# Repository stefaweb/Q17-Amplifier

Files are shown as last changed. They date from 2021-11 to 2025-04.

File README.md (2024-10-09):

# Q17 : A QUAD405 audiophile MOSFET amplifier
Q17 is an amplifier based on the QUAD405 current dumping principle.

The project for porting the operating principle of the QUAD405 to a MOSFET base was originally created by engineer Tiberiu Vicol.

Use KiCad 8.0 or later to open and edit source files. KiCad 8.0 can be <a href="https://www.kicad.org/download/">downloaded</a> from CERN.

<b>Q17-Mini project 3.0 (90W @ 8 Ohms)</b>

The first version of the board was released on December 8, 2021.

Version 3.0.4 was published on October 7, 2024.

All files are located in Q17-Mini-3.0 directory. Old version are located in Q17-Mini Archives directory.

Q17-Mini v3.0 (95x75mm, 2 Oz PCB)
Q17-Mini-3 0-wood

<b>Q17-TURBO project (150W @ 8 Ohms)</b>

The natural evolution of the Q17-Mini, this time with two pairs of power transistors, better thermal management, better technical characteristics and the same sound signature with more punch.

An amplifier that will warm up even the coldest speakers.

The first version of the board was released on January, 6 2023.

Version 2.0.1 was released on October 5, 2024.

All files are located in Q17-TURBO-2.0 directory. Old version are located in Q17-TURBO Archives directory.

Q17-TURBO v2.0 (190x75mm, 2 Oz PCB)
Q17-Turbo-V2_wood

You can very simply manufacture your PCB via JLCPCB (https://jlcpcb.com) or PCBWay (https://www.pcbway.com) using the Gerber files available on this repository. You can also contact me, from time to time I have some spare copies of the Q17 PCBs that can be sold to you at cost price.

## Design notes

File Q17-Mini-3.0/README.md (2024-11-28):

# Q17-Mini version 3.0 (90W @ 8 Ohms)</b><br>

Q17-Mini-3 0-wood

<b>Technical specifications:</b>

THD: 0.011%<br>
S/N : 102 dB<br>
Intermodulation distortion: 0,2%<br>
Frequency response: ±0,2 dB<br>
Damping factor : 350 with 1.2Vrms sensibility, 290 with 0.7Vrms sensibility<br>
Default gain: 22 with input gain at 1.2Vrms, 35 with input gain at 0.7Vrms.<br>
DC offset at output: 1mV with OPA1611, 0mV with OPA828.<br>
Power supply : 50Vdc<br>
Idle consumption: 9W

These measurements were made with amateur measuring equipment. It is better to take them as an indication than as safe values. 
<br>
<br>
The first version of the board was released on December 8, 2021.
<br>
<br>
Version 3.0.4 was published on October 7, 2024.

Read the CHANGELOG file to know what's new.

<a href="https://audio.cyberkata.org/Q17-Mini-3.0-BOM.html">Q17-Mini-3.0-BOM Online Version</a>
<br>
<br>
<a href="https://www.mouser.fr/ProjectManager/ProjectDetail.aspx?AccessID=dd2b71abab">Order Q17-Mini-3.0.4-BOM at Mouser</a><br> 
<br>

Q17-Mini-3 0-stereo

Q17-Mini-schematic

Q17-Mini-3 0-spectrum

Q17-Mini-3 0_band

Q17-Mini-3 0_sweep_1W_configA4

PCB size: 95 mm * 75 mm

Q17-Mini-3D-FRONT

Q17-Mini-3D-BACK

Q17-Mini-PCB-FRONT

Q17-Mini-PCB-BACK

Drilling for Q17-Mini
Drilling diagram Q17-Mini v3

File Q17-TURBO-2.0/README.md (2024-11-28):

# Q17-TURBO (P2) 2.0</b><br>

<b>Q17-TURBO project (150W @ 8 Ohms).</b><br>

The natural evolution of the Q17-Mini, this time with two pairs of power transistors, better thermal management, better technical characteristics and the same sound signature with more punch.

An amplifier that will warm up even the coldest speakers.

<b>Technical specifications:</b>
</b>
THD: 0.01%<br>
S/N : 102 dB<br>
Intermodulation distortion: 0,2%<br>
Frequency response: ±0,2 dB<br>
Damping factor : 300<br>
Default gain: 26 with input gain at 1.2Vrms.<br>
DC offset at output: 1mV with OPA1611, 0mV with OPA828.<br>
Power supply : 60Vdc (56-60V)<br>
Idle consumption: 13W

These measurements were made with amateur measuring equipment. It is better to take them as an indication than as safe values.

The first version of the board was released on January, 6 2023.

Version 2.0.1 was released on October 5, 2024.

Read the CHANGELOG file to know what's new.

All files are located in Q17-TURBO-2.0 directory. Old version files are located in Q17-TURBO Archives directory.

KiCad source - Q17-TURBO amplifier KiCad source files.<br>
Gerber-Q17-TURBO-[version].zip - production gerber files for Q17-TURBO amplifier.<br>
Q17-TURBO-schematic.pdf - schematic for Q17-TURBO amplifier.<br>
Q17-TURBO-BOM.html - interactive BOM for Q17-TURBO amplifier (to open with an Internet Navigator).<br>

<a href="https://audio.cyberkata.org/Q17-TURBO-BOM-2.0.html">Online Q17-TURBO-BOM-2.0</a><br>

<a href="https://www.mouser.fr/ProjectManager/ProjectDetail.aspx?AccessID=c6a0dfc411">Order Q17-TURBO-BOM-2.0-BOM at Mouser</a><br> 



Q17-TURBO-schematic

Q17-Turbo-2 0_spectrum-2 0 1

PCB size: 190 mm * 75 mm

Q17-TURBO-3D-FRONT

Q17-TURBO-3D-BACK

Q17-TURBO-PCB-FRONT

Q17-TURBO-PCB-BACK

Q17-TURBO-PCB

Mounting Plate for Q17-Turbo

216 x 80 mm

Fixing Plate-Q17-Turbo-216x80-1 0

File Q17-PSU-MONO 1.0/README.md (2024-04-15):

# Q17-PSU-MONO version 1.0<br>

Universal mono bridge Power Supply for Class B amplifiers.

Version 1.0 published on April 15, 2024.

<a href="https://audio.cyberkata.org/Q17-PSU-MONO-BOM.html">Online Q17-PSU-MONO-BOM</a><br>

Q17-PSU-MONO-3D-VIEW

Q17-PSU-MONO-SCHEMATIC

Q17-PSU-MONO-3D-TOP

Q17-PSU-MONO-PCB-FRONT

Q17-PSU-MONO-PCB-BACK

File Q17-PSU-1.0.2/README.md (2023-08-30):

# Q17-PSU version 1.0.2<br>

Universal Power Supply for Class B amplifiers.

Version 1.0.2 published on August 29, 2023.

<a href="https://audio.cyberkata.org/Q17-PSU-BOM.html">Online Q17-PSU-BOM</a><br>



Q17-PSU-3D

Q17-PSU-schematic

Q17-PSU-PCB-FRONT

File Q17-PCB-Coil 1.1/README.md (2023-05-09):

# Q17-PCB-Coil 1.1</b><br>
<br>
PCB coil 1.2uH based on Tibi footprint version L_17.3.<br>

pcb_coil_1 2uH

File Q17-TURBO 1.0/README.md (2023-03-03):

# Q17-TURBO (P2) 1.0</b><br>

<b>For the Q17-TURBO project (200W @ 8 Ohms).</b><br>

The natural evolution of the Q17-Mini, this time with two pairs of power transistors, better thermal management and the same technical characteristics and the same sound signature.

THD: 0.013%<br>
THD+N: 0.10%<br>
Gain: 25<br>
DC offset at output: 0.001v<br>
Power supply: 50-55vDC<br>
Idle consumption: 15W @ 240v<br>

<br>
The first version of the board was released on January, 6 2023.<br>
<br>
<br>
All files are located in Q17-TURBO directory:<br>
<br>
KiCad source - Q17-TURBO amplifier KiCad source files.<br>
Gerber-Q17-TURBO-[version].zip - production gerber files for Q17-TURBO amplifier.<br>
Q17-TURBO-schematic.pdf - schematic for Q17-TURBO amplifier.<br>
Q17-TURBO-BOM.html - interactive BOM for Q17-TURBO amplifier (to open with a Navigator).<br>
Q17-TURBO-Drilling.jpg - Drilling plan for heatsink.<br>
<br>
<a href="https://audio.cyberkata.org/Q17-TURBO-BOM.html">Q17-TURBO-BOM Online Version</a><br>
<br>

Q17-Turbo_top jpeg

Q17-Turbo_back

q17_on

Q17-TURBO-schematic

Q17-Turbo-THD2

Q17-TURBO-PCB-FRONT

Q17-TURBO-PCB-BACK

Q17-TURBO-PCB

Q17-TURBO-Drilling

PCB size: 190 x 75 mm, 2 Oz
Q17-TURBO-1 0

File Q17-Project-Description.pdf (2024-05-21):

Q17 - audiophile approach to perfect sound

Hard to prove statements:
I know what I saw ! Ufologist I know what I hear ! Audiophile

by audiophile Tiberiu Vicol & ChatGPT This document was updated on 09.May.2023

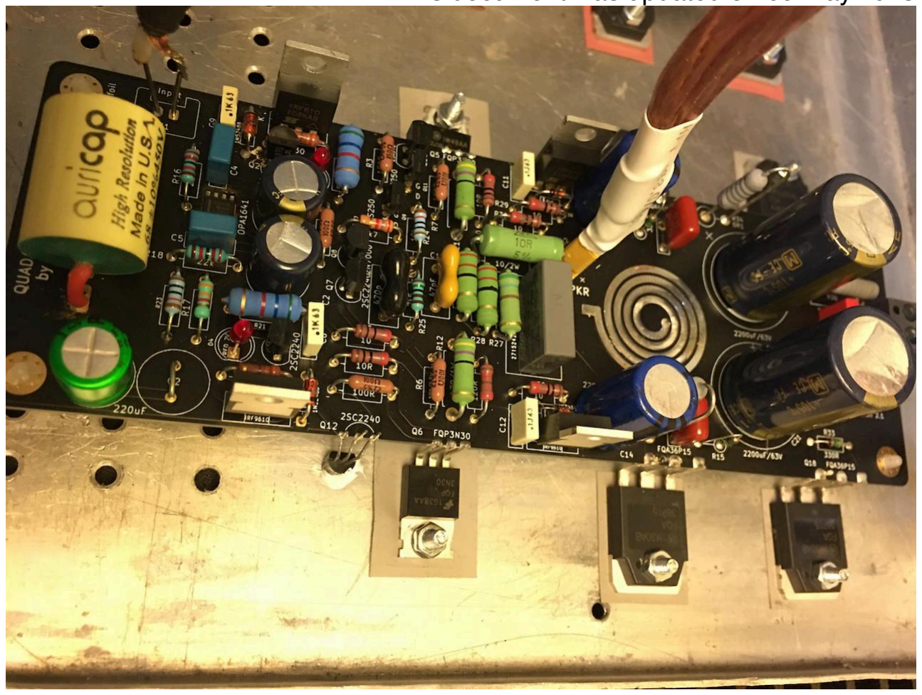
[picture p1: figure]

Introduction:

Q17 is a class B amplifier based on the current dumping principle.

Initial technical requirements:

- Stable operation: The amplifier must remain stable under any operational condition, with no oscillation.
- Minimum 100W in 8ohm at 1kHz: This should be sufficient for audiophiles with "impossible to drive" speakers.
- Frequency response cutoff of 10Hz - 100kHz: This will allow for a decent slew rate.

- IMD (Inter-Modulation Distortion) under 0.01%
- THD (Total Harmonic Distortion) under 0.01% at 1W and full power
- Design must be affordable, using readily available THT or SMD components or equivalents.
- Cost-effective and easy to build: High-end audio must be affordable.
- Open source: Let's offer everything - schematic, simulation, source PCB files, and bill of materials.
- Designed using LTspice simulation with final touch by extensive bench measurements and testing. Starting with KiCad 6.0.2, ngspice simulation is possible, and files have been made available by Holger Vogt: https://forum.kicad.info/t/simulation-examples-foricad-eeschema-ngspice/34443 (https://forum.kicad.info/t/simulation-examples-for-icad-eeschema-ngspice/34443)
- Final design decisions are always made using my platinum
ears. ;-) This means that Q17 is designed by comparing different topologies, and the final decision is taken not by measurement, but by listening. Q17 is indeed designed by ear. :-D

And here are the on-ear requirements:

Sound quality is of paramount importance. The amplifier must sound excellent at any level, without causing listening fatigue. The sound must be vivid, with a full body and plenty of harmonics with long decay, while maintaining resolution and clarity from top to bottom. Each instrument must sound natural, clearly separated, and easy to locate in space, even in large orchestras.

- No hiss or buzz: Poor rectification and filtering may result in unwanted noise.
- Microdynamic: This is challenging. The rhythm must be clear and distinct at any volume. I don't want flat, compressed, or lifeless sound. This is often related to negative feedback (NFB). In my opinion, NFB is only partially true, and it largely depends on how it is used along with other factors. High-quality power supply filter capacitors may also help.
- Macrodynamic linearity: The amplifier must be capable of going from low to high power levels instantly, without distortion or compression. It must provide the feeling of unlimited power. This is mainly related to the power supply. If the amplifier is capable of delivering power, the power supply must be able to handle it as well.

- Resolution: I prefer an amplifier that offers both resolution and fullbodied instruments, without losing harmonics and decay. Welldesigned single-ended direct-heated triodes (SEDHT) are capable of achieving this, and I want the same from my amplifier. I know this is another challenging requirement. Intermodulation distortion plays a role here. Low IMD always leads to top resolution, but sometimes musicality can be lost.

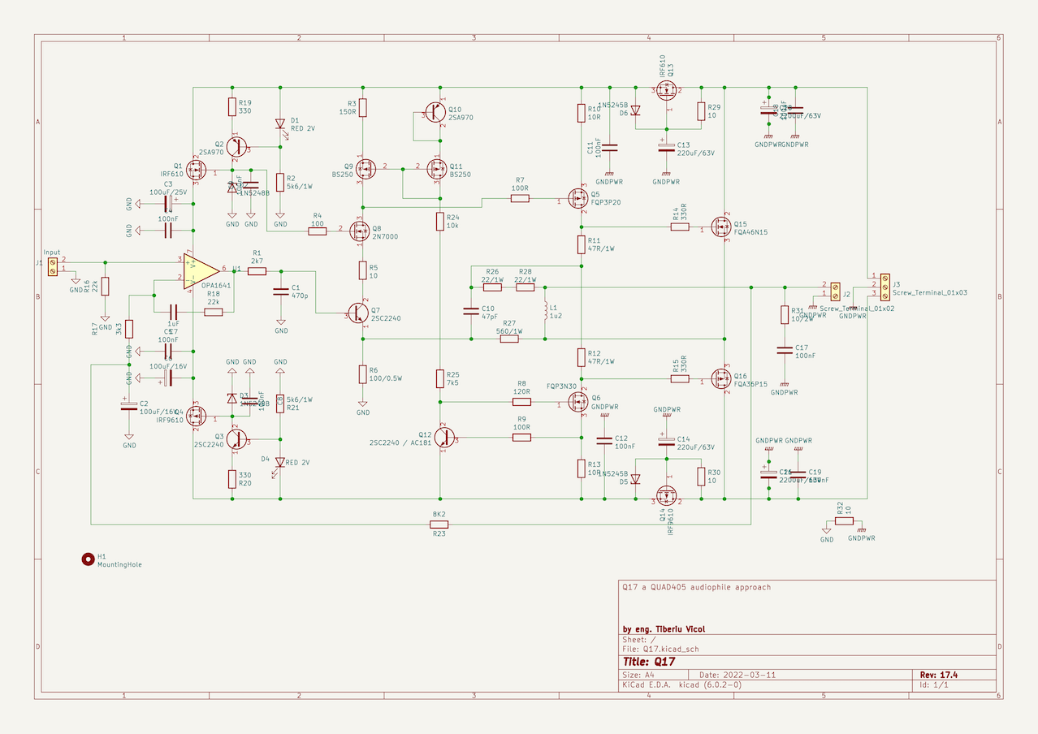
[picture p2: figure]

Q17 with output single pair of Fairchild’s

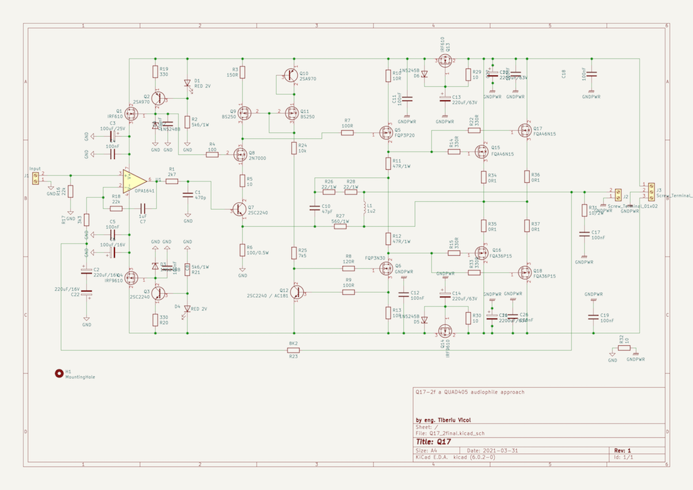
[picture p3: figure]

Q17 with output double pair of Fairchild’s

## Functional Description:

### Q17 is designed to deliver music at the highest audio performance, and

this design does not follow the "amplifier design book." Intentionally,

### the input is DC coupled, it has no input LPF, and does not make use of diodes or Vbs multiplier for thermal compensation. Q17 will run in class B, even though the output devices are MOSFETs with a very high Vgs

threshold. As far as I know, this has never been attempted before.

### Please correct me if I'm wrong. Q17 is divided into two separate

sections, which we will call Section One and Section Two.

Section One is made with the operational amplifier OPA1641. Today,

OPA1641 is one of the best opamps on the market. In fact, it is so good that a discrete circuitry will barely come close. OPA1641 is a JFET input operational amplifier that, apart from technical specifications, sounds very good and is cost-effective too. We are not driving a low impedance output, and there are no thermal issues. Those who do not like JFET

sound may try LME49990. This sounds great as well.

In my humble opinion, phase accuracy is very important. Therefore,

Q17 is not inverted and will preserve the original phase of the signal.

The input impedance is given by R16 = 22K. This is a good trade between high impedance and thermal resistor noise. You want higher input impedance? You can go as high as 47K. Use a good metal foil resistor here, and it should be enough. R17 and R18 are part of operational negative feedback and will set the gain to (R17+R18)/ R17=7.6. Many operational amplifiers will not be stable at low gain, and the stability limit is usually at a gain higher than 5. 7.6 will offer good

sensitivity, and we are on the safe side, away from any oscillation.

### Through R30, R25, and C3, the input operational will have a second role, acting as a DC servo. C3 must be bipolar, and I recommend using a good one like Nichicon MUSE. However, two normal polarized electrolytics connected in series will work just fine. For this use, low-

voltage electrolytics in the range of 6.3V-10VDC.

### R1C1 forms a low-pass filter with a cutoff frequency of 125kHz. This RC filter is the main load for the operational and will also limit the whole

amplifier's full bandwidth. C1 must be silver-mica or polystyrene.

### The operational is fed by two "reasonably low noise" regulators. The operational will not draw more than 10mA per raw, but its sonic

performance is highly dependent on the quality of these regulators. So,

### I have invested some time and parts to get the best topology for sound

versus price compromise.

Here is how it works. Regulation is ensured by 18V zeners D2 and D3, which are fed by a constant current source at around 4.2mA. Q2, D1,

### R19, and R2 (respectively Q3, D4, R20, and R21 for the negative rail) form a simple current source. D1 and D4 are red LEDs with Vf~2V. It is well-known that an LED is a reliable low-noise voltage reference. The current through the zener diode will be (LedVf-Q7Vbe)/R19 = (2-0.6)/330

= 4.2mA. This reference voltage is used by two MOSFETs, Q1 and Q4,

### respectively, to deliver higher current to OPA1641. IRF610/IRF9610 are a bit overkill here but are easy to find and cheap enough. These will run

warm but do not need a heatsink.

### Here is one of my first audiophile observations: MOSFET regulators sound better than bipolar regulators. They do not measure better, but

they sound better.

### Section two starts with a cascode formed by Q7 and Q8. This stage offers high gain, high output impedance, and high open-loop bandwidth

and may be a challenge to keep it out of oscillation. For this reason, R5 is there. This will lower the gain and increase stability at the cost of some distortion. In place of Q7, some inexpensive transistors BC5xx/ BC8xx can be used, as maxVce > 45V is the only restriction. From a sonic point of view, some cascodes may kill the "soul of music," in other words, offer a less vivid sound. Things are going far better if you use a MOSFET as the top active device. This will preserve dynamics at

any level.

### The cascode - Q7 & Q8 - stage has a high output impedance, therefore

it is fed by a constant current source made by Q10 and R3 at approx.

### 4.5mA. Q10 can be any low-cost, high-beta PNP BJT. Yes, any PNP, no

constraints.

### The CCS current is mirrored to Q12 by Q9 & Q11 through R24 & R25. In fact, the heart of Q17 is around this CCS+ current mirror. A current mirror that can be made with high-beta PNP transistors or P-channel MOSFET. You may need to pair these transistors to have same Vbe or

Vgs at ˜5mA.

I tried both. BJT mirror is very precise and offers a lush sound. For MOSFET, I used BS250P, and in this case, sound is deeper with a better midrange. Micro-dynamics seem to be higher too. After extensive listening sessions and some burn-in, I can confidently say that I will stay with MOSFET mirror. Take care of BS250P numbering termination as

this is different for manufacturers - see Vishay and Diodes.

### Instead of R24 & R25, you may use a single 1W resistor. This was split

in two to distribute power dissipated.

### Next is a class A stage. Here a single modern high-transconductance

MOSFET will do an excellent job, at the cost of some input capacitance.

### MOSFETs create more even-order harmonics compared to bipolar's too. As I care more about harmonic content than THD, here is my

preference for MOSFET.

### The quality of these MOSFETs may dramatically influence the amplifier's sonic signature, and these have been chosen after long

listening sessions.

### The P-channel MOSFET Q5 is a class-A active device, and from my observation, the P-channel FQP3P20 is slightly more linear than the Nchannel FQP3N30. However, at the current time (2021), we do not have

too many options. Toshiba's lateral MOSFETs (2SJ76, 2SJ77, 2SJ78,

### 2SJ79, and 2SK213, 2SK214, 2SK215, 2SK216) have long been obsolete. If you can source them, use them, but don't set your

expectations too high. These will not sonically exceed the FQP's.

### However, if you do use them, some capacitor compensation may be

needed to keep them from oscillating.

Q5 is fed by a 60mA CCS formed by Q12 and Q6. Q12 Vbe is the main reference in this CCS and can be used as thermal compensation for the final stage too. Again, there are no constraints for Q12. It can be any high-beta, low-voltage, NPN BJT. The CCS current can be calculated by Q12Vbe/R13 and would be around 60mA. This will push Q5's operation in class A and offer enough juice to drive the final dumper stage. Q5 and Q6 will dissipate 3W and must be mounted on a

heatsink.

### Q12 must also be mounted on a heatsink as it will be used to

compensate for final stage thermal runaway.

### Changing R13 to 2 ohms, a germanium AC181 can be used here as better temperature compensation. I must mention that this mod will not bring "germanium sound" into this amplifier. Sorry, germanium lovers!

### R9 is there as a base stopper and to avoid any possible oscillation. R7

and R8 are gate stoppers too.

### The Q17 amplifier runs in class B. There is no bias needed, and the Q17

amplifier may accept a very wide range of output MOSFET transistors.

Choosing the final pair Q15 & Q16.

I'm a big fan of lateral MOSFETs made by Semelab-Semefab-Exicon-Magnatec, whatever company is behind. This Scottish company is one of the last to make very good high-power lateral MOSFETs. I proudly used them in many amplifiers, and they sound exceptional. The main goal of Q17 is to be affordable, and these laterals, like many other good things, are not so cheap. They are very rugged and allow a high level of

"torture" and make things sometimes easy. No protections are needed.

### But... there is a "but." They have a small transconductance. You need to use double die and parallel a few of them to get some decent transconductance because audiophile speakers make use of

### complicated crossovers that like a lot of current in the most unexpected

frequencies.

Fairchild, now ON Semiconductor, was a great company and one of their legacies is FQA46N15 and FQA36P15. If you think these are P/N pairs, you are wrong. There is no such P/N perfect match in the real world, but we can choose the closest ones. These are marketed as "Fairchild Semiconductor's proprietary planar stripe and DMOS technology," with a small remark that they may be suitable for audio

amplifiers as well.

### FQA46N15 has a regular transconductance of 36 Siemens, while Exicon double die ECW20N20 has a maximum of 4 Siemens. This is equivalent to 9 double die laterals. Yes, very impressive! FQA36P15 has a regular transconductance of 19.5 Siemens, while Exicon double die ECW20P20

has a maximum of 4 Siemens. This is equivalent to 4 double die laterals.

In the "dark side" of Mouser, some beasts may leave these Fairchild's in the dust. These are made by IXYS, and a pair could be IXFK220N20X3 and IXTK120P20T. These exhibit over 120 Siemens of transconductance and are capable of transforming your amplifier into a real welding machine. No joke at all. If your speakers have never been

moved before, use a pair of these and shake your world, your walls, your neighbor...

### Through R11 and R12, these devices will be biased near class A operation. Both FQA46N15 and FQA36P15 have a Vgs - threshold voltage between 3V and 4V. I found that the P channel FQA36P15 will

open around 3V, while the FQA46N15 will need 100mV-300mV more.

### (To have both running at the same level, R11 may be increased to 51ohm or more.)

### Obviously, Q15 and Q16 must be mounted on a large heatsink. R31C17 is the well-known Zobel filter. C17 quality is important. Use a good propylene or polystyrene capacitor here. My preference is polystyrene Multicap RTX series. If you do not want to invest too much, go for

Arcotronix.

### R26, R27, R28, C10, and L1 form the current dumping bridge. R27 and R6 are part of section 2 negative feedback. This sets the entire amplifier gain to [(R17+R18)/R17]x[{R27+R6)/R6]=45.6, enough for the amplifier

to reach 100W/8ohm at 0.7V input.

### Q13 and Q14 are capacitor multipliers and are there to reduce power supply ripple. (These are not needed if you use synchronous rectification - see below.) During power on, the gate to source voltage on Q13 and Q14 may easily exceed 10V and may damage these

MOSFETs. For this reason, D5 and D6 are there to protect.

### You may have noticed that there are R4, R7, R8, R9, R14, and R15 as gate or base stoppers. I always prefer gate stoppers to compensate with capacitors. R32 will separate the signal ground plane from the

power ground plane. There are no special requirements for this one.

### Please note that R32 is 0ohm and not 10ohm as in presented

schematic.

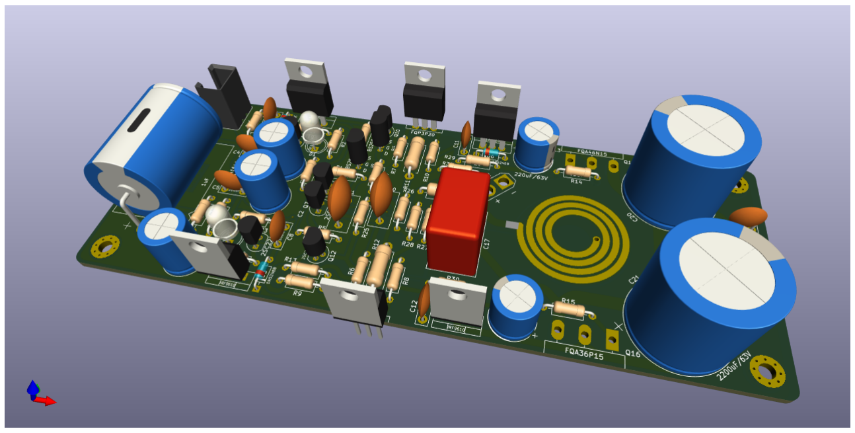
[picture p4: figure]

PCB design

During the COVID-19 lockdown, I had enough time to learn KiCad. KiCad runs on any operating system and is open source. This offers flexibility, scalability, and security. KiCad is a great tool.
I have designed this project in KiCad 5.99-nightly. To open the files, you need at least 5.99. This is already compatible with the upcoming KiCad 6, which is a huge step forward.
I opted for separate small and high signal ground planes. Ground planes are a good solution to avoid ground loops and offer excellent EMI reduction. For the best noise reduction, small signal GND makes use of top and bottom ground planes.
The PCB embeds an L1 inductor that is part of the error correction bridge. This will ensure good tolerance and optimal geometric design.

Yes, a PCB inductor will have the right shape for a near-to-ideal inductor. The truth is that I'm lazy to wire-wind coils. Having this embedded in the PCB will help lazy people like me a lot, but what I said earlier is still valid. A PCB coil is better. In a separate document, I have detailed how to create and embed inductors in KiCad.
The PCB offers the option to install several C7 types. Use propylene at any voltage > 50V. C17 must be propylene, preferably FKP, or polystyrene at a voltage > 100V.
OPA1641 is the single SMD part, and the PCB does not offer the option to install a THT one. But as long as I offer the source files for this project, you are invited to modify and redesign as you wish.

Bill of materials for Q17

D1,4 - LED RED 2V - https://ro.mouser.com/ProductDetail/Vishay-Semiconductors/TLHR5200?qs=GMckgg3bfZPthGr1cDR0RA%3D%3D (https://ro.mouser.com/ProductDetail/Vishay-Semiconductors/TLHR5200?qs=GMckgg3bfZPthGr1cDR0RA%3D%3D) D2,3 - 1N5248B - https://ro.mouser.com/ProductDetail/ON-Semiconductor-Fairchild/1N5248B?qs=G5AQjGfRJcJY58VFTX%252BkdQ%3D%3D (https://ro.mouser.com/ProductDetail/ON-Semiconductor-Fairchild/1N5248B?qs=G5AQjGfRJcJY58VFTX%252BkdQ%3D%3D)
D5,6 - 1N5245 - https://ro.mouser.com/ProductDetail/ON-Semiconductor-Fairchild/1N5245BTR?qs=jumAldekxNAufOthuRVeGQ%3D%3D (https://ro.mouser.com/ProductDetail/ON-Semiconductor-Fairchild/1N5245BTR?qs=jumAldekxNAufOthuRVeGQ%3D%3D)
Q7,12 - KSC1845 - https://ro.mouser.com/ProductDetail/ON-Semiconductor-Fairchild/KSC1845FTA?qs=UMEuL5FsraDCmxWozTypUA%3D%3D (https://ro.mouser.com/ProductDetail/ON-Semiconductor-Fairchild/KSC1845FTA?qs=UMEuL5FsraDCmxWozTypUA%3D%3D)
Q8 - 2N7000 - https://ro.mouser.com/ProductDetail/ON-Semiconductor-Fairchild/2N7000TA?qs=iN0KuJO79KZfCWVKA48bEg%3D%3D (https://ro.mouser.com/ProductDetail/ON-Semiconductor-Fairchild/2N7000TA?qs=iN0KuJO79KZfCWVKA48bEg%3D%3D)
Q2,Q10 - KSA992 - https://ro.mouser.com/ProductDetail/ON-Semiconductor-Fairchild/KSA992FBTA?qs=BiJXFBt7cx0C7PSFUPmr1w%3D%3D (https://ro.mouser.com/ProductDetail/ON-Semiconductor-Fairchild/KSA992FBTA?qs=BiJXFBt7cx0C7PSFUPmr1w%3D%3D)
Q9,11 - BS250P - https://ro.mouser.com/ProductDetail/Diodes-Incorporated/BS250P?qs=OlC7AqGiEDnRUFCQhRDfhA%3D%3D (https://ro.mouser.com/ProductDetail/Diodes-Incorporated/BS250P?qs=OlC7AqGiEDnRUFCQhRDfhA%3D%3D)
Q1,13 - IRF610 - https://ro.mouser.com/ProductDetail/Vishay-Siliconix/IRF610PBF-BE3?
qs=%2Fha2pyFadugbZUitPAu%252BTEPjT5SopLZ8qDnf9IMIvY8%3D (https://ro.mouser.com/ProductDetail/Vishay-Siliconix/IRF610PBF-BE3) Q4,14 - IRF9610 - https://ro.mouser.com/ProductDetail/Vishay-Semiconductors/IRF9610PBF?qs=cvaI6ThkwxtWoLkQbU%2FdsA%3D%3D (https://ro.mouser.com/ProductDetail/Vishay-Semiconductors/IRF9610PBF?qs=cvaI6ThkwxtWoLkQbU%2FdsA%3D%3D) Q5 - FQP3P20 - https://ro.mouser.com/ProductDetail/onsemi-Fairchild/FQP3P20?qs=mdiO5HdF0Ki1WoTNCOatYg%3D%3D (https://ro.mouser.com/ProductDetail/onsemi-Fairchild/FQP3P20?qs=mdiO5HdF0Ki1WoTNCOatYg%3D%3D)
Q6 - FQP3N30 - https://ro.mouser.com/ProductDetail/onsemi-Fairchild/FQP3N30?qs=FOlmdCx%252BAA1dVHDhvU%252BUcw%3D%3D (https://ro.mouser.com/ProductDetail/onsemi-Fairchild/FQP3N30?qs=FOlmdCx%252BAA1dVHDhvU%252BUcw%3D%3D)
Q15 - FQA46N15 - https://ro.mouser.com/ProductDetail/ON-Semiconductor-Fairchild/FQA46N15?
qs=%2Fha2pyFaduimCeOyuw0xouriGUKJcVVjoz%2FqQ0BKQtc%3D (https://ro.mouser.com/ProductDetail/ON-Semiconductor-Fairchild/FQA46N15) Q16 - FQA36P15 - https://ro.mouser.com/ProductDetail/ON-Semiconductor-Fairchild/FQA36P15?
qs=%2Fha2pyFadugPFcM3hvKrsP2cJsnMpKcpv1XDSGf5JCo%3D (https://ro.mouser.com/ProductDetail/ON-Semiconductor-Fairchild/FQA36P15)

U1 - OPA1641 - https://ro.mouser.com/ProductDetail/Texas-Instruments/OPA1641AIDR?
qs=sGAEpiMZZMutXGli8Ay4kFRPeV04IrZfqfNgaiEGnmE%3D (https://ro.mouser.com/ProductDetail/Texas-Instruments/OPA1641AIDR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)

C17 - 100nF - https://ro.mouser.com/ProductDetail/KEMET/R76MI31005050J?qs=pUKx8fyJudAaVipAdJ8Rqw%3D%3D (https://ro.mouser.com/ProductDetail/KEMET/R76MI31005050J?qs=pUKx8fyJudAaVipAdJ8Rqw%3D%3D) C4,5,8,9,11,12,18,19 - 100nF - https://ro.mouser.com/ProductDetail/KEMET/PHE426DJ6100JR05?qs=PoZJcSwa6DzVkLIswxOBtw%3D%3D (https://ro.mouser.com/ProductDetail/KEMET/PHE426DJ6100JR05?qs=PoZJcSwa6DzVkLIswxOBtw%3D%3D)
C10 - 47pF - https://ro.mouser.com/ProductDetail/Cornell-Dubilier-CDE/CD15ED470JO3?qs=JlSiUoO6twmzsCndHIj%2FhA%3D%3D (https://ro.mouser.com/ProductDetail/Cornell-Dubilier-CDE/CD15ED470JO3?qs=JlSiUoO6twmzsCndHIj%2FhA%3D%3D)
C7 - 1uF - https://ro.mouser.com/ProductDetail/Cornell-Dubilier-CDE/930C1W1K-F?qs=oi6qnwyrdkzUKQFAck35kQ%3D%3D (https://ro.mouser.com/ProductDetail/Cornell-Dubilier-CDE/930C1W1K-F?qs=oi6qnwyrdkzUKQFAck35kQ%3D%3D)
C1 - 470pF - https://ro.mouser.com/ProductDetail/Cornell-Dubilier-CDE/CD15FD471JO3F?qs=FKrQhPEeH%252B6Y%2FhdJiMfeDw%3D%3D (https://ro.mouser.com/ProductDetail/Cornell-Dubilier-CDE/CD15FD471JO3F?qs=FKrQhPEeH%252B6Y%2FhdJiMfeDw%3D%3D) C2 - 100uF BP - https://ro.mouser.com/ProductDetail/Nichicon/UES1C101MPM1TD?qs=JgOBn5pVFoqelxyCFlUB6Q%3D%3D (https://ro.mouser.com/ProductDetail/Nichicon/UES1C101MPM1TD?qs=JgOBn5pVFoqelxyCFlUB6Q%3D%3D)
C3,6 - 100uF/25V - https://ro.mouser.com/ProductDetail/Vishay-Sprague/510DX107M025CC2D?qs=j9BvaggtyN3XWy0%2FfD7iig%3D%3D (https://ro.mouser.com/ProductDetail/Vishay-Sprague/510DX107M025CC2D?qs=j9BvaggtyN3XWy0%2FfD7iig%3D%3D) C13,14 - 220uF/63V - https://ro.mouser.com/ProductDetail/Vishay-BC-Components/MAL215058221E3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 (https://ro.mouser.com/ProductDetail/Vishay-BC-Components/MAL215058221E3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) C15,16,20,21 - 2200uF/63V - https://ro.mouser.com/ProductDetail/Nichicon/UPW1J222MHD?
qs=sGAEpiMZZMvwFf0viD3Y3V%252BktQc2dZjNU8%252BcKz5%2FjOU%3 D (https://ro.mouser.com/ProductDetail/Nichicon/UPW1J222MHD)

R1 - 2k7 - https://ro.mouser.com/ProductDetail/Vishay-Dale/CCF072K70JKE36?qs=QKEOZdL6EQrf8lXj1m%2FHqg%3D%3D (https://ro.mouser.com/ProductDetail/Vishay-Dale/CCF072K70JKE36?qs=QKEOZdL6EQrf8lXj1m%2FHqg%3D%3D) R2,21 - 5k6 - https://ro.mouser.com/ProductDetail/Vishay-BC-Components/PR01000105601JR500?qs=LCMWAU1DZcyMK8Yz0ZAhmQ%3D%3D (https://ro.mouser.com/ProductDetail/Vishay-BC-Components/PR01000105601JR500?qs=LCMWAU1DZcyMK8Yz0ZAhmQ%3D%3D) R24 - 10k - https://ro.mouser.com/ProductDetail/Vishay-Beyschlag/MBB02070C1002FRP00?qs=Jr4%2Ft4s12JUmAfKOFUNhig%3D%3D (https://ro.mouser.com/ProductDetail/Vishay-Beyschlag/MBB02070C1002FRP00?qs=Jr4%2Ft4s12JUmAfKOFUNhig%3D%3D) R3 - 150ohm - https://ro.mouser.com/ProductDetail/Vishay-Dale/CCF07150RJKE36?qs=Ad%252BIW%2FmDqmUeNbXSTmV5ZQ%3D%3D (https://ro.mouser.com/ProductDetail/Vishay-Dale/CCF07150RJKE36?qs=Ad%252BIW%2FmDqmUeNbXSTmV5ZQ%3D%3D) R5,10,13,29,30,32 - 10ohm - https://ro.mouser.com/ProductDetail/Vishay-Dale/CCF0710R0GKE36?qs=QKEOZdL6EQpP4bkfADZzbQ%3D%3D (https://ro.mouser.com/ProductDetail/Vishay-Dale/CCF0710R0GKE36?qs=QKEOZdL6EQpP4bkfADZzbQ%3D%3D) R4,6,7,9 - 100ohm - https://ro.mouser.com/ProductDetail/Vishay-Dale/CCF07100RJKE36?qs=NQWA6AwZmkMW4Ul%252BG32rNg%3D%3D (https://ro.mouser.com/ProductDetail/Vishay-Dale/CCF07100RJKE36?qs=NQWA6AwZmkMW4Ul%252BG32rNg%3D%3D) R8 - 120ohm - https://ro.mouser.com/ProductDetail/Vishay-Dale/CCF07120RGKE36?qs=QKEOZdL6EQrffKbi7vq1lg%3D%3D (https://ro.mouser.com/ProductDetail/Vishay-Dale/CCF07120RGKE36?qs=QKEOZdL6EQrffKbi7vq1lg%3D%3D)
R11,12 - 47ohm/2W - https://ro.mouser.com/ProductDetail/Vishay-Dale/CCF0247R0JKE36?qs=QKEOZdL6EQqc7KTqtOG%2FUA%3D%3D (https://ro.mouser.com/ProductDetail/Vishay-Dale/CCF0247R0JKE36?qs=QKEOZdL6EQqc7KTqtOG%2FUA%3D%3D) R16,18 - 22k - https://ro.mouser.com/ProductDetail/Vishay-Dale/CCF0722K0JKE36?qs=Ad%252BIW%2FmDqmUs0WVMJaSusw%3D%3D (https://ro.mouser.com/ProductDetail/Vishay-Dale/CCF0722K0JKE36?qs=Ad%252BIW%2FmDqmUs0WVMJaSusw%3D%3D)

R17 - 3K3 - https://ro.mouser.com/ProductDetail/Vishay-Dale/CCF073K30GKE36?qs=QKEOZdL6EQqcBZBx6GnZnQ%3D%3D (https://ro.mouser.com/ProductDetail/Vishay-Dale/CCF073K30GKE36?qs=QKEOZdL6EQqcBZBx6GnZnQ%3D%3D) R14,15,19,20,22 - 330ohm - https://ro.mouser.com/ProductDetail/Vishay-Dale/CCF07330RJKE36?qs=pkalMaiJWwv10%252BO%252BONxDWg%3D%3D (https://ro.mouser.com/ProductDetail/Vishay-Dale/CCF07330RJKE36?qs=pkalMaiJWwv10%252BO%252BONxDWg%3D%3D) R25 - 7K5 - https://ro.mouser.com/ProductDetail/Vishay-Dale/CCF077K50GKE36?qs=QKEOZdL6EQqRpabQIgr10Q%3D%3D (https://ro.mouser.com/ProductDetail/Vishay-Dale/CCF077K50GKE36?qs=QKEOZdL6EQqRpabQIgr10Q%3D%3D)
R23 - 8K2 - https://ro.mouser.com/ProductDetail/Vishay-Dale/CCF078K20GKE36?qs=QKEOZdL6EQrGlLmaSP0G2w%3D%3D (https://ro.mouser.com/ProductDetail/Vishay-Dale/CCF078K20GKE36?qs=QKEOZdL6EQrGlLmaSP0G2w%3D%3D)
R31 - 10ohm/2W - https://ro.mouser.com/ProductDetail/TE-Connectivity-Neohm/RR02J10RTB?qs=s1WWODT2SXW%252BZIrISq22ow%3D%3D (https://ro.mouser.com/ProductDetail/TE-Connectivity-Neohm/RR02J10RTB?qs=s1WWODT2SXW%252BZIrISq22ow%3D%3D) R26,28 - 22ohm - https://ro.mouser.com/ProductDetail/Vishay-Beyschlag/MBB02070C2209FCT00?
qs=sGAEpiMZZMsPqMdJzcrNwkfQgWkDJ%252BE2Mwj0n7JK2mo%3D (https://ro.mouser.com/ProductDetail/Vishay-Beyschlag/MBB02070C2209FCT00) R27 - 560ohm/1W - https://ro.mouser.com/ProductDetail/Ohmite/OM5615E-R58?
qs=sGAEpiMZZMukHu%252BjC5l7YREnR%2FWY87i1xVQq21Ltfa0%3D (https://ro.mouser.com/ProductDetail/Ohmite/OM5615E-R58)

J1 - input connector - https://www.hz-profishop.com/product_info.php?info=p701_mks-1651-6-0-202-s18--schwarz-.html (https://www.hz-profishop.com/product_info.php?info=p701_mks-1651-6-0-202-s18--schwarz-.html)
J2 - speaker output connector- https://ro.mouser.com/ProductDetail/DFRobot/FIT0586?qs=w%2Fv1CP2dgqouWR8IxqIK1w%3D%3D (https://ro.mouser.com/ProductDetail/DFRobot/FIT0586?qs=w%2Fv1CP2dgqouWR8IxqIK1w%3D%3D)
J3 - terminal block x 3 - https://ro.mouser.com/ProductDetail/Amphenol/TC0303620000G?qs=Mv7BduZupUgRMrlfdnWHCQ%3D%3D (https://ro.mouser.com/ProductDetail/Amphenol/TC0303620000G?qs=Mv7BduZupUgRMrlfdnWHCQ%3D%3D)

Extra parts for Q17-2f (Q17 amplifier with two output pairs)
R22, R33 - 330ohm https://ro.mouser.com/ProductDetail/Vishay-Dale/CCF07330RJKE36?qs=pkalMaiJWwv10%252BO%252BONxDWg%3D%3D (https://ro.mouser.com/ProductDetail/Vishay-Dale/CCF07330RJKE36?qs=pkalMaiJWwv10%252BO%252BONxDWg%3D%3D) R34,35,36,37 - 0.1ohm/3W https://ro.mouser.com/ProductDetail/TE-Connectivity-Holsworthy/ROX3SJR10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 (https://ro.mouser.com/ProductDetail/TE-Connectivity-Holsworthy/ROX3SJR10)
Q17 - FQA46N15 - https://ro.mouser.com/ProductDetail/ON-Semiconductor-Fairchild/FQA46N15?
qs=%2Fha2pyFaduimCeOyuw0xouriGUKJcVVjoz%2FqQ0BKQtc%3D (https://ro.mouser.com/ProductDetail/ON-Semiconductor-Fairchild/FQA46N15) Q18 - FQA36P15 - https://ro.mouser.com/ProductDetail/ON-Semiconductor-Fairchild/FQA36P15?
qs=%2Fha2pyFadugPFcM3hvKrsP2cJsnMpKcpv1XDSGf5JCo%3D (https://ro.mouser.com/ProductDetail/ON-Semiconductor-Fairchild/FQA36P15)

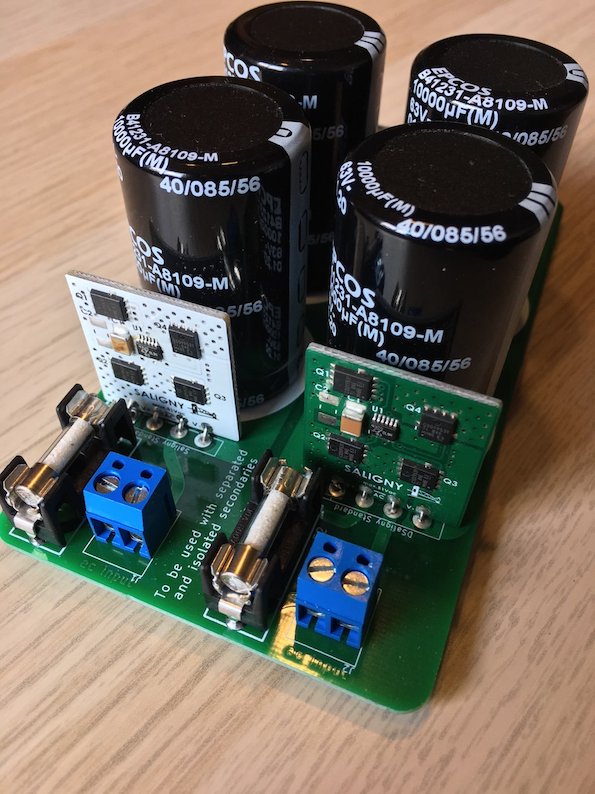
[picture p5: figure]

Active power supply

A good amplifier needs an exceptional power supply. All design efforts will be lost if we do not excel in this area too.

A diode is far from being a perfect device. There are no better devices, only better solutions.

Synchronous, or active rectification, has been available for a long time in professional appliances. The very first synchronous rectifier (mechanical rectifier) was used in the 1950s for high power and high voltage applications.

Its limited usage in consumer electronics was due to complexity and the very high cost involved. In recent years, thanks to green power requirements and electric vehicles, several dedicated chips have appeared in the consumer market. These mainly target PoE (power over Ethernet), but by choosing the right parts, the application can be extended to high-end audio as well.

A synchronous rectifier is a diode-less bridge employing modern MOSFET transistors that replace the four diodes in a full-wave bridge rectifier with a milliohm Rdson MOSFET, drastically reducing power dissipation, heat generation, voltage loss, and diode on/off switching noise. There is no P-N junction involved; only a low milliohm conductive channel is inserted in the power path. This allows for big current capability, better power management, less power loss, less dynamic impedance change versus load current, and better circuit performance than any available junction rectifier solution.

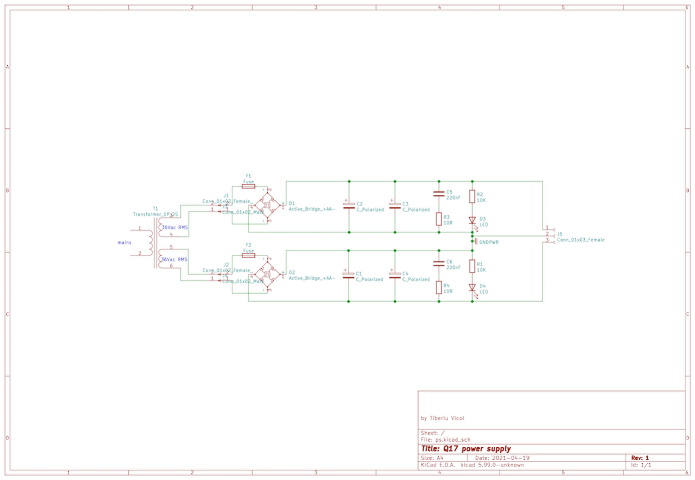
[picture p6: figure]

The advantage of using synchronous rectification is huge. While a normal diode has at least a 600mV drop at 1A, a low Rdson MOSFET will have as little as 3mV, or less, at the same 1A. This is 200 times better than a PN diode and at least 100 times better than a Schottky diode.

But how is this translated in audio? The most sensible difference is noise, due to synchronous rectifiers having negligible on/off noise. Each bridge MOSFET is acting like a soft on/off switch. The entire medium to top audio spectrum is cleaner. Voices are soft and cymbals full of harmonics. Another effect is better dynamics. The sound is more vivid because no power is lost in rectification or modulated by diode pn junctions, and the single current limiter is the intrinsic transformer resistance.

We make use of two Saligny Standard synchronous rectifiers made by Evotronix SRL. These are operated at 36Vac each, from a 300VA R-Core transformer. C1, C2, C3, C4 = 10000uF/63V are the main capacitor filters. There is a snubber formed with R3C5 and R4C6. This is needed only when normal diode bridge rectifiers are used. In our case with Saligny rectifiers, you may skip these parts. R2D3 and R1D4 are rail power indicators. A single power supply may be used for both Q17 modules, or two in case of a dual mono approach.

Bill of materials for power supply

J1,2 - terminal block x 2 - https://ro.mouser.com/ProductDetail/Amphenol/TC0203620000G?
qs=%2Fha2pyFaduhbuFfD6OHbCYxDpT0ma2Hwq0r2vPcUv6eC%2FlIp4UR n7Q%3D%3D (https://ro.mouser.com/ProductDetail/Amphenol/TC0203620000G)
J5,6 - terminal block x 3 - https://ro.mouser.com/ProductDetail/Amphenol/TC0303620000G?qs=Mv7BduZupUgRMrlfdnWHCQ%3D%3D (https://ro.mouser.com/ProductDetail/Amphenol/TC0303620000G?qs=Mv7BduZupUgRMrlfdnWHCQ%3D%3D)
C1,2,3,4 - 10.000uF/63V - https://ro.mouser.com/ProductDetail/EPCOS-TDK/B41231A8109M000?qs=f4aWRLuQiuxqY40YlReJiQ%3D%3D (https://ro.mouser.com/ProductDetail/EPCOS-TDK/B41231A8109M000?qs=f4aWRLuQiuxqY40YlReJiQ%3D%3D)
C5,6 - 220nF MKP - https://ro.mouser.com/ProductDetail/CDE-Illinois-Capacitor/MPX224K305E?qs=HXFqYaX1Q2wK3o1vUzHyKw%3D%3D (https://ro.mouser.com/ProductDetail/CDE-Illinois-Capacitor/MPX224K305E?qs=HXFqYaX1Q2wK3o1vUzHyKw%3D%3D) D1,2 - Synchronous Bridge - Saligny Standard - evotronix.eu
D3 - Red LED - https://ro.mouser.com/ProductDetail/Vishay-Semiconductors/TLHR5200?qs=GMckgg3bfZPthGr1cDR0RA%3D%3D (https://ro.mouser.com/ProductDetail/Vishay-Semiconductors/TLHR5200?qs=GMckgg3bfZPthGr1cDR0RA%3D%3D)
D4 - Green LED - https://ro.mouser.com/ProductDetail/Vishay-Semiconductors/TLHG5200?
qs=%2Fha2pyFadujruHm0H%252By%2FYe3hostfbxme%2F774XrUw9tU%3 D (https://ro.mouser.com/ProductDetail/Vishay-Semiconductors/TLHG5200)
R1,2 - - 10K/0,5W - https://ro.mouser.com/ProductDetail/Vishay-BC-Components/SFR16S0001002JA500?qs=H30XFsNYD%2FGypwPt5jX7ew%3D%3D (https://ro.mouser.com/ProductDetail/Vishay-BC-Components/SFR16S0001002JA500?qs=H30XFsNYD%2FGypwPt5jX7ew%3D%3D)
R3,4 - - 0 ohm - strap these if you use Saligny Standard
F1,2 - fuse holder - https://ro.mouser.com/ProductDetail/Littelfuse/0PTF0078P?qs=Co4VkB5J4%2Fsczy6gG8s%2FsA%3D%3D (https://ro.mouser.com/ProductDetail/Littelfuse/0PTF0078P?qs=Co4VkB5J4%2Fsczy6gG8s%2FsA%3D%3D) Transformer - *primary 2 x 115Vac region dependant* - secondary 36Vac + 36Vac at 5A

Selecting alternative parts
With current component shortage, it may happen that some parts listed in BOM to be unavailable, here are few alternative recommendations:
R16 - use a metal film resistor
C7 - use a good polypropylene made by Mundorf, Epcos, Vishay, CDC, U1 - following opamps can be used and will offer different sonic signatures: LME49710, LME49990, OPA604, OPA134, NE5534. Do not use TL071, TL081, LM301, LM741.
Q2 and Q3 - use transistors with Vce >= 65V & hFE>=100 : 2N5401 / 2N5551 Q7 and Q12 - other transistors that may be used are: KSC1845, 2N4401, BC546 / BC547 / BC548 / BC549 / BC550 - use the one with A termination for

Q7 and C termination for Q12.
C1 - this must be silver-mica or at least polystyrene.
Q1- KSA992, 2N4403, BC556C, BC557C, BC558C, BC559C, and BC560C C10 - silver-mica or ceramic NP0
R26, R27, R28 - these must be non-inductive resistors. MILLS make some good ones.
C17 - in this order: polystyrene, teflon, foil polypropilene, metalised polypropylene.
Q5 and Q6 - following pairs may be used with excellent performance: FQP3P50/FQP4N80; FQP4P40/FQP5N60
Q5 and Q6 - following pairs may be used with modest performance: IRF610/ IRF9610; IRF640/IRF9640; 2SJ76, 2SJ77, 2SJ78, 2SJ79 respectively 2SK213, 2SK214, 2SK215, 2SK216.
Q15,Q16,Q17,Q18 - following pairs can be used with modest performance IRFP9240/IRFP240; 2SJ201/2SK1530; 2SJ118/2SK413; 2SJ119/2SK414. Q9 and Q11 - Instead BS250 you may use ZVP3306A (https://ro.mouser.com/ProductDetail/Diodes-Incorporated/ZVP3306A?qs=vHuUswq2%252Bsyljxw%2Fl1wUQg%3D%3D)

Exicon ECW20N20 and ECW20P20 lateral MOSFET’s can NOT be used on this PCB. PCB need to be redesigned to accommodate lateral mosfet pinout.

Q17 Construction
Keep input shorted before any dc or static amplifier measurements. Static mean you only measure voltages in various places.
Start by installing operational and regulator with Q1-Q2-Q3-Q4. Next add Q13 and Q14 capacitor multipliers. Power up at and measure voltages before and after regulators. Before regulators you should measure +45Vdc/-46Vdc. After regulators you may expect around +13.5Vdc and -14Vdc
The two red LED, D1 and D4 must light on.
Mount the rest of parts, short input, power up and measure DC output. This must be under ~40mV.
Voltage across R3 and R13 must be between 500mV and 700mV. Voltage across R11 and R12 ~3V, a bit higher on R12.
If above measurements are OK, then you may connect Q17 amplifier to a preamplifier, potentiometer or volume controller. Connect output speakers trough a speaker protection module or a 3A fast fuse.
Take care and do not short the amplifier output. There is no protection, unless you have installed a separate one.
In some cases, a soft-start module is needed.

Building active power supply
For proper performance Q17 need a min.300VA transformer. There are E+I, C-core, R-core, Toroidal transformers. Any of them will work, but people ask which is the best. The best is the one that is the best constructed, using proper materials and well executed. However, from theoretical point of view, R-core exhibit lowest EM loss. A well executed R-core can be the best. Transformer must have dual separate secondary, 2 x 36Vac at min 5A.
Do not measure Saligny rectifiers without filter capacitors. Install all parts and measure when all is in place. Compared to any diode rectifier, Saligny rectifiers do not have voltage loss and you should get 36Vac x √2 = 50.9Vdc at active
Power supply output on each rail.

Measurements
Amplifier do not need specific adjustments and should work from the beginning. Please allow at least 48h for burn-in. Electrolytic capacitors are the most sensible at burn-in and some need 200h or more.
Mosfet transistors also need burn-in. My personal observation is that after 48h these are ok to go.
In order to perform burn-in, leave your amplifier powered ON. A musical program at low level will help as well.

What you should expect from this amplifier ?
Exceptional dynamics with superb harmonic extension. Strong and round bass. Exceptional midrange with crystal clear top response. Instrument separation localisation in deep 3D.
Enjoy & Thank you !

References and acknowledgements:
Current Dumping Audio Amplifier - PJ Walker - Wireless World, December 1975
Feedforward Error Correction in Power Amplifiers - Vanderkooy-Lipshitz Current dumping does it really work ? Theory and practice by J. Vanderkooy and S. P. Lipshitz University of Waterloo, Ontario
Current dumping analysis Class B amplifiers without crossover distorsion by H, S. Malvar, M. Sc. University of Brasilia
Test reports QUAD405 Current Dumping Amplifier by Gordon J. King Sources 101: Audio Current Regulator Tests for High Performance - Full Article by Walt Jung (https://audioxpress.com/authors/23384/walt-jung)

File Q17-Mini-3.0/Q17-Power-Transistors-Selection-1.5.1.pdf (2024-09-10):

Minimum Vds = 150V, same Vgs(th) range (4V), close transductance (Gfs). | Q7 v1.5.1
Config D2 | TESTED OK | | Status | Parts | Qg nC | Gfs Sie | Ciss pF | Vgs Volt | R7 | R8 | Freq MHz | R7 | R8 | Freq MHz | R7 | R8 | Freq MHz | OK | Comment
| Q5 | P | | FQPF7P20 | 25 | 3.5 | 770 | | 100 | | 2,06 | 93,95 | | 2,2 | 100 | | 2,2 | Yes
Q6 | N | EOL | 2SK3564 | 17 | 2.6 | 700 | 100 | 2,27 | 103,34 | 2,2 | 100 | 2,2 | Oscillation at 32V output with Q17-Turbo & S5.
Config D3 | TESTED OK | | Status | Parts | Qg nC | Gfs Sie | Ciss pF | Vgs Volt | R7 | R8 | Freq MHz | R7 | R8 | Freq MHz | R7 | R8 | Freq MHz | OK | Comment
| Q5 | P | | FQPF7P20 | 25 | 3.5 | 770 | | 100 | | 2,06 | 93,95 | | 2,2 | 100 | | 2,2 | Yes | Good with Q17-Turbo v2 & S5
| Q6 | N | | FQPF3N80C | 16.5 | 3 | 705 | | | 100 | 2,25 | | 108,55 | 2,2 | | 100 | 2,2 | | Overshoot with config S2.
Config D4 | TESTED | | Status | Parts | Qg nC | Gfs Sie | Ciss pF | Vgs Volt | R7 | R8 | Freq MHz | R7 | R8 | Freq MHz | R7 | R8 | Freq MHz | OK | Comment
| Q5 | P | | IRF9610 | 11 | 0.9 | 170 | | 100 | | 9,36 | 98,54 | | 9,5 | 100 | | 9 | Yes | The square signals are a little less nice
| Q6 | N | | IRF610 | 8.2 | 0.8 | 140 | | | 100 | 11,36 | | 119,66 | 9,5 | | 120 | 9 | | than with D2 configurations.
CANDIDATE | | Status | Parts | Qg nC | Gfs Sie | Ciss pF | Vgs Volt | R7 | R8 | Freq MHz | R7 | R8 | Freq MHz | R7 | R8 | Freq MHz | OK | Comment
Q5 | P | | IRFI9620G | 15 | 1,3 | 340 | | 100 | | 4,68 | 99,59 | | 4,7
Q6 | N | | IRFI620G | 14 | 1.5 | 260 | | | 100 | 6,12 | | 130,24 | 4,7

Minimum Vds = 150V, same Vgs(th) range (4V), close transductance (Gfs), Vgs(th) = loaded @ 18V170mA
Config S1 | DEFAULT | | Status | Parts | Qg nC | Gfs Sie | Ciss pF | Vgs Volt | R14 | R15 | Freq KHz | R14 | R15 | Freq KHz | R14 | R15 | Freq KHz | R10-R13 (R) | THD % | SNR -dBuA | OK | Comment | Subjective sound review
| Q15 | N | EOL | FQA46N15 | 110 | 36 | 2500 | 4.1 | 330 | | 192,92 | 335,06 | | 190 | 330 | | 190 | 9.1 | 0,011 | 90,9 | Yes | Original config | Good sound.
| Q16 | P | n.a | FQA36P15 | 105 | 19.5 | 2550 | 3.7 | | 330 | 189,13 | | 328,49 | 190 | | 330 | 190 | | | | | | Well balanced sound.
Config S2 | TESTED | | Status | Parts | Qg nC | Gfs Sie | Ciss pF | Vgs Volt | R14 | R15 | Freq KHz | R14 | R15 | Freq KHz | R14 | R15 | Freq KHz | R10-R13 (R) | THD % | SNR -dBuA | OK | Comment | Subjective sound review
| Q15 | N | EOL | FQA46N15 | 110 | 36 | 2500 | 4.1 | 330 | | 192,92 | 335,06 | | 190 | 330 | | 190 | 9.1 | 0,017 | 88,2 | No | Q14=3.6V, Q16=-3.8V - Bad spectrum. | Good sound.
| Q16 | P | | IXTH48P20P | 103 | 32 | 5400 | 4.2 | | 330 | 89,31 | | 155,12 | 190 | | 150 | 190 | | | | | With R10/R13=8R2 consume 400mA. | Low frequency drier than S5.
Config S3 | TO TEST | | Status | Parts | Qg nC | Gfs Sie | Ciss pF | Vgs Volt | R14 | R15 | Freq KHz | R14 | R15 | Freq KHz | R14 | R15 | Freq KHz | R10-R13 (R) | THD % | SNR -dBuA | OK | Comment | Subjective sound review
| Q15 | N | | IXTQ50N20P | 70 | 23 | 2720 | | 330 | | 177,31 | 307,96 | | 190 | | | | 9.1 | | | | 48v max.
| Q16 | P | | IXTQ52P10P | 60 | 20 | 2845 | | | 330 | 169,52 | | 294,43 | 190 | | | | | | | | Good to try at 35-40V.
Config S4 | TESTED | | Status | Parts | Qg nC | Gfs Sie | Ciss pF | Vgs Volt | R14 | R15 | Freq KHz | R14 | R15 | Freq KHz | R14 | R15 | Freq KHz | R10-R13 (R) | THD % | SNR -dBuA | OK | Comment | Subjective sound review
| Q15 | N | | IXTQ36N30P | 70 | 22 | 2250 | 4.8 | 330 | | 214,35 | 372,29 | | 190 | 374 | | 190 | 8.2 | 0,022 | 87.2 dB | No | Q14=3.6V, Q16=-3.8V | Good sound.
| Q16 | P | | IXTQ36P15P | 55 | 19 | 3100 | 4.1 | | 330 | 155,57 | | 270,21 | 190 | | 270 | 190 | | | | | With R10/R13=9R1 ou 8R2 - Bad spectrum. | Low frequency less controlled than S5.
Config S5 | TESTED OK | | Status | Parts | Qg nC | Gfs Sie | Ciss pF | Vgs Volt | R14 | R15 | Freq KHz | R14 | R15 | Freq KHz | R14 | R15 | Freq KHz | R10-R13 (R) | THD % | SNR -dBuA | OK | Comment | Subjective sound review
| Q15 | N | EOL | FQA46N15 | 110 | 36 | 2500 | 4.1 | 330 | | 192,92 | 335,06 | | 190 | 330 | | 190 | 8.2 | 0,011 | 91,1 | Yes | Q15/Q16 well balanced (3.6V). | Good sound.
| Q16 | P | | IXTQ36P15P | 55 | 19 | 3100 | 4.1 | | 330 | 155,57 | | 270,21 | 190 | | 270 | 190 | | | | | With R10/R13=8R2. Good spectrum. | Well balanced sound.
CANDIDATE | | Status | Parts | Qg nC | Gfs Sie | Ciss pF | Vgs Volt | R14 | R15 | Freq KHz | R14 | R15 | Freq KHz | R14 | R15 | Freq KHz | R10-R13 (R) | THD % | SNR -dBuA | OK | Comment
Q15 | N | | IXTQ50N20P | 70 | 23 | 2720 | | 330 | | 177,31 | 307,96 | | 190 | | | | 9.1
Q16 | P | | IXTQ36P15P | 55 | 19 | 3100 | | | 330 | 155,57 | | 270,21 | 190
CANDIDATE | | Status | Parts | Qg nC | Gfs Sie | Ciss pF | Vgs Volt | R14 | R15 | Freq KHz | R14 | R15 | Freq KHz | R14 | R15 | Freq KHz | R10-R13 (R) | THD % | SNR -dBuA | OK | Comment
Q15 | N | | IXFH50N85X | 152 | 32 | 4480 | | 330 | | 107,65 | 186,97 | | 190 | | | | 9.1
Q16 | P | | IXTH48P20P | 103 | 32 | 5400 | | | 330 | 89,31 | | 155,12 | 190
CANDIDATE | | Status | Parts | Qg nC | Gfs Sie | Ciss pF | Vgs Volt | R14 | R15 | Freq KHz | R14 | R15 | Freq KHz | R14 | R15 | Freq KHz | R10-R13 (R) | THD % | SNR -dBuA | OK | Comment
Q15 | N | | IRFP240 | 70 | 6.9 | 1300 | | 330 | | 370,99 | 644,35 | | 190 | | | | 9.1
Q16 | P | | IRFP9240 | 44 | 9.4 | 1200 | | | 330 | 401,90 | | 698,04 | 190
SIM NOT WORKING | Status | Parts | Qg nC | Gfs Sie | Ciss pF | Vgs Volt | R14 | R15 | Freq KHz | | R14 | R15 | Freq KHz | | R14 | R15 | Freq KHz | R10-R13 (R) | THD % | SNR -dBuA | OK | Comment
Q15 | N | | ECX10N20 | | 1 | 500 | | 330 | | 964,57 | | 1675,31 | | 190 | | | | | 9.1
Q16 | P | | ECX10P20 | | 1.5 | 500 | | | 330 | 964,57 | | | 1675,31 | 190
SIM NOT WORKING | Status | Parts | Qg nC | Gfs Sie | Ciss pF | Vgs Volt | R14 | R15 | Freq KHz | | R14 | R15 | Freq KHz | | R14 | R15 | Freq KHz | R10-R13 (R) | THD % | SNR -dBuA | OK | Comment
Q15 | N | | ECW20N20 | | 8 | 900 | | 330 | | 535,87 | | 930,73 | | 190 | | | | | 9.1
Q16 | P | | ECW20P20 | | 3 | 1850 | | | 330 | 267,93 | | | 452,78 | 190

Minimum Vds = 60V, same Vgs(th) range (4V)
Config A1 | DEFAULT | | Status | Parts | Qg nC | Gfs Sie | Ciss pF | Vgs Volt | R40 | R41 | Freq MHz | R40 | R41 | Freq MHz | R40 | R41 | Freq MHz | Zener Volt | OK | Comment
| Q1 | N | | IRF610 | 8.2 | 0.8 | 140 | | 100 | | 11,36 | 126,31 | | 9 | 100 | | 9 | 18 | Yes | Original config
| Q4 | P | | IRF9610 | 11 | 0.9 | 170 | | | 100 | 9,36 | | 104,02 | 9 | | 100 | 9
Config A2 | TESTED (SMD) | | Status | Parts | Qg nC | Gfs Sie | Ciss pF | Vgs Volt | R40 | R41 | Freq MHz | R40 | R41 | Freq MHz | R40 | R41 | Freq MHz | Zener Volt | OK | Comment
| Q1' | N | | Si2308BDS | 6.8 | 5 | 190 | | 100 | | 8,37 | 104,70 | | 8 | 100 | | 8 | 16 | Yes | Need 16V zener 1N5246B to get 13.5V.
| Q4' | P | | Si2309CDS | 4.1 | 2.8 | 210 | | | 100 | 7,57 | | 94,73 | 8 | | 100 | 8 | | | Source-Gate = 2.15V
Config A3 | TESTED (SMD) | | Status | Parts | Qg nC | Gfs Sie | Ciss pF | Vgs Volt | R40 | R41 | Freq MHz | R40 | R41 | Freq MHz | R40 | R41 | Freq MHz | Zener Volt | OK | Comment
| Q1' | N | | DMN6075SQ | 12.3 | n.a | 606 | | 100 | | 2,62 | 100,34 | | 2,6 | 100 | | 2,6 | 16 | Yes | Need 16V zener 1N5246B to get 13.5V.
| Q4' | P | | DMPH6250S | 4 | n.a | 512 | | | 100 | 3,10 | | 119,55 | 2,6 | | 100 | 3 | | | Source-Gate = 1.6V
Config A4 | TESTED OK (SMD) | | Status | Parts | Qg nC | Gfs Sie | Ciss pF | Vgs Volt | R40 | R41 | Freq MHz | R40 | R41 | Freq MHz | R40 | R41 | Freq MHz | Zener Volt | OK | Comment
| Q1' | N | | SI2328DS | 5 | 4 | 150 | | 100 | | 10,61 | 350 | | 3 | 100 | | 10 | 15 | Yes | Need 15V zener 1N5245B to get 13V.
| Q4' | P | | Si2325DS | 12 | 2.2 | 510 | | | 100 | 3,12 | | 100 | 3 | | 100 | 3 | | | Source-Gate = 1.6V

Pair of transistors for op-amp power supply

Pair of transistors for the output stage.

Q17-Mini 3.0 Power Transistors Selection Table
Pair of transistors for the driver stage.
Minimum default config | | Caculated (RCiss filter) | | Final resistor values (scope)
Config D1 | DEFAULT | | Status | Parts | Qg nC | Gfs Sie | Ciss pF | Vgs Volt | R7 | R8 | Freq MHz | R7 | R8 | Freq MHz | R7 | R8 | Freq MHz | OK | Comment
| Q5 | P | EOL | FQP3P20 | 6 | 1.23 | 190 | | 100 | | 8,38 | 104,7 | | 8 | 100 | | 8 | Yes | Original config
| Q6 | N | EOL | FQP3N30 | 7 | 1.75 | 75 | | | 100 | 21,22 | | 265,25 | 8 | | 255 | 8

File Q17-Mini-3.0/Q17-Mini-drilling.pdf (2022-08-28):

Q17-Mini Drilling

Out board power transistors

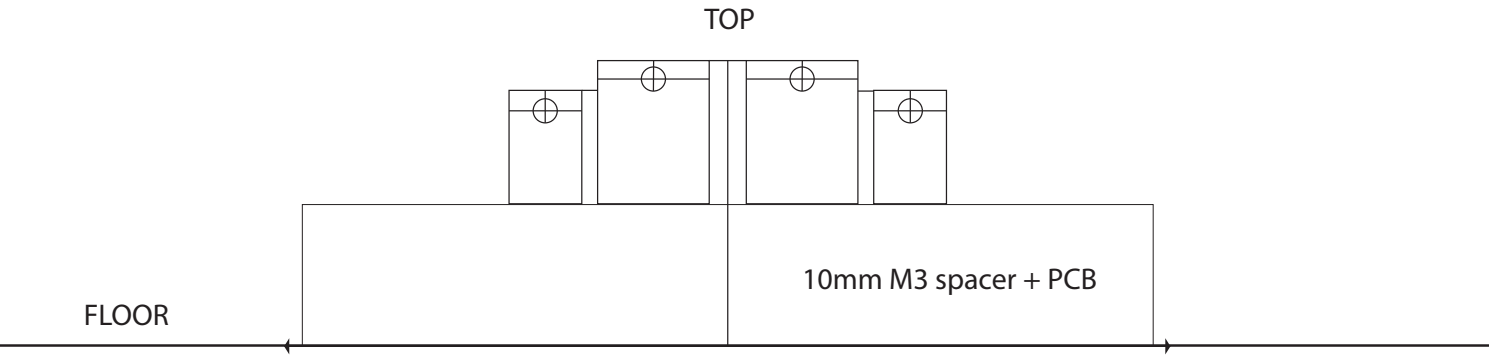
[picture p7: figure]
TOP; FLOOR; 10mm M3 spacer + PCB

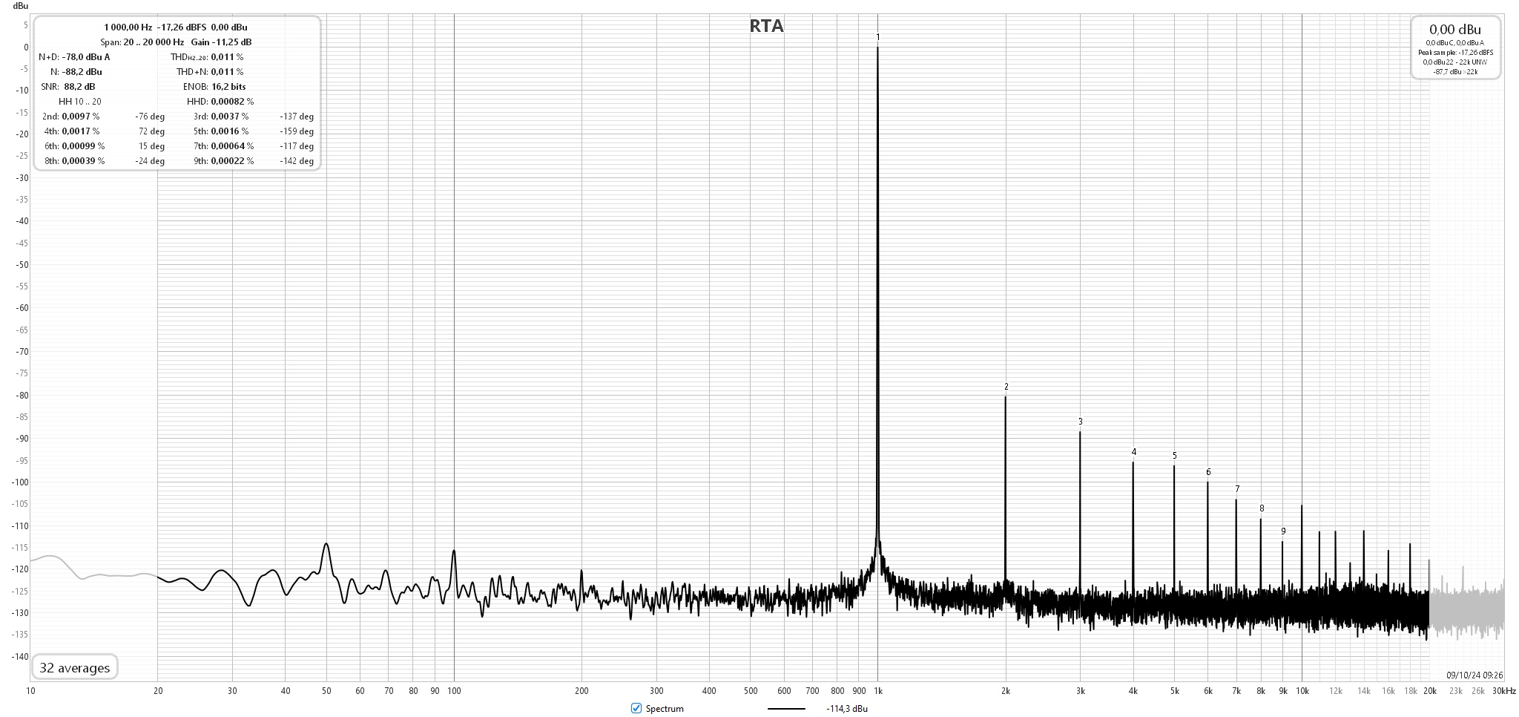
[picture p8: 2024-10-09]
Q17-Mini-3.0/Measures Q17-Mini 3.0/Q17-Mini-3.0-spectrum_OPA1641.jpg

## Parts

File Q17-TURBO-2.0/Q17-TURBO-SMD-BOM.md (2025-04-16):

# Components for Q17-Turbo 2.0 SMD version

Some components of the Q17-Turbo amplifier board can also be used with SMD variants.

- The Q11 and Q111 pair of BS250P can be replaced below the PCB with a NDC7003P on the U2 footprint.

- Q1 and Q4 can be replaced by Q1' and Q4' below the PCB.

	Q1': SI2328DS
	Q4': SI2325DS

	In this case with 60V rails, zeners D2 and D3 MUST BE REPLACED by 16V 1N5246B zener to get 14V.

	Other Mosfet pairs are compatible and have been tested. For more information see the Q17-Power-Transistors-Selection PDF table available in the Github repository.

- Q7 can be replaced by Q7' below the PCB with a JFE150 (don't forget to change R6 value to 182R).

- It is also possible to solder the opamp directly below the PCB on the U1 footprint without using a DIP socket.

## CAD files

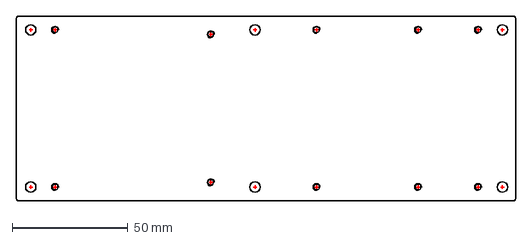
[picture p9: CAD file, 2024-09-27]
Q17-TURBO-2.0/Mounting Plate-Q17-Turbo-216x80-1.0.dxf
216.0 x 80.0 mm

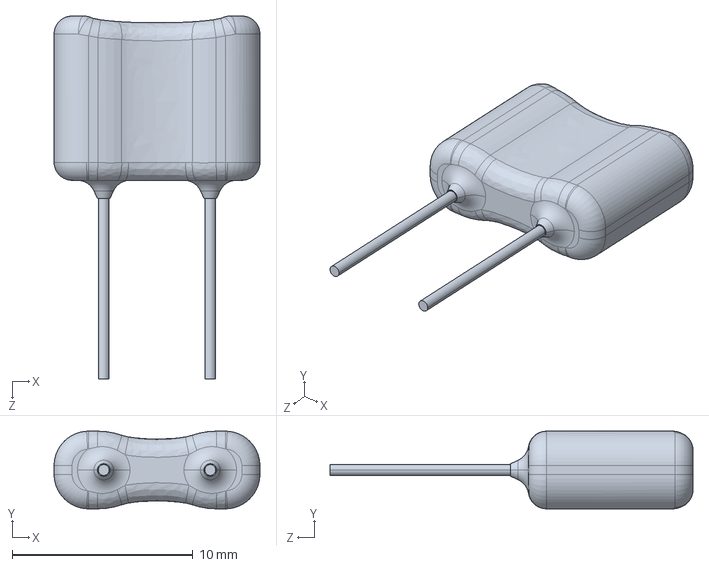
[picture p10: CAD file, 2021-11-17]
KiCad source/KICAD Library/3dmodels/mica-cap.step
11.4 x 4.30 x 20.1 mm

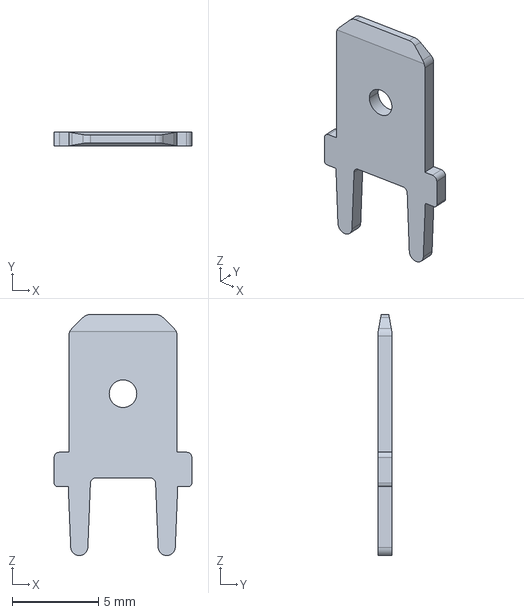
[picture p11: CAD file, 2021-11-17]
KiCad source/KICAD Library/3dmodels/c-63849-1-g-3d.stp
8.00 x 0.8 x 14.0 mm

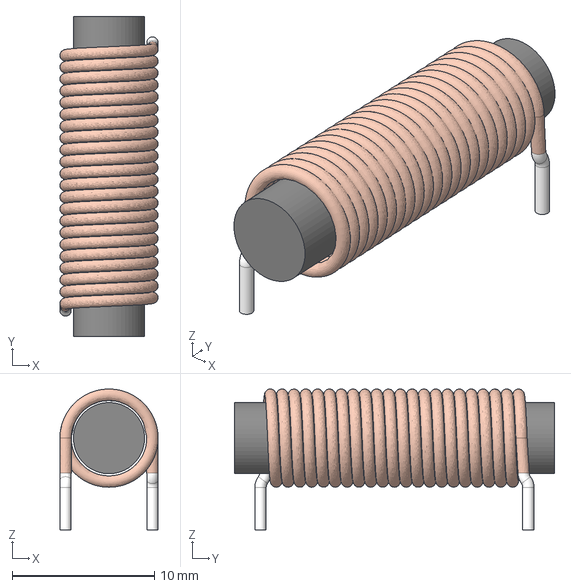
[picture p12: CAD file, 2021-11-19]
KiCad source/KICAD Library/3dmodels/744711005_Download_STP_744711005_rev1.stp
6.90 x 22.5 x 9.90 mm

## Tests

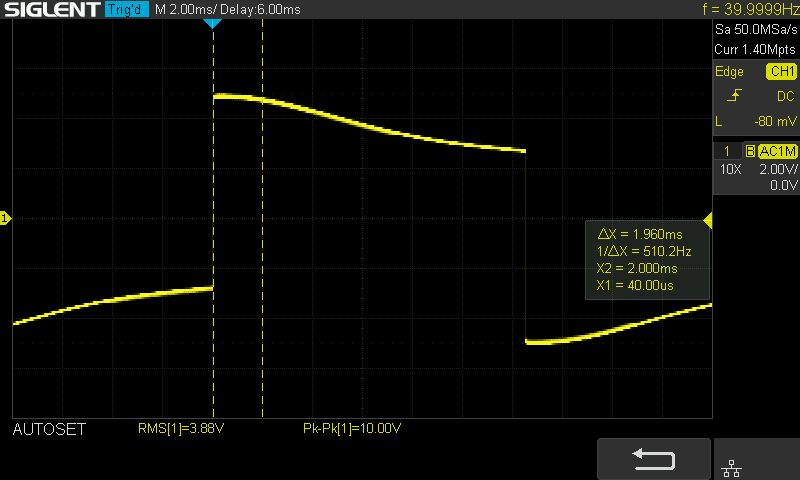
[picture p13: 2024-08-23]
Q17-Mini-3.0/Measures Q17-Mini 3.0/SQUARE_40Hz_1W.jpg

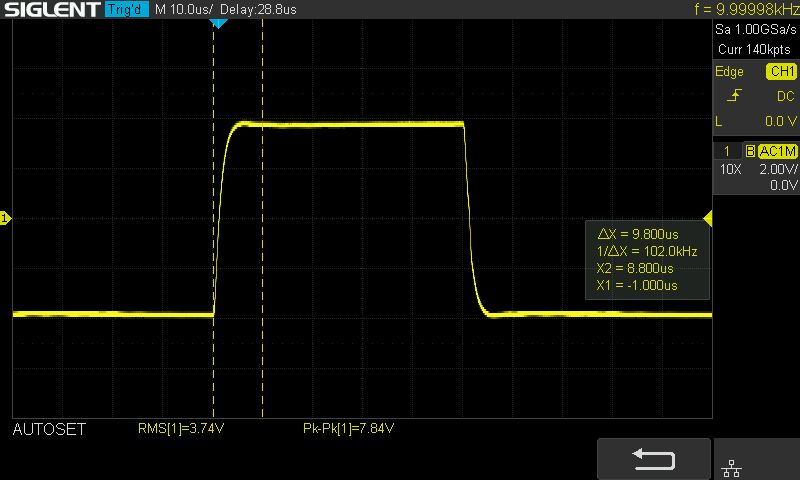
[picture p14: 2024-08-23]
Q17-Mini-3.0/Measures Q17-Mini 3.0/SQUARE_10KHz_1W.jpg

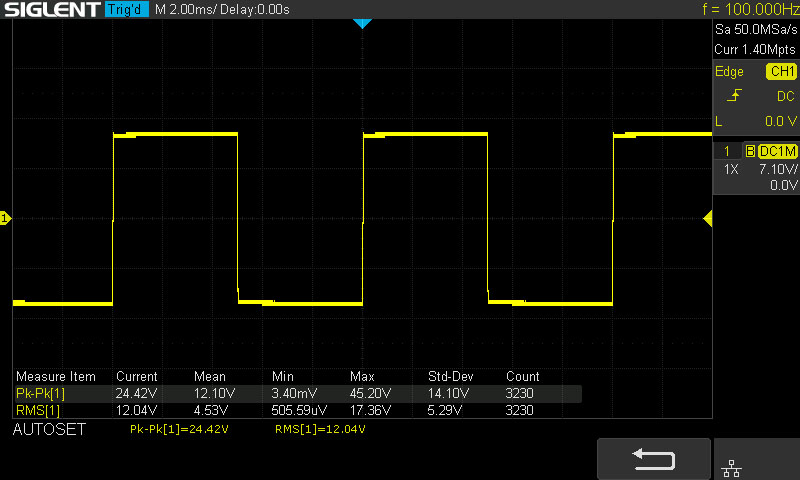
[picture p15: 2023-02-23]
Q17-TURBO 1.0/Measures Q17-Turbo 1.0/Q17-Turbo-square-100hz-50v-clip.jpg

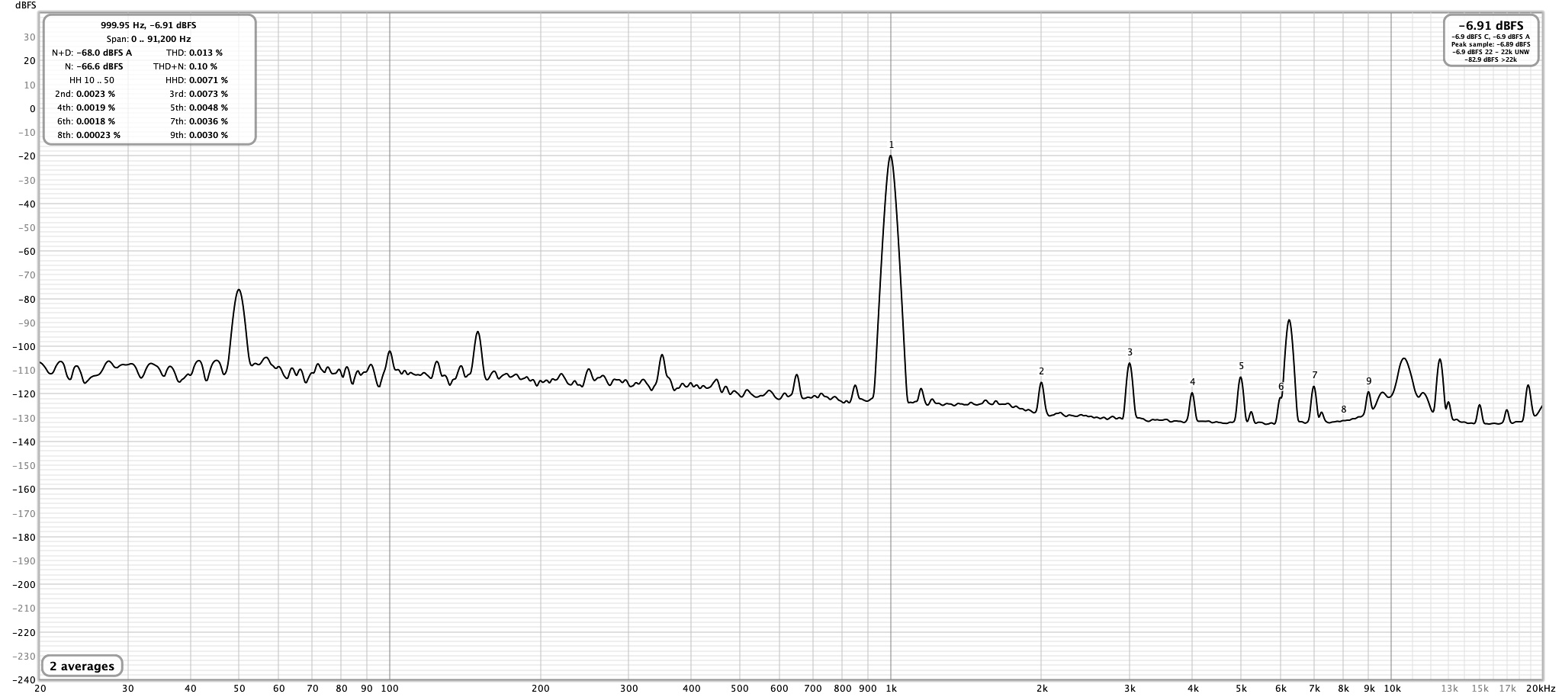
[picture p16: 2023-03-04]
Q17-TURBO 1.0/Measures Q17-Turbo 1.0/Q17-Turbo-THD.jpg

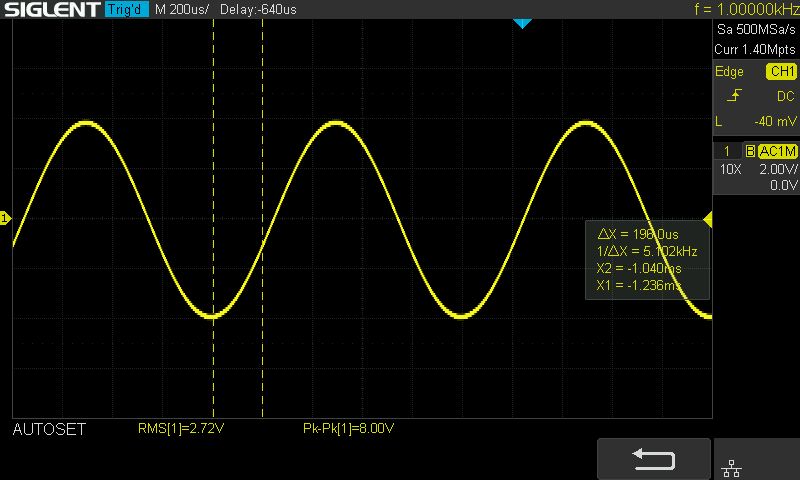
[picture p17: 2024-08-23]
Q17-Mini-3.0/Measures Q17-Mini 3.0/SIN_1KHz_1W.jpg

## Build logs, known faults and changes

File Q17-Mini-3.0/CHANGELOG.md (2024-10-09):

# Changelog Q17-Mini

Version [3.0.4] (7-10-2024)

- Modified low signal ground plane.
- Replaced 2SK3564 by FQPF3N80C for Q6.
- Updated Q17-Mini-BOM.html.
- Updated measures.

Version [3.0.3] (14-09-2024)

- Reduced hole size for R26, R27, R28 and R31.
- Added a dual footprint with lead spacing of 2.5mm and 5.0mm for C3 and C6.
- Changed R15 to 270R.
- Modified ground plane connection for C2.

Version [3.0.2] (23-08-2024)

- Added 2 diodes SL1M-AQ (D8/D9) for a more secure MOSFET protection.
- Added SOT-23 footprint for Q1 and Q4 on back PCB (Q1' = SI2328DS and Q4' = SI2325DS). Need 15V 1N5245B zener on D2 and D3 to get 13V.
- Replaced IXTH48P20P by IXTQ36P15P for Q16.
- Replaced JFET choice OPA1641 by OPA828 (U1).
- Updated R10 and R13 to 8R2 for IXTQ36P15 compatibility. Bias for class A stage is now 78mA (+8mA).
- Moved Q7' SMD footprint closer to Q7.
- The board now consume at idle 200mA @ 50Vdc (warm board).
- Updated diagram with last components and values.
- Updated Q17-Mini-BOM.html and Q17-Mini-SMD-BOM.md files.
- Added Q17-Power-Transistors-Selection table on Github repository.

Version [3.0.1] (27-07-2024)

- Complete new PCB design and components placement.
- Same PCB size, mounting holes and power transistor locations as v2.
- Removed all thermal brakes and VIAs (except for U2).
- Removed R32. No longer needed due to new ground plane.
- Removed C18 and C19. They are not needed with low ESR capacitors.
- Added D7 and D8 protection zener (MMSZ5245C).
- Updated R17 to 196R for 1.2V sensibility (with LSK170B).
- Updated R15 to 150R (with IXTH48P20P in Q16).
- Merged GND / GNDPWR ground and built a new ground plane using GND zones and star topology.
- Better thermal management on the PCB.
- Updated diagram to 2.3.
- Updated iBOM Q17-Mini-BOM file.
- Added Q17 Power Transistors Selection table PDF file on github repository.

Version [2.2.1] (8-06-2024)

- Modified C7 footprint to support 2.2uF MKP capacitor (Lead spacing 22.5mm).
- Added double footprint for SMD U2 (NDC7003P) or TH Q11 / Q111 (2 matched BS250P).
- Added D7 and D8 protection zener (MMSZ5245C).
- Removed R33 and C20 (removed LFE at input no longer used).
- Various changes on GND and GNDPWR backplane.
- Changed C15 and C16 to 470uF.
- Added more parts on the diagram.
- Updated diagram to 2.2.
- Updated iBOM Q17-Mini-BOM file.

Version [2.0.1] (21-05-2024)

- Changed C7 to 2.2uF (better bandwidth linearity).
- Changed R16 to 47k.
- Removed R33 (replace with 0R or strap).
- Removed C20.
- No PCB change.

Version [2.0] (3-09-2023)

- New Q17.3 circuit.
- Added Erno Borbely cascode type using JFET & depletion NMOS (Q7, Q8). Can now use low noise JFET's like LSK170B (TH) or TI Burr-Brown JFE150 (SMD).
- Current mirror was updated to a Wilson CCS with BS250 and NDC7003P (Q9 & U2).
- The signal-to-noise ratio is better over the entire audio band.
- Use handsoldering SMD footprints (enlarged tracks).
- Removed C29 and C30 from schematic and SMD footprint on back PCB.
- Removed C4' and C5' SMD footprint on back PCB.
- Added Q7' optional SMD footprint on back PCB for JFE150.
- R10 and R13 changed to 9R1 (was 10R).
- Replaced OPA1641 with OPA828 (SiGe JFET) for JFET lovers.
- The 4 M3 mounting holes have been ovalized for easier installation.
- Updated schematic with available Mouser part number and datasheet links.
- Updated iBOM Q17-Mini-BOM file and <a href="https://audio.cyberkata.org/Q17-Mini-2.0.html">Online Q17-Mini-2.0-BOM</a> with Mouser part number (can be exported).
- New audio measures available.

Version [1.3.1] (25-06-2023)
- Moved C10 for better placement (thermal).
- Modified some parts of GND ground plane.
- The SMD capacitors footprints have been moved slightly away from the active components. Was difficult to solder by hand.
- Added JST-XH connector footprint for J1 (input).
- Changed U1 to OPA1611 (Sound warmer and a little less midrange).
- Updated C3/C6 to 47uF/25v (Nichicon Muse KZ UKZ1E470MPM1).
- Changed R29 and R30 to 100R (no more noise at power on)
- Replaced BD139G on Q12 with KSC1845 and updated footprint.
- Many parts equivalences added in schematic.

Version [1.3](https://github.com/stefaweb/Q17-a-QUAD405-audiophile-approach/commit/e14c5743dc9d61eb0646178def298882dcf551b0) (26-08-2022)

- Moved Q8, R1, R5, R23 and R25 to new location.
- Moved R7 close to Q5.
- Moved R8 close to Q6.
- Removed R22 at opamp input.
- Changed R40 and R41 to 100 Ohms.
- Changed C29 and C30 to 15nF (optional).
- The holes in the PCB for C7 have been enlarged. You can now solder a larger high end capacitor to the back of the PCB.
- More silkscreen text on front and back side.
- Added component Part Number column in Q17-Mini-BOM.html.
- DC offset at output is now < 2mV.
- Added Q17-Mini-drilling.pdf to help to drill holes for power transistors.
- Updated Q17-Mini-BOM.html.

Version [1.2.1](https://github.com/stefaweb/Q17-a-QUAD405-audiophile-approach/commit/6671ab5b4a45497aaad0a56b8615fdbb069a5a3f) (9-08-2022)

- Removed R22 at opamp input.
- Changed R40 and R41 to 100 Ohms.
- Changed C29 and C30 to 15nF (optional).
- Changed R29 and R30 to 10k.
- R32 replaced by a strap (R2=0R).
- More silkscreen text on front and back side.
- Added component Part Number column in Q17-Mini-BOM.html.

Version [1.2](https://github.com/stefaweb/Q17-a-QUAD405-audiophile-approach/tree/8caf9e90742d23102cca4e3eea3342eca072945a) (6-03-2022)

- New (optional) LPF (R33/C20) at input to protect op-amp.
- L1 coil is now positioned vertically and have more space around.
- Q7 and its resistors moved to a better location.
- New gate stopper resistor R40/R41 for Q1 and Q4.
- R32 moved to a better location.
- New C7 footprint can fit Wima MKP2, FKP2 and MKS4 (5mm and 7.5mm pitch).
- C17 now can fit Wilma FKP3 and MKP10.
- New C20 can fit Wima FKP2, Vishay MKT and CDE Mica (5mm and 5.9mm pitch).
- New design for 70% of tracks. Removed all signal VIAS (there were eight).
- Ground plane on both sides with ground VIAS.
- Added some optional SMD footprints on the back side.
- More silkscreen text on back side.

Version [1.1.4](https://github.com/stefaweb/Q17-a-QUAD405-audiophile-approach/tree/5d390576078fdaf95bd449d5fe2e2c45a9edb5e6) (13-01-2022)

- Changed L1 footprint (vertical).
- Added R42 and R43.
- Switched R18 and C7.
- Added some optional SMD footprints.
- Rounded tracks.
- Updated diagram.

Initial release : [1.1.1](https://github.com/stefaweb/Q17-a-QUAD405-audiophile-approach/tree/8860557ad7c0319b1982263380b270c39a1ce374) (10-12-2021)

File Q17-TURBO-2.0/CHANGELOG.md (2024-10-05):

# Changelog Q17-Turbo

Version [2.0.1] (5-10-2024)

- Complete new PCB design and components placement.
- Same PCB size, mounting holes and power transistor locations as v1.
- Removed all thermal brakes and VIAs.
- Now use same L1 coil as Q17-Mini.
- Merged GND / GNDPWR ground and built a new ground plane using GND zones and star topology.
- Added a dual footprint with lead spacing of 2.5mm and 5.0mm for C3 and C6.
- Removed R32 no longer needed due to the new ground plane.
- Updated C7 to 3.0uF.
- Added 2 diodes 1N4148 (D8/D9) for a more secure MOSFET protection.
- Added SOT-23 footprint for Q1 and Q4 on back PCB (Q1' = SI2328DS and Q4' = SI2325DS). Need 16V 1N5246B zener on D2 and D3 to get 14V. See Q17-Turbo-SMD-BOM.md file.
- Reduced hole size of resistors R26, R27 and R28.
- Replaced IXTH48P20P by IXTQ36P15P for Q16.
- Updated R17 to 150R for 1.2V sensibility (with LSK170B).
- Updated R15 and R35 to 270R for IXTQ36P15P compatibility.
- Replaced JFET choice OPA1641 by OPA828 (U1).
- Updated R10 and R13 to 8R2 for IXTQ36P15P compatibility. Bias for class A stage is now 78mA (+8mA).
- The board now consume at idle 220mA @ 60Vdc (warm board).
- Updated diagram with last components and values.
- Updated iBOM Q17-Turbo-BOM.html and Q17-Turbo-SMD-BOM.md files.

Version [1.2.4] (21-05-2024)

- Changed C7 to 2.2uF (better bandwidth linearity).
- Removed R33 (replace with 0R or strap).
- Removed C20.
- No PCB change.

Version [1.2.3] (27-10-2023)

- Added Faston connector footprint on J3 input power connector.
- Added zener D7 and D8 (1N5245B) to protect output.
- Updated the reference of C15 and C16 to Nichicon LKG (take advantage while they still last).
- Modified R32 footprint to support potentiometer type T93YA100KT20 (for testing).
- Removed useless fuse sockets to fit new Faston footprint.
- Optimized some tracks on GNDPWD parts (power line to Q13/Q14).
- Moved T5 and T6 to a better location.

- Various adds on schematic.
- New measures with a better measurement device.

Version [1.2.2] (4-09-2023)

- Added J4 jumper to be able to strap R32 more easily.
- R25 changed to 8k2 (was 7k5). Value optimized for 60Vdc.

Version [1.2.1] (08-08-2023)

- New version of PCB files. Corrected an error on the SMD footprint for U1 on the back.
- Added PJS6839 as replacement of NDC7003P.

Version [1.2.0] (30-07-2023)

- New circuits for handling low level signals and better specs at frequencies above 10KHz.
- Added Erno Borbely cascode type using JFET & depletion NMOS (Q7, Q8). Can now use low noise JFET's like LSK170B (TH) or TI Burr-Brown JFE150 (SMD).
- Current mirror was updated to a Wilson CCS with BS250 and NDC7003P (Q9 & U2).
- DC offset is now below 1mV (with R32=0R).
- The signal-to-noise ratio is better over the entire audio band.
- Now work at 60vDC (recommended voltage).
- Use handsoldering SMD footprints (enlarged tracks).
- Removed C29 and C30 from schematic and SMD footprint on back PCB.
- Removed C4' and C5' SMD footprint on back PCB.
- Added Q7' optional SMD footprint on back PCB for JFE150.
- Moved C31 and C32 close to the power input.
- R10 and R13 changed to 9R1 (was 10R).
- New footprint and parts for C18 and C19 (0.1uF MKP). Can accept 15mm and 7.5mm lead spacing.
- Added voltage test point footprints.
- Enlarged fuse footprint holes (fit 1mm2 wire now).
- Reverted J3 in schematic and PCB. Silkscreen was not on the right side.
- Replaced OPA1641 with OPA828 (SiGe JFET) for JFET lovers.
- Updated schematic with available Mouser part number and datasheet links.
- Updated iBOM Q17-TURBO-BOM file and <a href="https://audio.cyberkata.org/Q17-TURBO-BOM.html">Online Q17-TURBO-BOM</a> with Mouser part number (can be exported).
- New audio measures available.

Version [1.0.2] (26-06-2023)

- Replaced BD139G on Q12 with KSC1845 and updated footprint.
- Added parts equivalences in schematic.

Version [1.0.1](https://github.com/stefaweb/Q17-a-QUAD405-audiophile-approach/tree/5d390576078fdaf95bd449d5fe2e2c45a9edb5e6) (9-05-2023)

- Added U2 footprint on back PCB (replace Q9 and Q11).
- Updated some silkscreen on back PCB.
- Updated schematic with new parts.

Initial release : [1.0.0](https://github.com/stefaweb/Q17-a-QUAD405-audiophile-approach/tree/8860557ad7c0319b1982263380b270c39a1ce374) (10-12-2021)

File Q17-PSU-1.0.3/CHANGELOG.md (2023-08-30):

# Changelog Q17-PSU

Version [1.0.3] (30-08-2023)

- Changed C1 and C2 for 10nF 100V COG (do not use MKP here with Saligny bridge).
- Updated schematic with available Mouser part number and datasheet links.
- Updated PCB for new C1 and C2 footprint (pitch of 5mm).
- Updated BOM.

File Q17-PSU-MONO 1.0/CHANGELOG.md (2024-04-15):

# Changelog Q17-PSU-MONO

Version [1.0] (15-04-2024)

- Initial release.

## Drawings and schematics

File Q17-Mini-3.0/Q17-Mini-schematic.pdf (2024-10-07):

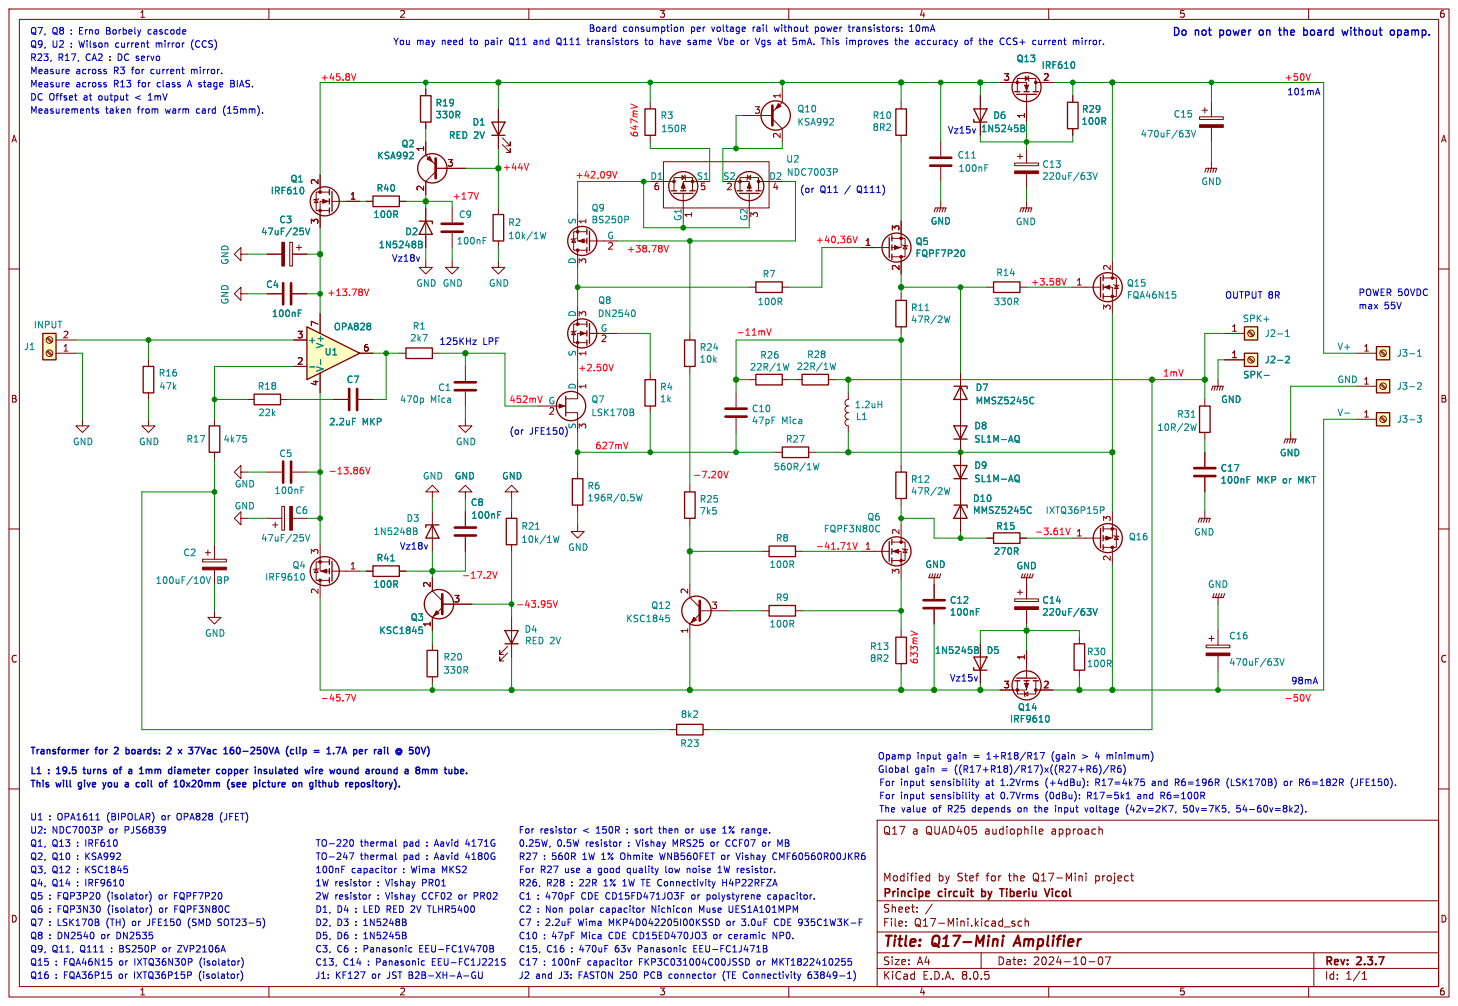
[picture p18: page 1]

POWER 50VDC max 55V Q9, U2 : Wilson current mirror (CCS) Measure across R13 for class A stage BIAS. R23, R17, CA2 : DC servo

+50V Do not power on the board without opamp.

100nF MKP or MKT GNDGND

J1: KF127 or JST B2B-XH-A-GU

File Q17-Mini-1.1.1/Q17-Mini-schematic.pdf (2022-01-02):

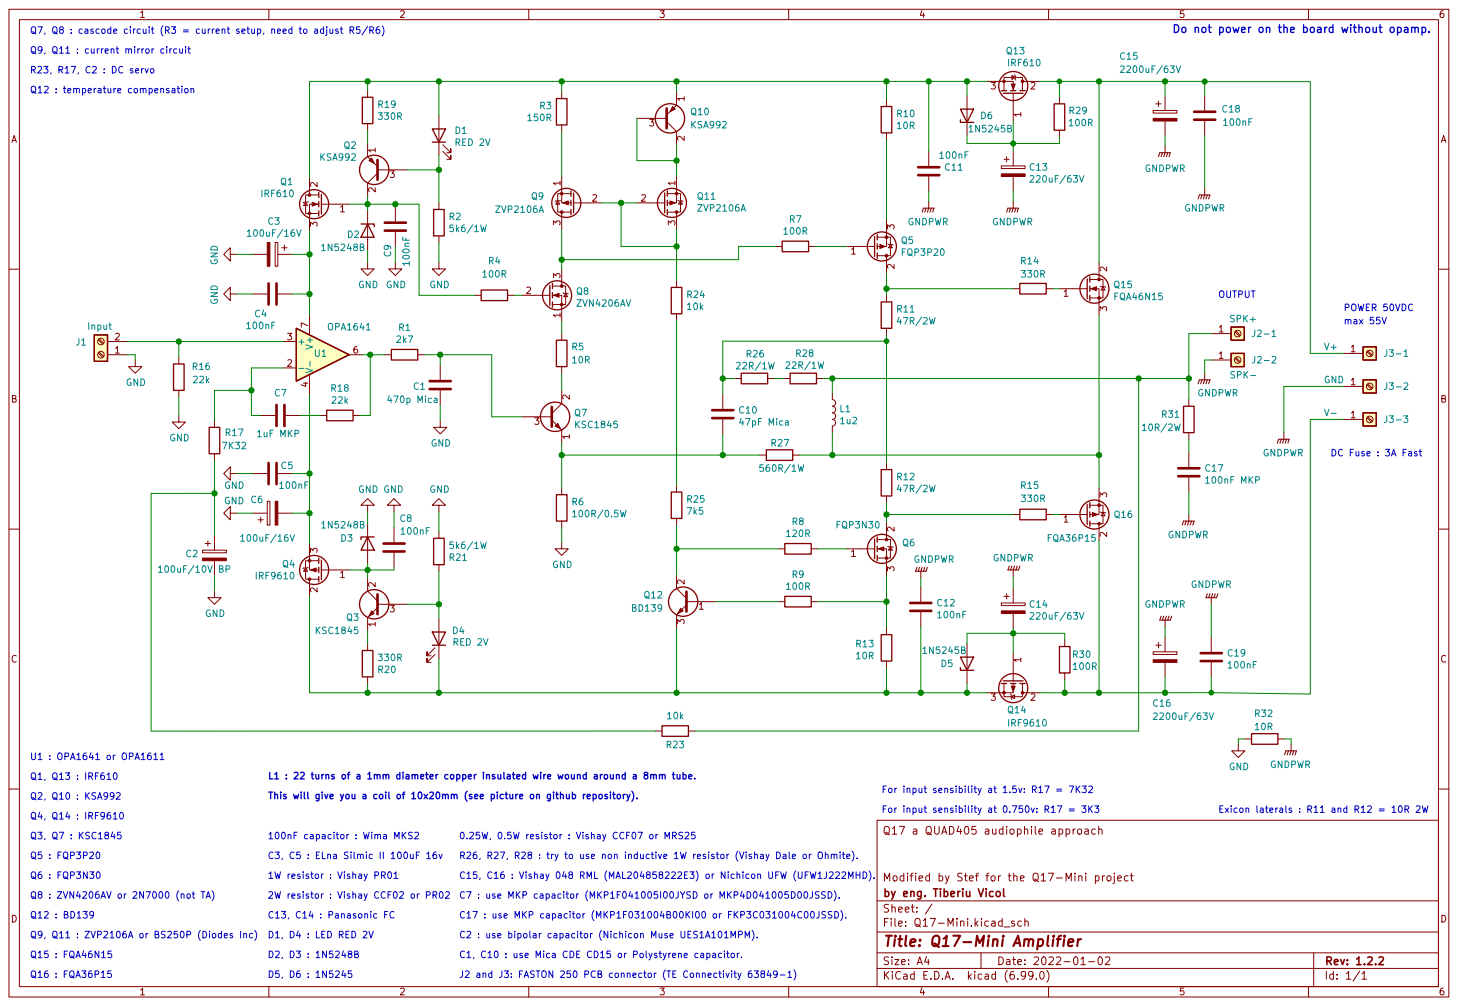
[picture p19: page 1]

Q7, Q8 : cascode circuit (R3 = current setup, need to adjust R5/R6)
R23, R17, C2 : DC servo Q9, Q11 : current mirror circuit

Do not power on the board without opamp. OUTPUT

DC Fuse : 3A Fast max 55V C17 : use MKP capacitor (MKP1F031004B00KI00 or FKP3C031004C00JSSD).

This will give you a coil of 10x20mm (see picture on github repository).

For input sensibility at 0.750v: R17 = 3K3

R26, R27, R28 : try to use non inductive 1W resistor (Vishay Dale or Ohmite).
C15, C16 : Vishay 048 RML (MAL204858222E3) or Nichicon UFW (UFW1J222MHD).

Modified by Stef for the Q17-Mini project
File: Q17-Mini.kicad_sch Sheet: / by eng. Tiberiu Vicol

Id: 1/1 Title: Q17-Mini Amplifier

C2 : use bipolar capacitor (Nichicon Muse UES1A101MPM).

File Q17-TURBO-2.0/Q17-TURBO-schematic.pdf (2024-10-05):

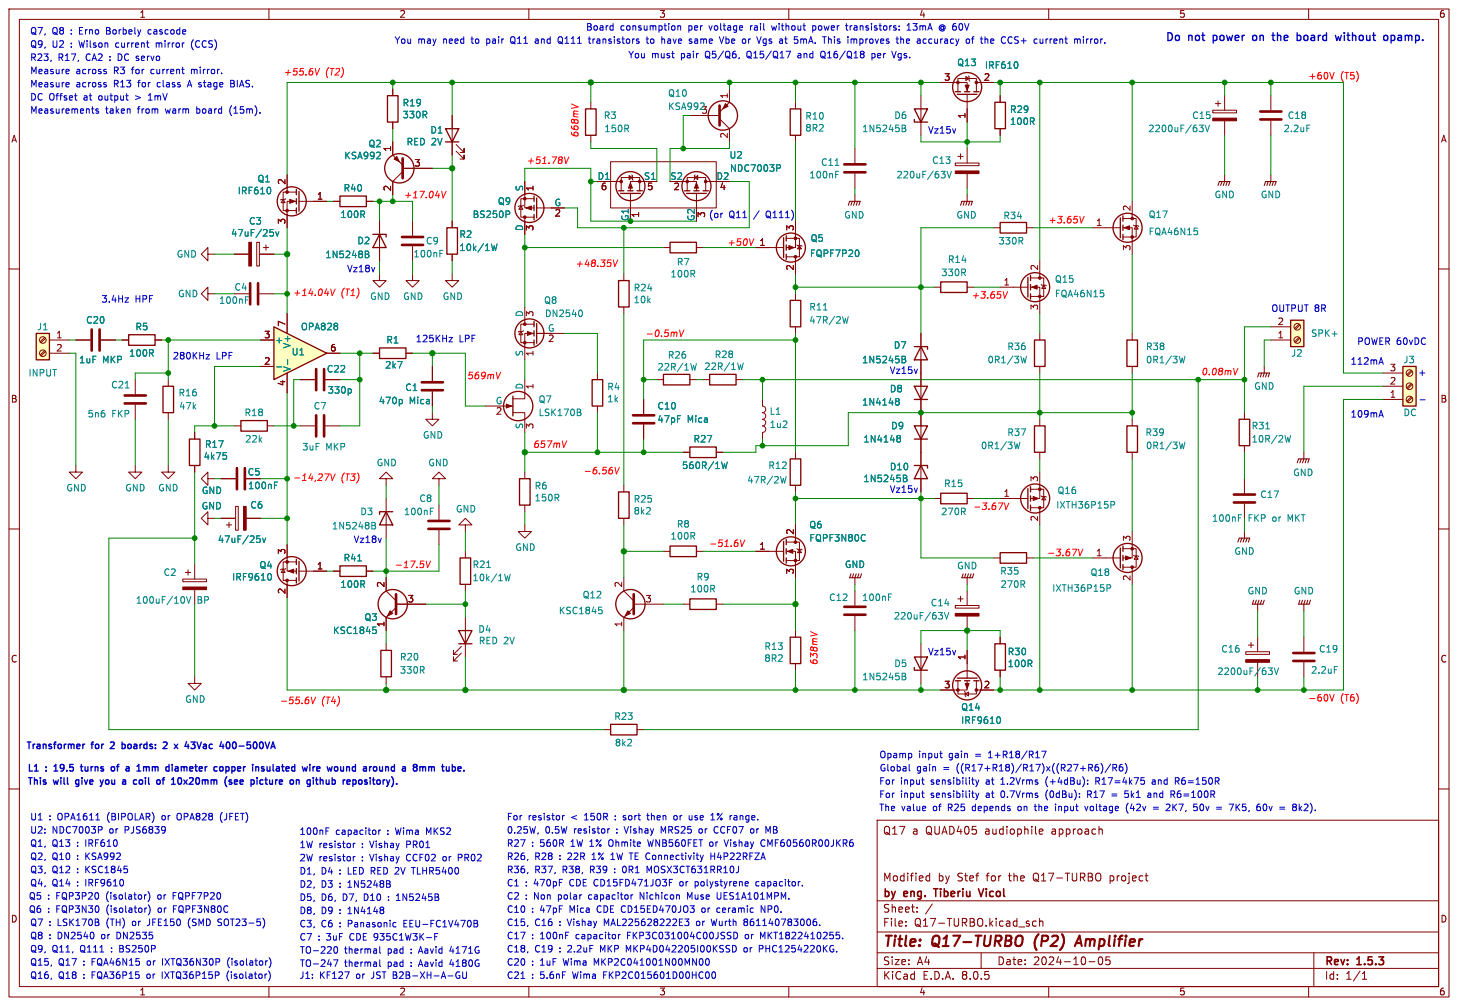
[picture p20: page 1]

Vz15v Q7 : LSK170B (TH) or JFE150 (SMD SOT23-5) Q16, Q18 : FQA36P15 or IXTQ36P15P (isolator)

J1: KF127 or JST B2B-XH-A-GU

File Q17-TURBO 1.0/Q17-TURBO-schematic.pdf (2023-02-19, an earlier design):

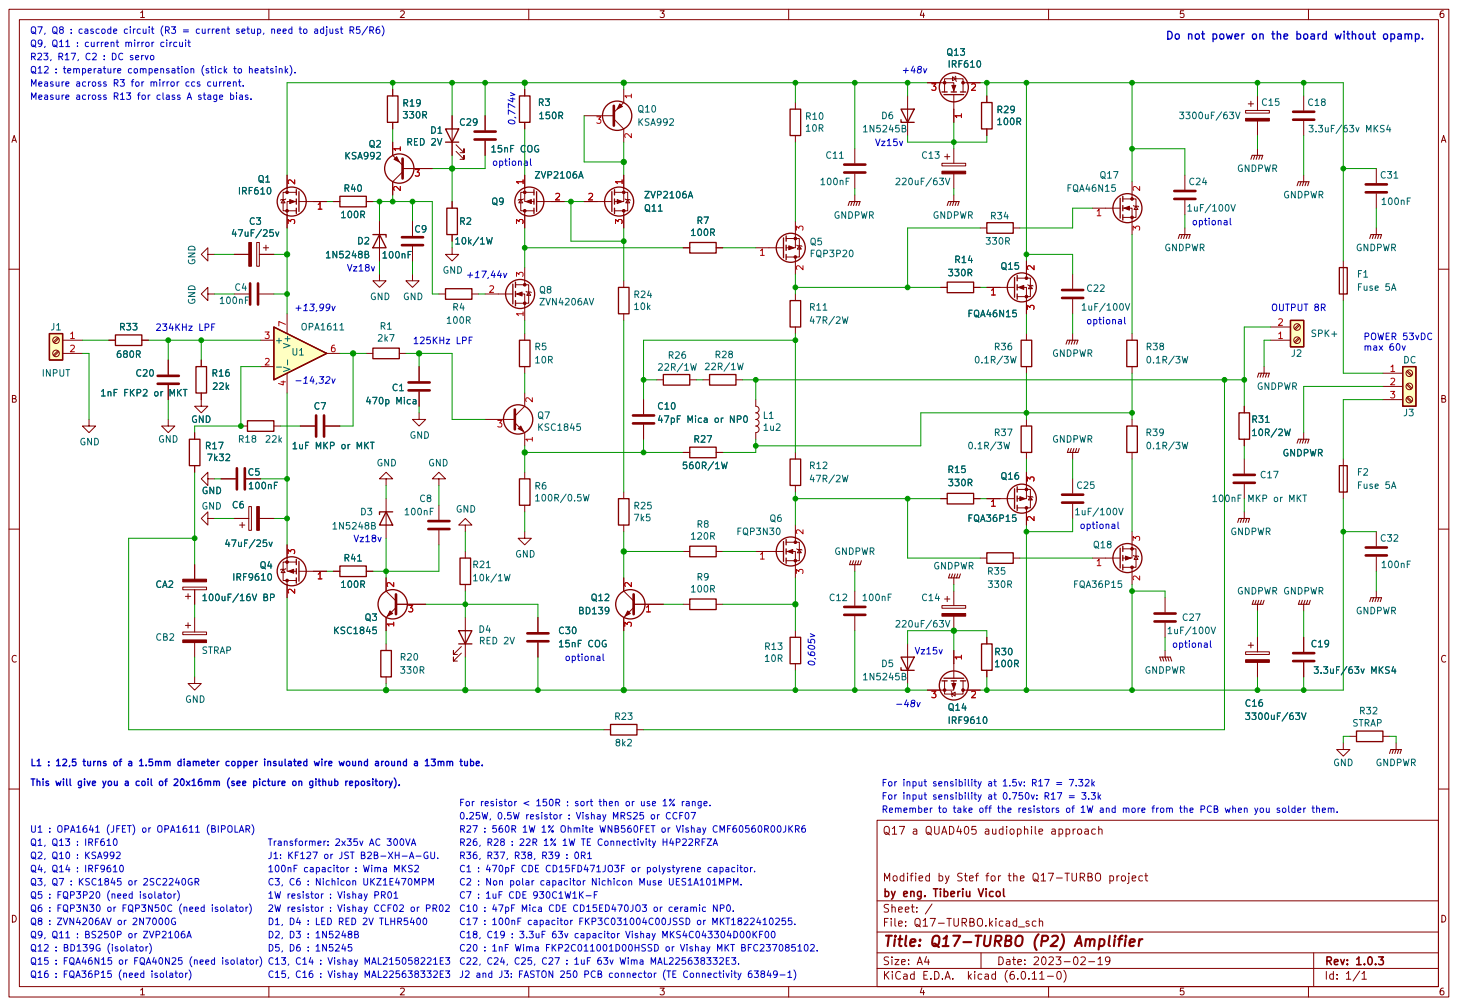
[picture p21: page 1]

optional Measure across R13 for class A stage bias.

1uF MKP or MKT GND

optional Vz18v D1, D4 : LED RED 2V TLHR5400 C15, C16 : Vishay MAL225638332E3

Q3, Q7 : KSC1845 or 2SC2240GR Q5 : FQP3P20 (need isolator) Q6 : FQP3N30 or FQP3N50C (need isolator) Q16 : FQA36P15 (need isolator) Q8 : ZVN4206AV or 2N7000G

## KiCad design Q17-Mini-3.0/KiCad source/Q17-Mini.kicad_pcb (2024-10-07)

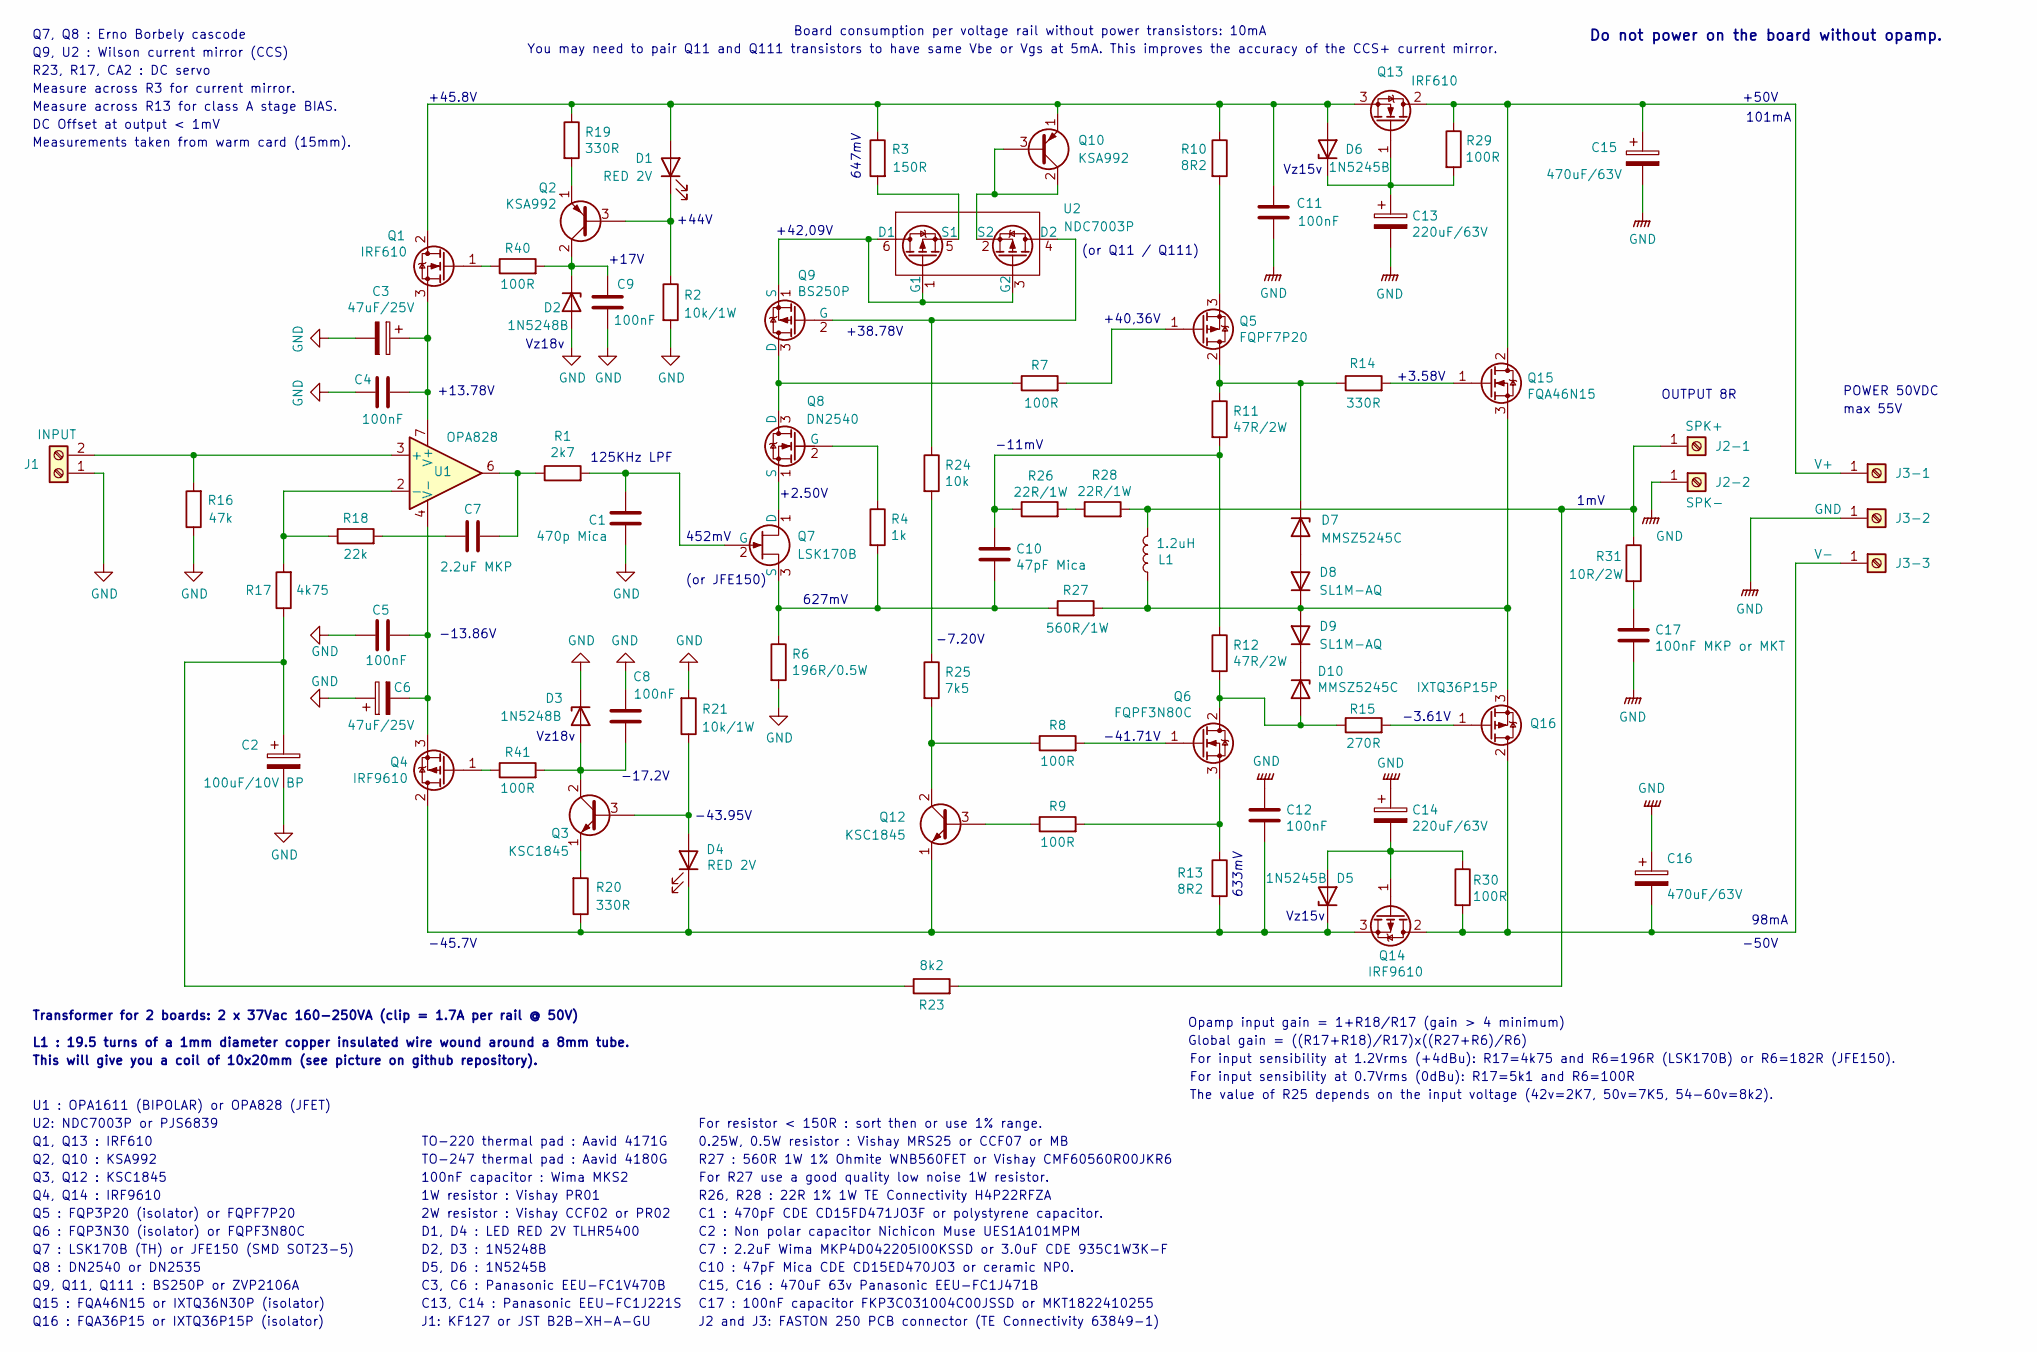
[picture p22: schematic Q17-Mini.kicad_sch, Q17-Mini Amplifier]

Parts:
C1: 470p Mica; C_Mica_v2_L11.4mm_W4.3mm_H9.1_P5.9mm_mix; Part# CD15FD471JO3; Mouser 5982-15-500V470
C2: 100uF/10V BP; CP_Radial_D10.0mm_P5.00mm; Part# UES1A101MPM; Mouser 647-UES1A101MPM
C3, C6: 47uF/25V; CP_Radial_D10.0mm_P2.50mm_P5.00mm; Part# EEU-FC1V470B; Mouser 667-EEU-FC1V470B
C4, C5, C8, C9, C11, C12: 100nF; C_Rect_L7.2mm_W2.5mm_P5.00mm_FKS2_FKP2_MKS2_MKP2; Part# MKS2D031001A00KSSD; Mouser 505-MKS2.1/100/10
C7: 2.2uF MKP; C_Rect_L26.5mm_W10.5mm_P22.50mm_MKS4; Part# MKP4D042205I00KSSD; Mouser 505-MKP4D042205I00KS
C10: 47pF Mica; C_Mica_v2_L11.4mm_W4.3mm_H9.1_P5.9mm_mix; Part# CD15ED470JO3F; Mouser 598-CD15ED470JO3F
C13, C14: 220uF/63V; CP_Radial_D12.5mm_P5.00mm; Part# EEU-FC1J221S; Mouser 667-EEU-FC1J221S
C15, C16: 470uF/63V; CP_Radial_D16.0mm_P7.50mm; Part# EEU-FC1J471B; Mouser 667-EEU-FC1J471B
C17: 100nF MKP or MKT; C_Rect_L18.0mm_W7.0mm_P15.00mm_FKS3_FKP3; Part# FKP3D031004D00JF00; Mouser 505-FKP3D03104D0JF0
D1, D4: RED 2V; LED_D5.0mm; Part# TLHR5400; Mouser 78-TLHR5400
D2, D3: 1N5248B; D_DO-35_SOD27_P7.62mm_Horizontal; Part# 1N5248B; Mouser 78-1N5248B
D5, D6: 1N5245B; D_DO-35_SOD27_P7.62mm_Horizontal; Part# 1N5245BTR; Mouser 512-1N5245BTR
D7, D10: MMSZ5245C; D_SOD-123; Part# MMSZ5245C-E3-18; Mouser 78-MMSZ5245C-E3-18
D8, D9: SL1M-AQ; D_SOD-123; Part# SL1M-AQ; Mouser 637-SL1M-AQ
J1: INPUT; Input_connector_mix_inverted; Part# Terminal Block Phoenix Contact 1755583; Mouser 651-1755583
J2-1: SPK+; Faston_Connector_63849-1_TEC; Part# TE Connectivity 63849-1; Mouser 571-638491
J2-2: SPK-; Faston_Connector_63849-1_TEC; Part# TE Connectivity 63849-1; Mouser 571-638491
J3-1: V+; Faston_Connector_63849-1_TEC; Part# TE Connectivity 63849-1; Mouser 571-638491
J3-2: GND; Faston_Connector_63849-1_TEC; Part# TE Connectivity 63849-1; Mouser 571-638491
J3-3: V-; Faston_Connector_63849-1_TEC; Part# TE Connectivity 63849-1; Mouser 571-638491
L1: 1.2uH; L_Axial_L22mm_D10mm_P21mm_vertical_Q17_Mini; Part# 19.5 turns of a 1mm diameter copper ins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; Mouser N.A
Q1, Q13: IRF610; TO-220-3_Vertical; Part# IRF610PBF; Mouser 844-IRF610PBF
Q2, Q10: KSA992; TO-92_Inline_Wide; Part# KSA992FTA; Mouser 512-KSA992FTA
Q3, Q12: KSC1845; TO-92_Inline_Wide; Part# KSC1845FTA; Mouser 512-KSC1845FTA
Q4, Q14: IRF9610; TO-220-3_Vertical; Part# IRF9610PBF; Mouser 844-IRF9610PBF
Q5: FQPF7P20; TO-220-3_Vertical; Part# FQPF7P20; Mouser 512-FQPF7P20
Q6: FQPF3N80C; TO-220-3_Vertical; Part# FQPF3N80C; Mouser 512-FQPF3N80C
Q7: LSK170B; TO-92_Inline_Wide; Part# LSK170B-TO-92-3L-BK; Mouser 722-LSK170BTO923LBK
Q8: DN2540; TO-92_Inline_Wide; Part# DN2540N3-G; Mouser 689-DN2540N3-G
Q9: BS250P; TO-92S_Wide; Part# BS250P; Mouser 522-BS250P
Q15: FQA46N15; TO-3P-3_Vertical; Part# FQA46N15; Mouser 512-FQA46N15
Q16: IXTQ36P15P; TO-3P-3_Vertical; Part# IXTQ36P15P; Mouser 747-IXTQ36P15P
R1: 2k7; R_Axial_DIN0207_L6.3mm_D2.5mm_P10.16mm_Horizontal; Part# MRS25000C2701FRP00; Mouser 594-MRS25000C2701FRP
R2, R21: 10k/1W; R_Axial_DIN0207_L6.3mm_D2.5mm_P10.16mm_Horizontal; Part# PR01000101002JR500; Mouser 594-5073NW10K00J
R3: 150R; R_Axial_DIN0207_L6.3mm_D2.5mm_P10.16mm_Horizontal; Part# MRS25000C1500FRP00; Mouser 594-MRS25000C1500FRP
R4: 1k; R_Axial_DIN0207_L6.3mm_D2.5mm_P10.16mm_Horizontal; Part# MRS25000C1001FRP00; Mouser 594-MRS25000C1001FRP
R6: 196R/0.5W; R_Axial_DIN0207_L6.3mm_D2.5mm_P10.16mm_Horizontal; Part# MRS25000C1960FCT00; Mouser 594-MRS25000C1960FCT
R7, R9, R29, R30, R40, R41: 100R; R_Axial_DIN0207_L6.3mm_D2.5mm_P10.16mm_Horizontal; Part# MRS25000C1000FCT00; Mouser 594-MRS25000C1000FCT
R8: 100R; R_Axial_DIN0207_L6.3mm_D2.5mm_P10.16mm_Horizontal; Part# MRS25000C1000FCT; Mouser 594-MRS25000C1000FCT
R10, R13: 8R2; R_Axial_DIN0207_L6.3mm_D2.5mm_P10.16mm_Horizontal; Part# MRS25000C8208FCT00; Mouser 594-MRS25000C8208FCT
R11, R12: 47R/2W; R_Axial_DIN0411_L9.9mm_D3.6mm_P12.70mm_Horizontal; Part# PR02000204709JR500; Mouser 594-5083NW47R00J
R14, R19, R20: 330R; R_Axial_DIN0207_L6.3mm_D2.5mm_P10.16mm_Horizontal; Part# MRS25000C3300FCT00; Mouser 594-MRS25000C3300FCT
R15: 270R; R_Axial_DIN0207_L6.3mm_D2.5mm_P10.16mm_Horizontal; Part# MRS25000C2700FCT00; Mouser 594-MRS25000C2700FCT
R16: 47k; R_Axial_DIN0207_L6.3mm_D2.5mm_P10.16mm_Horizontal; Part# MRS25000C4702FRP00; Mouser 594-MRS25000C4702FRP
R17: 4k75; R_Axial_DIN0207_L6.3mm_D2.5mm_P10.16mm_Horizontal; Part# MRS25000C4751FRP00; Mouser 594-MRS25000C4751FRP
R18: 22k; R_Axial_DIN0207_L6.3mm_D2.5mm_P10.16mm_Horizontal; Part# MRS25000C2202FCT00; Mouser 594-MRS25000C2202FCT
R23: 8k2; R_Axial_DIN0207_L6.3mm_D2.5mm_P10.16mm_Horizontal; Part# MRS25000C8201FRP00; Mouser 594-MRS25000C8201FRP
R24: 10k; R_Axial_DIN0207_L6.3mm_D2.5mm_P10.16mm_Horizontal; Part# MRS25000C1002FRP00; Mouser 594-MRS2510K00F
R25: 7k5; R_Axial_DIN0207_L6.3mm_D2.5mm_P10.16mm_Horizontal; Part# MRS25000C7501FRP00; Mouser 594-MRS25000C7501FRP
R26, R28: 22R/1W; R_Axial_DIN0411_L9.9mm_D3.6mm_P12.70mm_Horizontal; Part# H4P22RFZA; Mouser 279-H4P22RFZA
R27: 560R/1W; R_Axial_DIN0411_L9.9mm_D3.6mm_P12.70mm_Horizontal; Part# WNB560FET; Mouser 588-WNB560FET
R31: 10R/2W; R_Axial_DIN0411_L9.9mm_D3.6mm_P15.24mm_Horizontal; Part# PR02000201009JR500; Mouser 594-5083NW10R00J
U1: OPA828; SOIC-8_3.9x4.9mm_P1.27mm; Part# OPA828IDR; Mouser 595-OPA828IDR
U2: NDC7003P; NDC7003P-TSOT23-6; Part# NDC7003P; Mouser 512-NDC7003P

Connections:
GND: C1.2, C2.2, C3.2, C4.1, C5.1, C6.1, C8.1, C9.1, C11.1, C12.1, C13.2, C14.1, C15.2, C16.1, C17.2, D2.2 (A), D3.1 (K), J1.1, J2-2.1, J3-2.1, R2.2, R6.2, R16.1, R21.2; also elsewhere on the board
unnamed: C2.1, R17.1, R23.1
unnamed: C7.1, R18.2
unnamed 3: C7.2, R1.1, U1.6; also elsewhere on the board
unnamed: C10.1, R11.2, R12.1, R26.1
unnamed: C17.1, R31.2
unnamed 6: C11.2, D1.2 (A), D6.2 (A), Q1.2 (D), Q10.1 (E), Q13.3 (S), R3.1, R10.1, R19.1; also elsewhere on the board
unnamed: D1.1 (K), Q2.3 (B), R2.1
unnamed: C9.2, D2.1 (K), Q2.2 (C), R40.2
unnamed: C8.2, D3.2 (A), Q3.2 (C), R41.2
unnamed: D4.2 (A), Q3.3 (B), R21.1
unnamed 11: C12.2, D4.1 (K), D5.1 (K), Q4.2 (D), Q12.1 (E), Q14.3 (S), R13.2, R20.1; also elsewhere on the board
unnamed: C14.2, D5.2 (A), Q14.1 (G), R30.1
unnamed: C13.1, D6.1 (K), Q13.1 (G), R29.2
unnamed: D7.2 (A), D8.2 (A)
unnamed: D7.1 (K), Q5.2 (D), R11.1, R14.1
unnamed: D8.1 (K), D9.2 (A), L1.1, Q15.3 (S), Q16.3 (S), R27.2
unnamed: D10.2 (A), Q6.2 (D), R12.2, R15.1
unnamed: D9.1 (K), D10.1 (K)
unnamed 19: J1.2, R16.2, U1.3 (+); also elsewhere on the board
unnamed: J2-1.1, L1.2, R23.2, R28.2, R31.1
unnamed: C15.1, J3-1.1, Q13.2 (D), Q15.2 (D), R29.1
unnamed: C16.2, J3-3.1, Q14.2 (D), Q16.2 (D), R30.2
unnamed 23: Q1.1 (G), R40.1; also elsewhere on the board
unnamed 24: C3.1, C4.2, Q1.3 (S), U1.7 (V+); also elsewhere on the board
unnamed: Q2.1 (E), R19.2
unnamed: Q3.1 (E), R20.2
unnamed 27: Q4.1 (G), R41.1; also elsewhere on the board
unnamed 28: C5.2, C6.2, Q4.3 (S), U1.4 (V-); also elsewhere on the board
unnamed: Q5.1 (G), R7.2
unnamed: Q5.3 (S), R10.2
unnamed: Q6.1 (G), R8.2
unnamed: Q6.3 (S), R9.2, R13.1
unnamed 33: Q7.1 (D), Q8.1 (S); also elsewhere on the board
unnamed 34: C1.1, Q7.2 (G), R1.2; also elsewhere on the board
unnamed 35: C10.2, Q7.3 (S), R4.2, R6.1, R27.1; also elsewhere on the board
unnamed: Q8.3 (D), Q9.3 (D), R7.1
unnamed: Q8.2 (G), R4.1
unnamed 38: Q9.2 (G), R24.1, U2.4 (D2); also elsewhere on the board
unnamed 39: Q9.1 (S), U2.1 (G1), U2.3 (G2), U2.6 (D1); also elsewhere on the board
unnamed 40: Q10.2 (C), Q10.3 (B), U2.2 (S2); also elsewhere on the board
unnamed: Q12.3 (B), R9.1
unnamed: Q12.2 (C), R8.1, R25.2
unnamed: Q15.1 (G), R14.2
unnamed: Q16.1 (G), R15.2
unnamed: R24.2, R25.1
unnamed: R26.2, R28.1
unnamed 47: R17.2, R18.1, U1.2 (-); also elsewhere on the board
unnamed 48: R3.2, U2.5 (S1); also elsewhere on the board

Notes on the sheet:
-43.95V
Q15 : FQA46N15 or IXTQ36N30P (isolator)
452mV
+2.50V
max 55V
-17.2V
The value of R25 depends on the input voltage (42v=2K7, 50v=7K5, 54-60v=8k2).
1W resistor : Vishay PR01
-11mV
Q3, Q12 : KSC1845
-50V
U2: NDC7003P or PJS6839
This will give you a coil of 10x20mm (see picture on github repository).
-3.61V
Q5 : FQP3P20 (isolator) or FQPF7P20
+45.8V
125KHz LPF
R26, R28 : 22R 1% 1W TE Connectivity H4P22RFZA
627mV
TO-247 thermal pad : Aavid 4180G
(or JFE150)
Q1, Q13 : IRF610
D5, D6 : 1N5245B
C2 : Non polar capacitor Nichicon Muse UES1A101MPM
D2, D3 : 1N5248B
D1, D4 : LED RED 2V TLHR5400
For input sensibility at 0.7Vrms (0dBu): R17=5k1 and R6=100R
C3, C6 : Panasonic EEU-FC1V470B
J1: KF127 or JST B2B-XH-A-GU
U1 : OPA1611 (BIPOLAR) or OPA828 (JFET)
-7.20V
Board consumption per voltage rail without power transistors: 10mA
+3.58V
Q8 : DN2540 or DN2535
L1 : 19.5 turns of a 1mm diameter copper insulated wire wound around a 8mm tube.
Global gain = ((R17+R18)/R17)x((R27+R6)/R6)
Q6 : FQP3N30 (isolator) or FQPF3N80C
Q9, U2 : Wilson current mirror (CCS)
Transformer for 2 boards: 2 x 37Vac 160-250VA (clip = 1.7A per rail @ 50V)
For resistor < 150R : sort then or use 1% range.

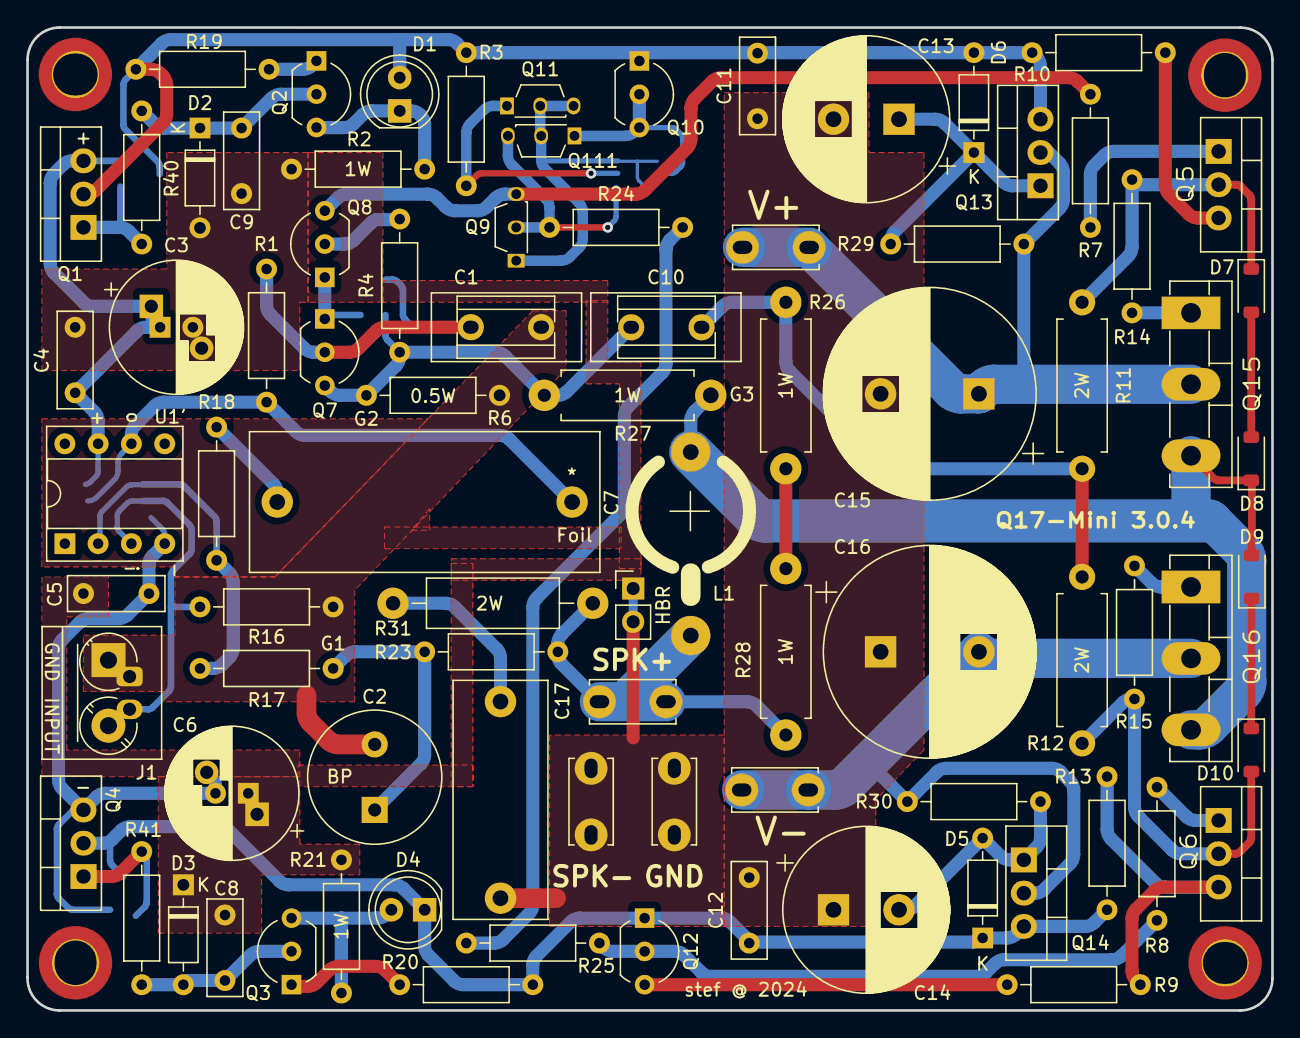
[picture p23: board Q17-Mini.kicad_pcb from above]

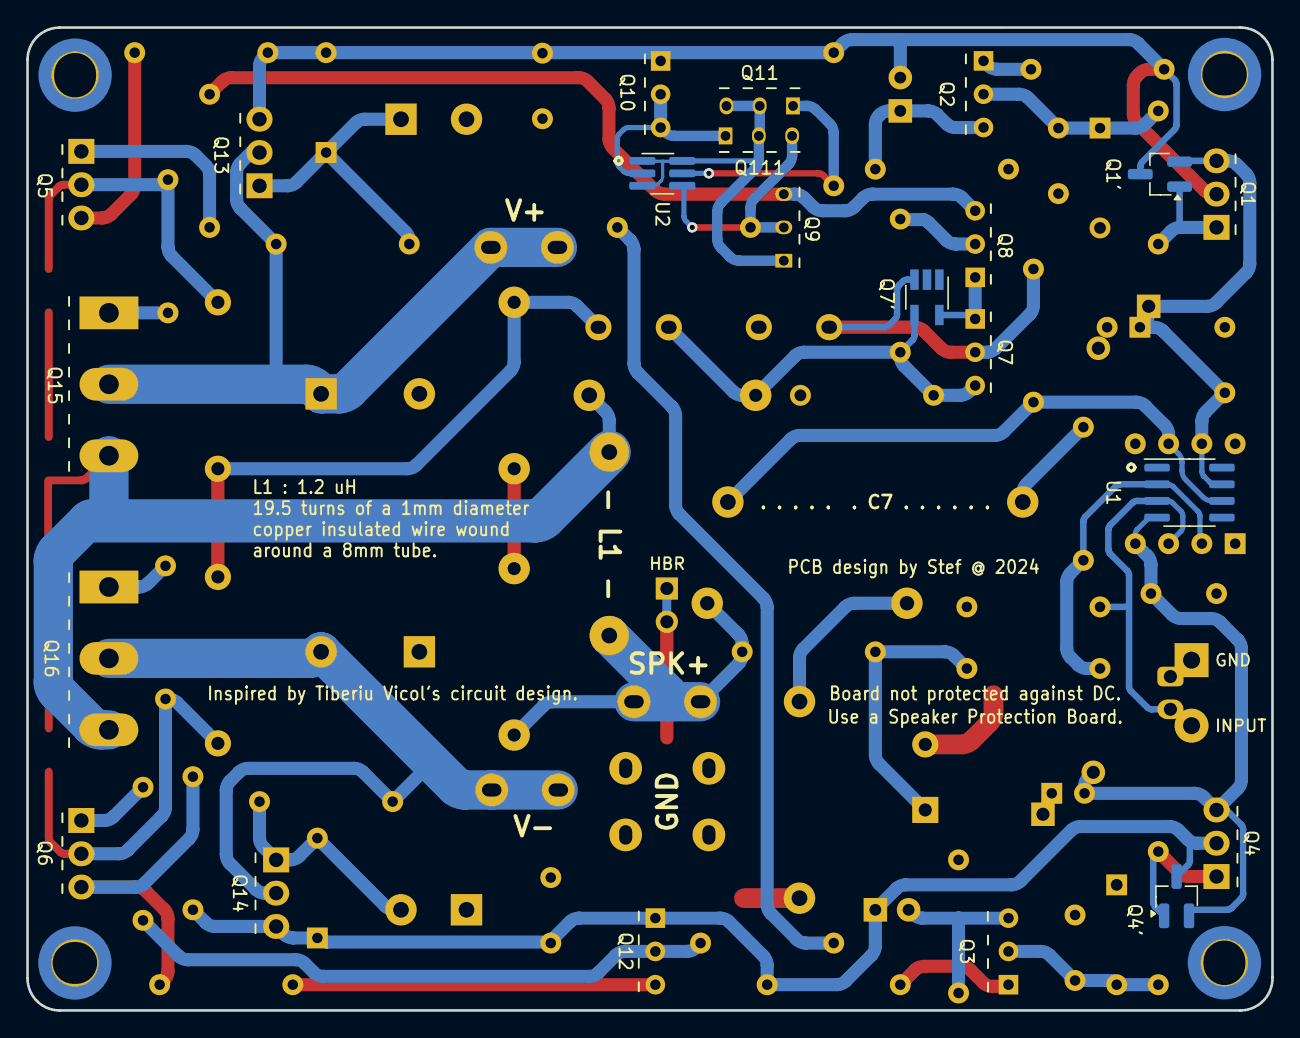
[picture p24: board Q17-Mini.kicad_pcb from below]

Board: 2 copper layers, 95.0 x 75.0 mm, 93 parts (5 on the bottom side), 49 nets.

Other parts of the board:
H1, H2, H4: MountingHole; MountingHole_3.2mm_M3_DIN965_Pad_TopBottom
H3: MountingHole_3.2mm_M3_DIN965_Pad_TopBottom
HBR: PinHeader_1x02_P2.54mm_Vertical
Q1': SI2328DS; SOT-23_Handsoldering
Q4': SI2325DS; SOT-23_Handsoldering
Q7': JFE150; SOT-23-5_HandSoldering
Q11, Q111: BS250P; TO-92S_Wide
U1': OPA828; DIP-8_W7.62mm_Socket

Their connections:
GND: HBR.1, HBR.2; also elsewhere on the board
unnamed 3: U1'.6; also elsewhere on the board
unnamed 6: Q1'.3; also elsewhere on the board
unnamed 11: Q4'.3; also elsewhere on the board
unnamed 19: U1'.3 (+); also elsewhere on the board
unnamed 23: Q1'.1; also elsewhere on the board
unnamed 24: Q1'.2, U1'.7 (V+); also elsewhere on the board
unnamed 27: Q4'.1; also elsewhere on the board
unnamed 28: Q4'.2, U1'.4 (V-); also elsewhere on the board
unnamed 33: Q7'.5; also elsewhere on the board
unnamed 34: Q7'.3; also elsewhere on the board
unnamed 35: Q7'.4; also elsewhere on the board
unnamed 38: Q111.3 (D); also elsewhere on the board
unnamed 39: Q11.2 (G), Q11.3 (D), Q111.2 (G); also elsewhere on the board
unnamed 40: Q111.1 (S); also elsewhere on the board
unnamed 47: U1'.2 (-); also elsewhere on the board
unnamed 48: Q11.1 (S); also elsewhere on the board

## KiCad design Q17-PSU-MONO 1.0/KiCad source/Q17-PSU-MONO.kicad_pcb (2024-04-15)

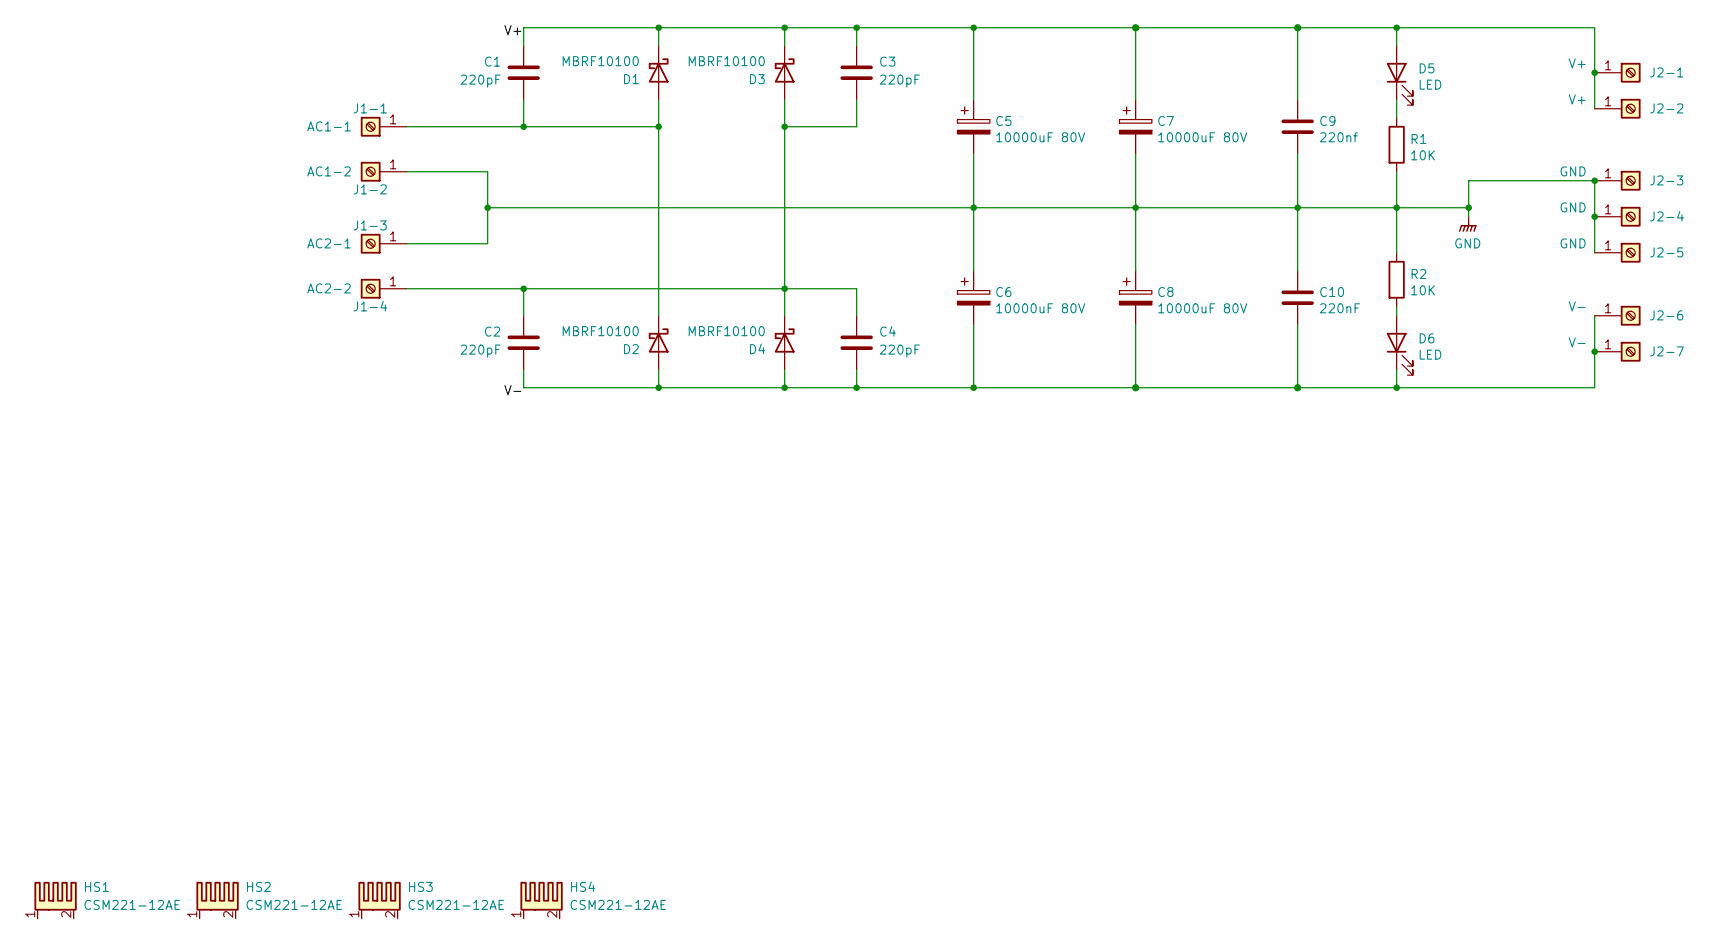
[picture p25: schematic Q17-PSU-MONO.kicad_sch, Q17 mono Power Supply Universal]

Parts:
C1, C2, C3, C4: 220pF; C_Disc_D6.0mm_W4.4mm_P5.00mm; Part# FG28C0G2A221JNT06; Mouser 810-FG28C0G2A221JNT6
C5, C6, C7, C8: 10000uF 80V; CP_Radial_D35.0mm_P10.00mm_SnapIn; Part# 380LX103M080A052; Mouser 598-380LX103M080A052
C9: 220nf; C_Rect_Q17_PSU_L26.50_H11.00_P20.50; Part# MPX224K305E; Mouser 598-MPX224K305E
C10: 220nF; C_Rect_Q17_PSU_L26.50_H11.00_P20.50; Part# MPX224K305E; Mouser 598-MPX224K305E
D1, D2, D3, D4: MBRF10100; TO-220-2_Vertical; Part# MBRF10100-M3/4W; Mouser 78-MBRF10100-M34W
D5, D6: LED; LED_D5.0mm; Part# TLHR5400; Mouser 78-TLHR5400
HS1, HS2, HS3, HS4: CSM221-12AE; CSM22112AE; Part# CSM221-12AE; Mouser 588-CSM221-12AE
J1-1: AC1-1; Faston_Connector_63849-1_TEC; Part# TE Connectivity 63849-1; Mouser 571-638241
J1-2: AC1-2; Faston_Connector_63849-1_TEC; Part# TE Connectivity 63849-1; Mouser 571-638241
J1-3: AC2-1; Faston_Connector_63849-1_TEC; Part# TE Connectivity 63849-1; Mouser 571-638241
J1-4: AC2-2; Faston_Connector_63849-1_TEC; Part# TE Connectivity 63849-1; Mouser 571-638241
J2-1, J2-2: V+; Faston_Connector_63849-1_TEC; Part# TE Connectivity 63849-1; Mouser 571-638241
J2-3, J2-4, J2-5: GND; Faston_Connector_63849-1_TEC; Part# TE Connectivity 63849-1; Mouser 571-638241
J2-6, J2-7: V-; Faston_Connector_63849-1_TEC; Part# TE Connectivity 63849-1; Mouser 571-638241
R1, R2: 10K; R_Axial_DIN0207_L6.3mm_D2.5mm_P10.16mm_Horizontal; Part# PR01000101002JR500; Mouser 594-5073NW10K00J

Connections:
/V+: C1.1, C3.1, C5.1, C7.1, C9.1, D1.1 (K), D3.1 (K), D5.2 (A), J2-1.1, J2-2.1
/V-: C2.2, C4.2, C6.2, C8.2, C10.2, D2.2 (A), D4.2 (A), D6.1 (K), J2-6.1, J2-7.1
GND: C5.2, C6.1, C7.2, C8.1, C9.2, C10.1, J1-2.1, J1-3.1, J2-3.1, J2-4.1, J2-5.1, R1.2, R2.1
unnamed: C1.2, D1.2 (A), D2.1 (K), J1-1.1
unnamed: C2.1, C3.2, C4.1, D3.2 (A), D4.1 (K), J1-4.1
unnamed: D5.1 (K), R1.1
unnamed: D6.2 (A), R2.2

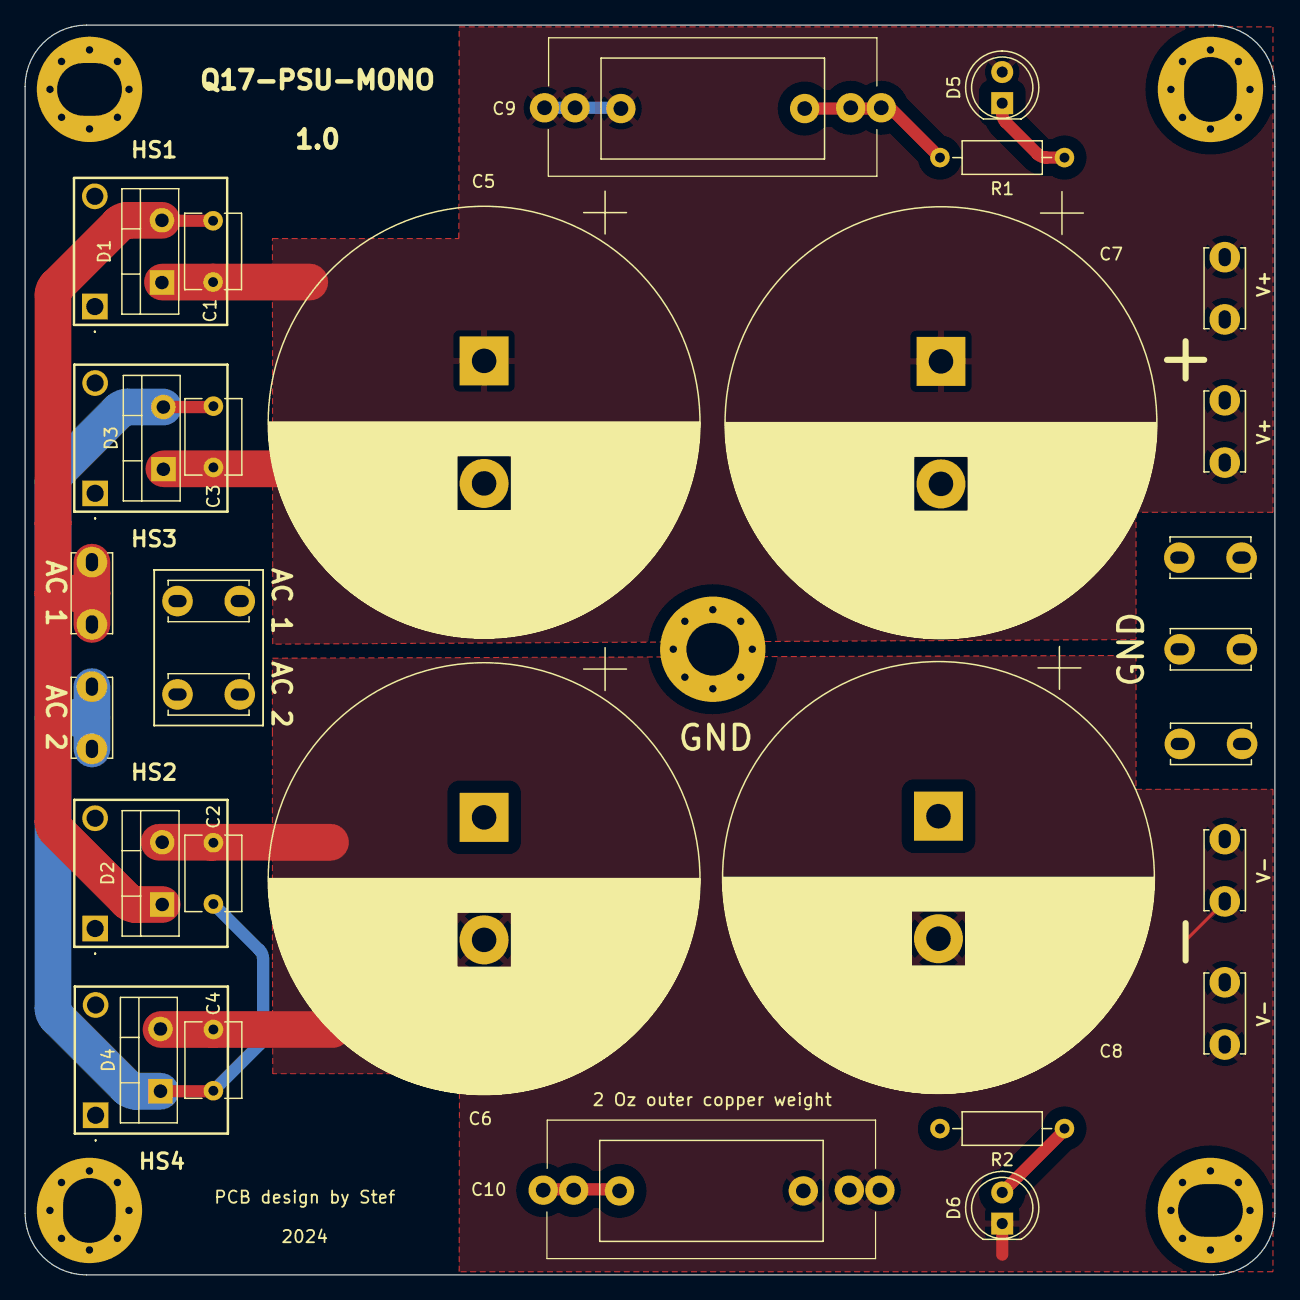
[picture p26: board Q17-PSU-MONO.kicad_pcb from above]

Board: 2 copper layers, 102.0 x 102.0 mm, 33 parts (0 on the bottom side), 7 nets.

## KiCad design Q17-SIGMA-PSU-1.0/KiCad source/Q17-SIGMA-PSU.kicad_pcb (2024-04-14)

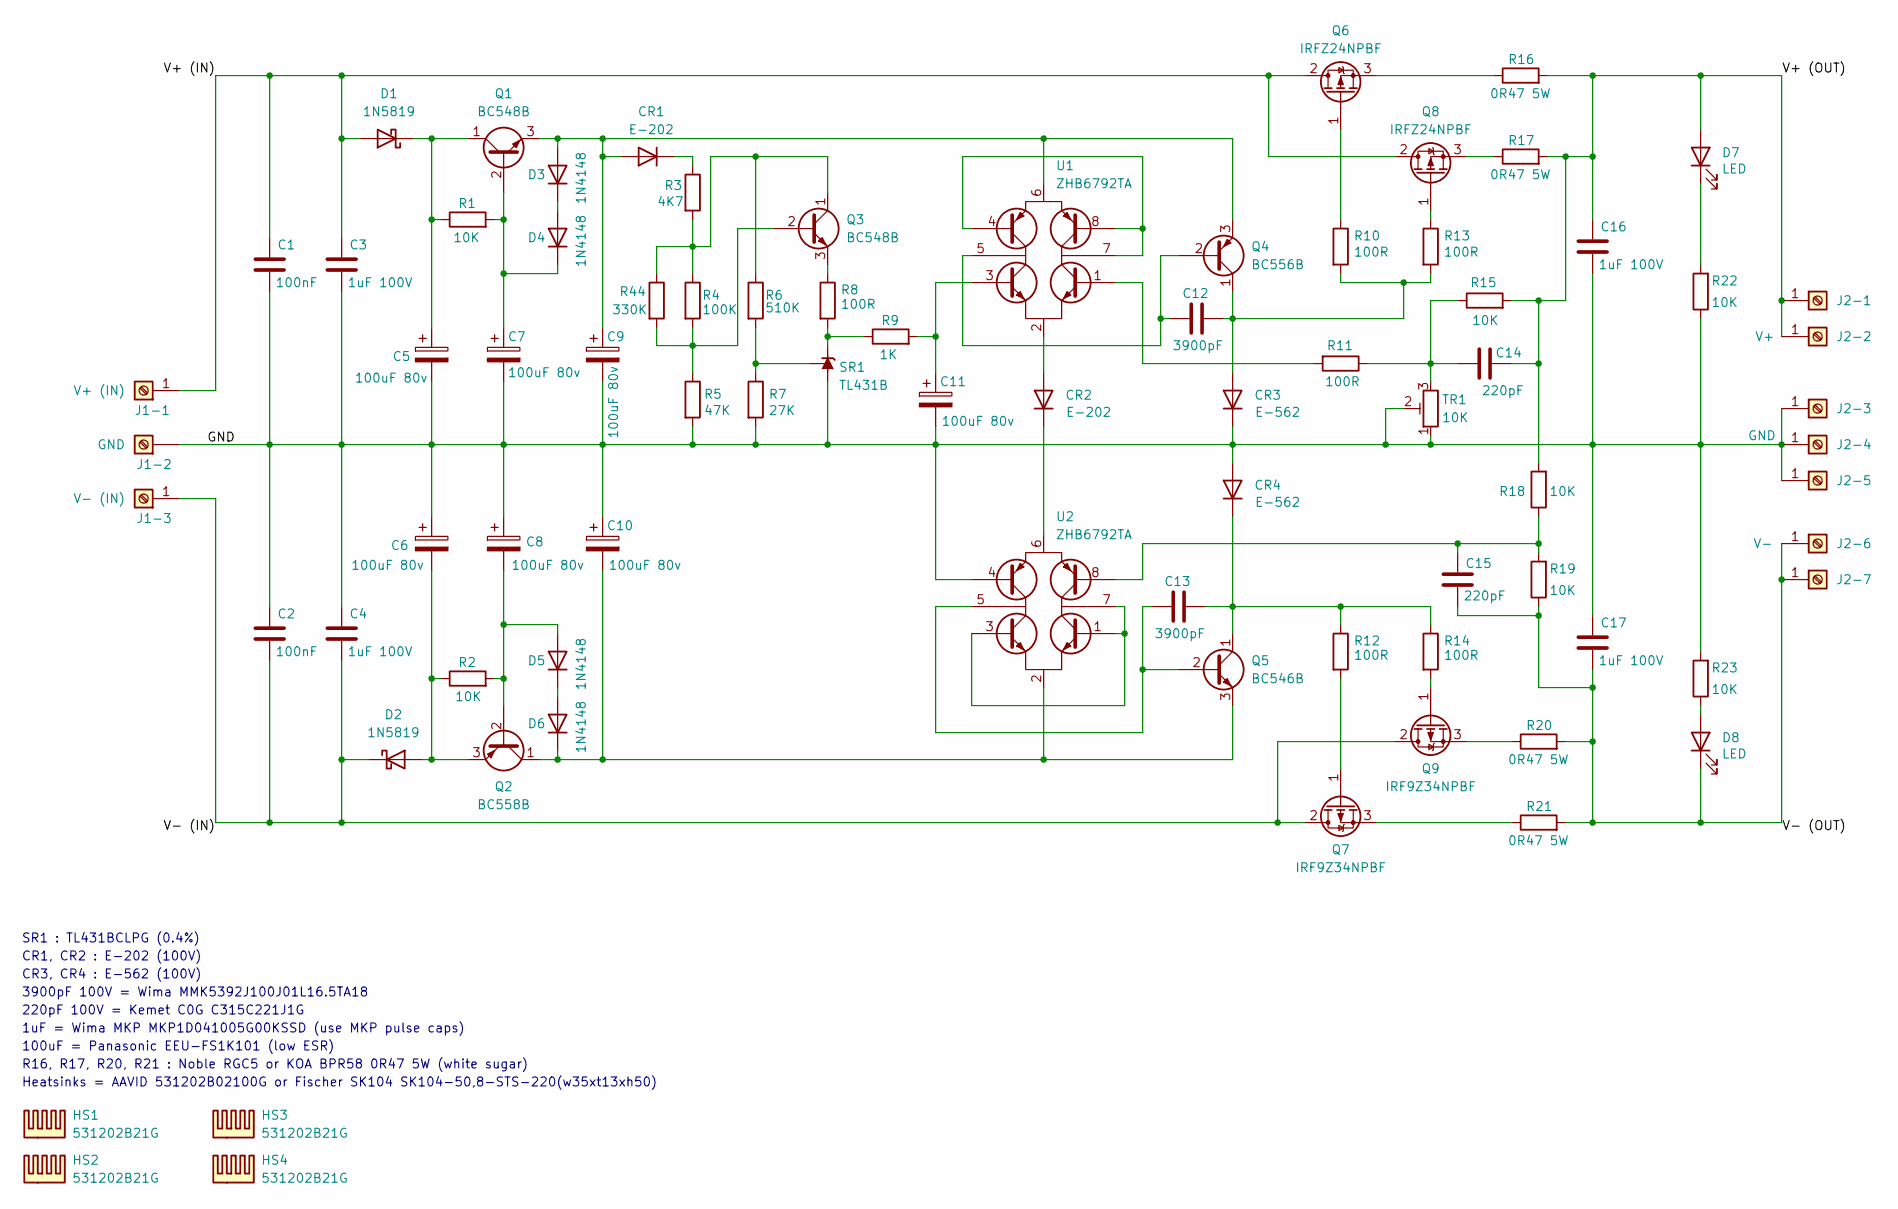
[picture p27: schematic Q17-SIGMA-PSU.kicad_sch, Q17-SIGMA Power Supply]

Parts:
C1, C2: 100nF; C_Rect_L7.2mm_W2.5mm_P5.00mm_FKS2_FKP2_MKS2_MKP2; Part# MKS2D031001A00KSSD; Mouser 505-MKS2.1/100/10
C3, C4, C16, C17: 1uF 100V; C_Rect_L26.5mm_W10.5mm_P22.50mm_MKS4; Part# MKP1D041005G00KSSD; Mouser 505-MKP1D041005G00KS
C5, C6, C7, C8, C9, C10, C11: 100uF 80v; CP_Radial_D10.0mm_P5.00mm; Part# EEU-FS1K101; Mouser 667-EEU-FS1K101
C12, C13: 3900pF; C_Rect_L7.2mm_W2.5mm_P5.00mm_FKS2_FKP2_MKS2_MKP2; Part# MMK5392J100J01L16.5TA18; Mouser 80-MMK5392J100J1TA18
C14, C15: 220pF; C_Disc_D3.8mm_W2.6mm_P2.50mm; Part# C315C221J1G; Mouser 80-C315C221J1G
CR1, CR2: E-202; D_DO-35_SOD27_P7.62mm_Horizontal; Part# E-202; Mouser 954-E-202
CR3, CR4: E-562; D_DO-35_SOD27_P7.62mm_Horizontal; Part# E-562; Mouser 954-E-562
D1, D2: 1N5819; D_DO-41_SOD81_P10.16mm_Horizontal; Part# 1N5819-E3/73; Mouser 625-1N5819-E3/73
D3, D4, D5, D6: 1N4148; D_DO-35_SOD27_P7.62mm_Horizontal; Part# 1N4148-TAP; Mouser 78-1N4148-TAP
D7, D8: LED; LED_D5.0mm; Part# TLHR5400; Mouser 78-TLHR5400
HS1, HS2, HS3, HS4: 531202B21G; Heatsink_Fischer_SK104-STC-STIC_35x13mm_2xDrill2.5mm; Part# 531202B21G; Mouser 532-531202B21G
J1-1: V+ (IN); Faston_Connector_63849-1_TEC; Part# TE Connectivity 63849-1; Mouser 571-638241
J1-2, J2-3, J2-4, J2-5: GND; Faston_Connector_63849-1_TEC; Part# TE Connectivity 63849-1; Mouser 571-638241
J1-3: V- (IN); Faston_Connector_63849-1_TEC; Part# TE Connectivity 63849-1; Mouser 571-638241
J2-1, J2-2: V+; Faston_Connector_63849-1_TEC; Part# TE Connectivity 63849-1; Mouser 571-638241
J2-6, J2-7: V-; Faston_Connector_63849-1_TEC; Part# TE Connectivity 63849-1; Mouser 571-638241
Q1, Q3: BC548B; TO-92L_Inline_Wide; Part# BC548BTA; Mouser 512-BC548BTA
Q2: BC558B; TO-92L_Inline_Wide; Part# BC558B; Mouser 637-BC558B
Q4: BC556B; TO-92L_Inline_Wide; Part# BC556BTA; Mouser 512-BC556BTA
Q5: BC546B; TO-92L_Inline_Wide; Part# BC546BTA; Mouser 512-BC546BTA
Q6, Q8: IRFZ24NPBF; TO-220-3_Vertical; Part# IRFZ24NPBF; Mouser 942-IRFZ24NPBF
Q7, Q9: IRF9Z34NPBF; TO-220-3_Vertical; Part# IRF9Z34NPBF; Mouser 942-IRF9Z34NPBF
R1, R2, R15, R18, R19, R22, R23: 10K; R_Axial_DIN0207_L6.3mm_D2.5mm_P10.16mm_Horizontal; Part# MRS25000C1002FRP00; Mouser 594-MRS2510K00F
R3: 4K7; R_Axial_DIN0207_L6.3mm_D2.5mm_P10.16mm_Horizontal; Part# MRS25000C1009FRP00; Mouser 594-MRS25000C1009FRP
R4: 100K; R_Axial_DIN0207_L6.3mm_D2.5mm_P10.16mm_Horizontal; Part# MRS25000C1003FRP00; Mouser 594-MRS25000C1003FRP
R5: 47K; R_Axial_DIN0207_L6.3mm_D2.5mm_P10.16mm_Horizontal; Part# MRS25000C4702FRP00; Mouser 594-MRS25000C4702FRP
R6: 510K; R_Axial_DIN0207_L6.3mm_D2.5mm_P10.16mm_Horizontal; Part# MRS25000C5103FCT00; Mouser 594-MRS25000C5103FCT
R7: 27K; R_Axial_DIN0207_L6.3mm_D2.5mm_P10.16mm_Horizontal; Part# MRS25000C1009FRP00; Mouser 594-MRS25000C1009FRP
R8, R10, R11, R12, R13, R14: 100R; R_Axial_DIN0207_L6.3mm_D2.5mm_P10.16mm_Horizontal; Part# MRS25000C1000FRP00; Mouser 594-MRS25000C1000FRP
R9: 1K; R_Axial_DIN0207_L6.3mm_D2.5mm_P10.16mm_Horizontal; Part# MRS25000C1009FRP00; Mouser 594-MRS25000C1009FRP
R16, R17, R20, R21: 0R47 5W; R_Box_L14.0mm_W5.0mm_P9.00mm; Part# BPR58CR47J; Mouser 660-BPR58CR47J
R44: 330K; R_Axial_DIN0207_L6.3mm_D2.5mm_P10.16mm_Horizontal; Part# MRS25000C3303FCT00; Mouser 594-MRS25000C3303FCT
SR1: TL431B; TO-92L_Inline_Wide; Part# TL431BCLPG; Mouser 863-TL431BCLPG
TR1: 10K; Potentiometer_Bourns_3296W_Vertical; Part# 3296W-1-103LF; Mouser 652-3296W-1-103LF
U1, U2: ZHB6792TA; TSOT-23-8_HandSoldering; Part# ZHB6792TA; Mouser 522-ZHB6792TA

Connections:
/GND: C1.2, C2.1, C3.2, C4.1, C5.2, C6.1, C7.2, C8.1, C9.2, C10.1, C11.2, C16.2, C17.1, CR3.1 (K), CR4.2 (A), J1-2.1, J2-3.1, J2-4.1, J2-5.1, R5.2, R7.2, R22.1, R23.2, SR1.2 (A), TR1.1, TR1.2, U2.4 (B1)
/V+ (IN): C1.1, C3.1, D1.2 (A), J1-1.1, Q6.2 (D), Q8.2 (D)
/V+ (OUT): C14.2, C16.1, D7.2 (A), J2-1.1, J2-2.1, R15.2, R16.2, R17.2, R18.2
/V- (IN): C2.2, C4.2, D2.1 (K), J1-3.1, Q7.2 (D), Q9.2 (D)
/V- (OUT): C15.2, C17.2, D8.1 (K), J2-6.1, J2-7.1, R19.1, R20.2, R21.2
unnamed: C14.1, R11.1, R15.1, TR1.3
unnamed: C9.1, CR1.2 (A), D3.2 (A), Q1.3 (E), Q4.3 (E), U1.6 (E1,_E4)
unnamed: CR1.1 (K), R3.1
unnamed: CR2.2 (A), U1.2 (E2,_E3)
unnamed: CR2.1 (K), U2.6 (E1,_E4)
unnamed: C12.2, CR3.2 (A), Q4.1 (C), R10.2, R13.2
unnamed: C13.2, CR4.1 (K), Q5.1 (C), R12.1, R14.1
unnamed: C5.1, D1.1 (K), Q1.1 (C), R1.1
unnamed: C6.2, D2.2 (A), Q2.3 (E), R2.1
unnamed: D3.1 (K), D4.2 (A)
unnamed: C7.1, D4.1 (K), Q1.2 (B), R1.2
unnamed: C8.2, D5.2 (A), Q2.2 (B), R2.2
unnamed: D5.1 (K), D6.2 (A)
unnamed: C10.2, D6.1 (K), Q2.1 (C), Q5.3 (E), U2.2 (E2,_E3)
unnamed: D7.1 (K), R22.2
unnamed: D8.2 (A), R23.1
unnamed: Q3.2 (B), R4.2, R5.1, R44.2
unnamed: Q3.1 (C), R3.2, R4.1, R6.1, R44.1
unnamed: Q3.3 (E), R8.1
unnamed: C12.1, Q4.2 (B), U1.5 (C2,_C1)
unnamed: C13.1, Q5.2 (B), U2.5 (C2,_C1)
unnamed: Q6.1 (G), R10.1
unnamed: Q6.3 (S), R16.1
unnamed: Q7.1 (G), R12.2
unnamed: Q7.3 (S), R21.1
unnamed: Q8.1 (G), R13.1
unnamed: Q8.3 (S), R17.1
unnamed: Q9.1 (G), R14.2
unnamed: Q9.3 (S), R20.1
unnamed: R8.2, R9.1, SR1.3 (K)
unnamed: R6.2, R7.1, SR1.1 (REF)
unnamed: U1.4 (B1), U1.7 (C3,_C4), U1.8 (B4)
unnamed: C11.1, R9.2, U1.3 (B2)
unnamed: R11.2, U1.1 (B3)
unnamed: U2.1 (B3), U2.3 (B2), U2.7 (C3,_C4)
unnamed: C15.1, R18.1, R19.2, U2.8 (B4)

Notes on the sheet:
1uF = Wima MKP MKP1D041005G00KSSD (use MKP pulse caps)
SR1 : TL431BCLPG (0.4%)
100uF = Panasonic EEU-FS1K101 (low ESR)
3900pF 100V = Wima MMK5392J100J01L16.5TA18
CR3, CR4 : E-562 (100V)
R16, R17, R20, R21 : Noble RGC5 or KOA BPR58 0R47 5W (white sugar)
CR1, CR2 : E-202 (100V)
220pF 100V = Kemet C0G C315C221J1G
Heatsinks = AAVID 531202B02100G or Fischer SK104 SK104-50,8-STS-220(w35xt13xh50)

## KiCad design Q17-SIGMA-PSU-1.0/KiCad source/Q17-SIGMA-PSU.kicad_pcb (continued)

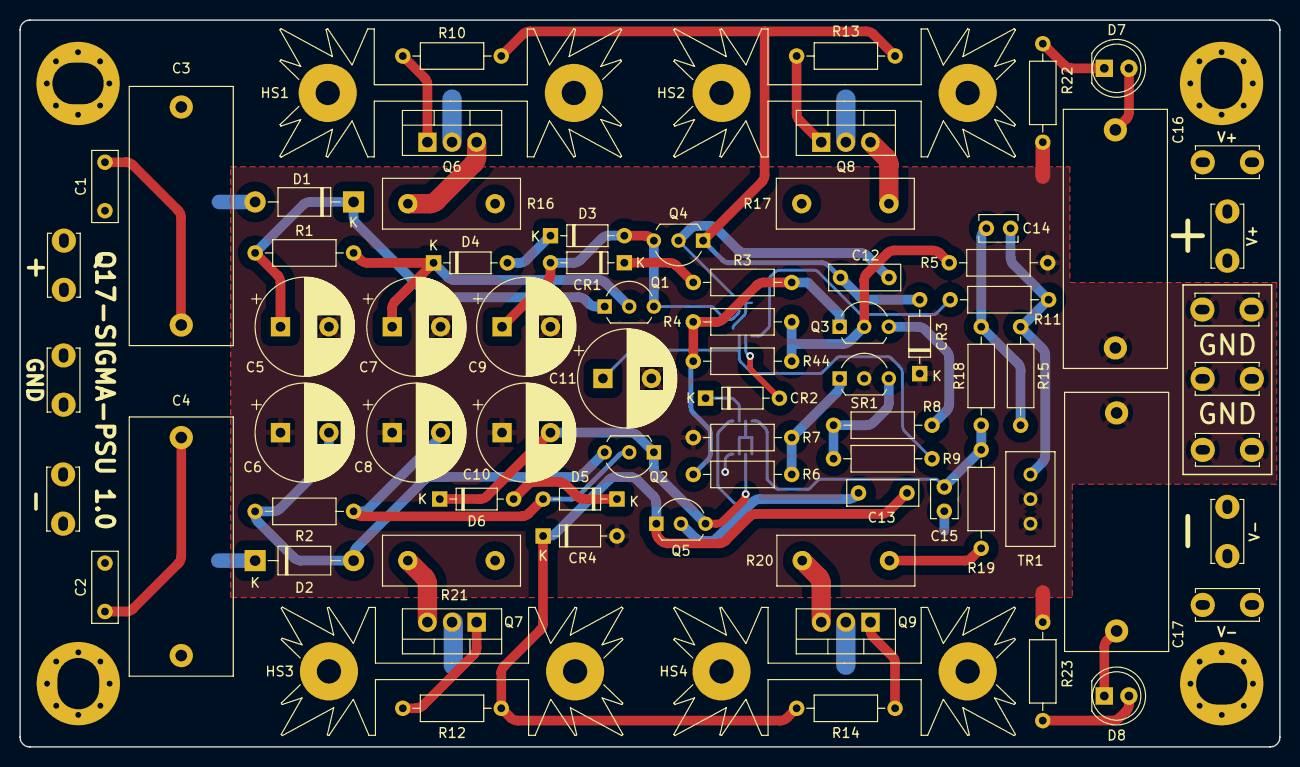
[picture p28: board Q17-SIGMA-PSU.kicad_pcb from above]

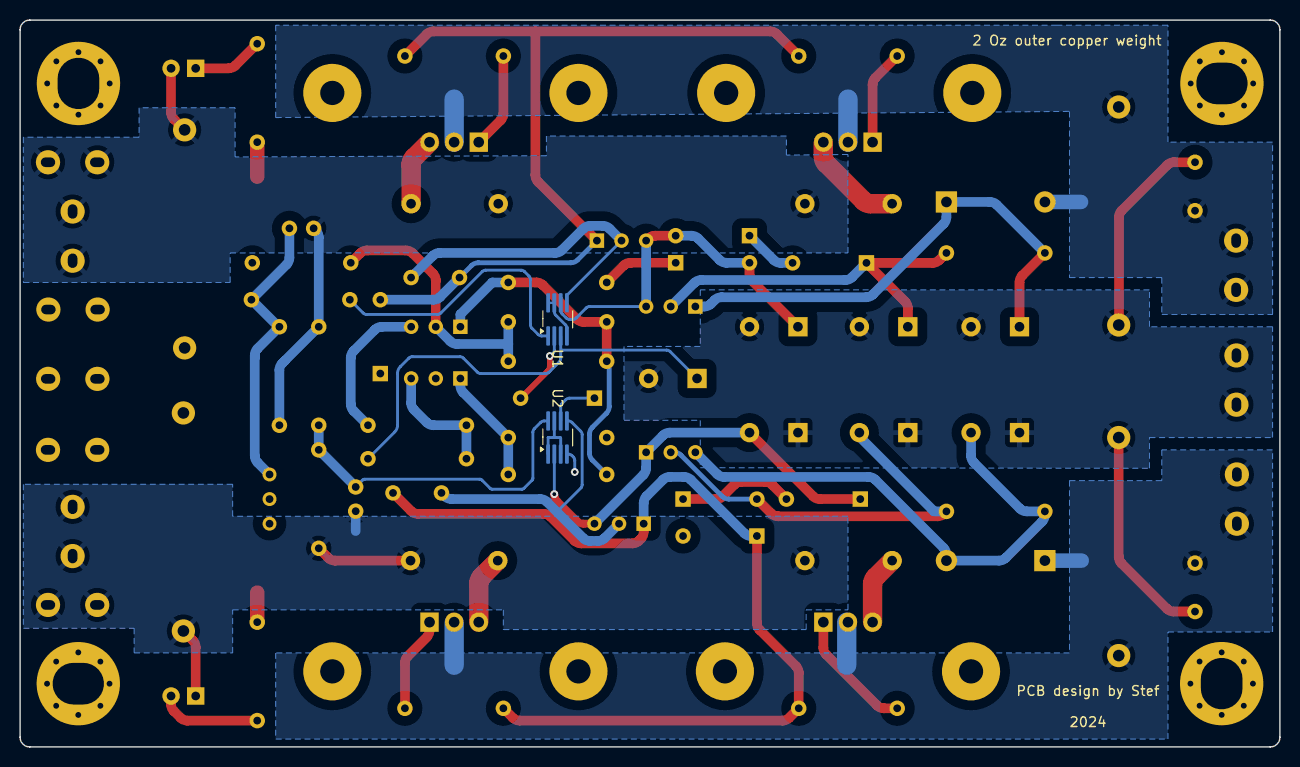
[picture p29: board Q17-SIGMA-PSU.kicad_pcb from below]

Board: 2 copper layers, 130.0 x 75.0 mm, 82 parts (2 on the bottom side), 41 nets.

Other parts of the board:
PAD1, PAD2: MountingHole_4.3mm_M4_Pad_Via

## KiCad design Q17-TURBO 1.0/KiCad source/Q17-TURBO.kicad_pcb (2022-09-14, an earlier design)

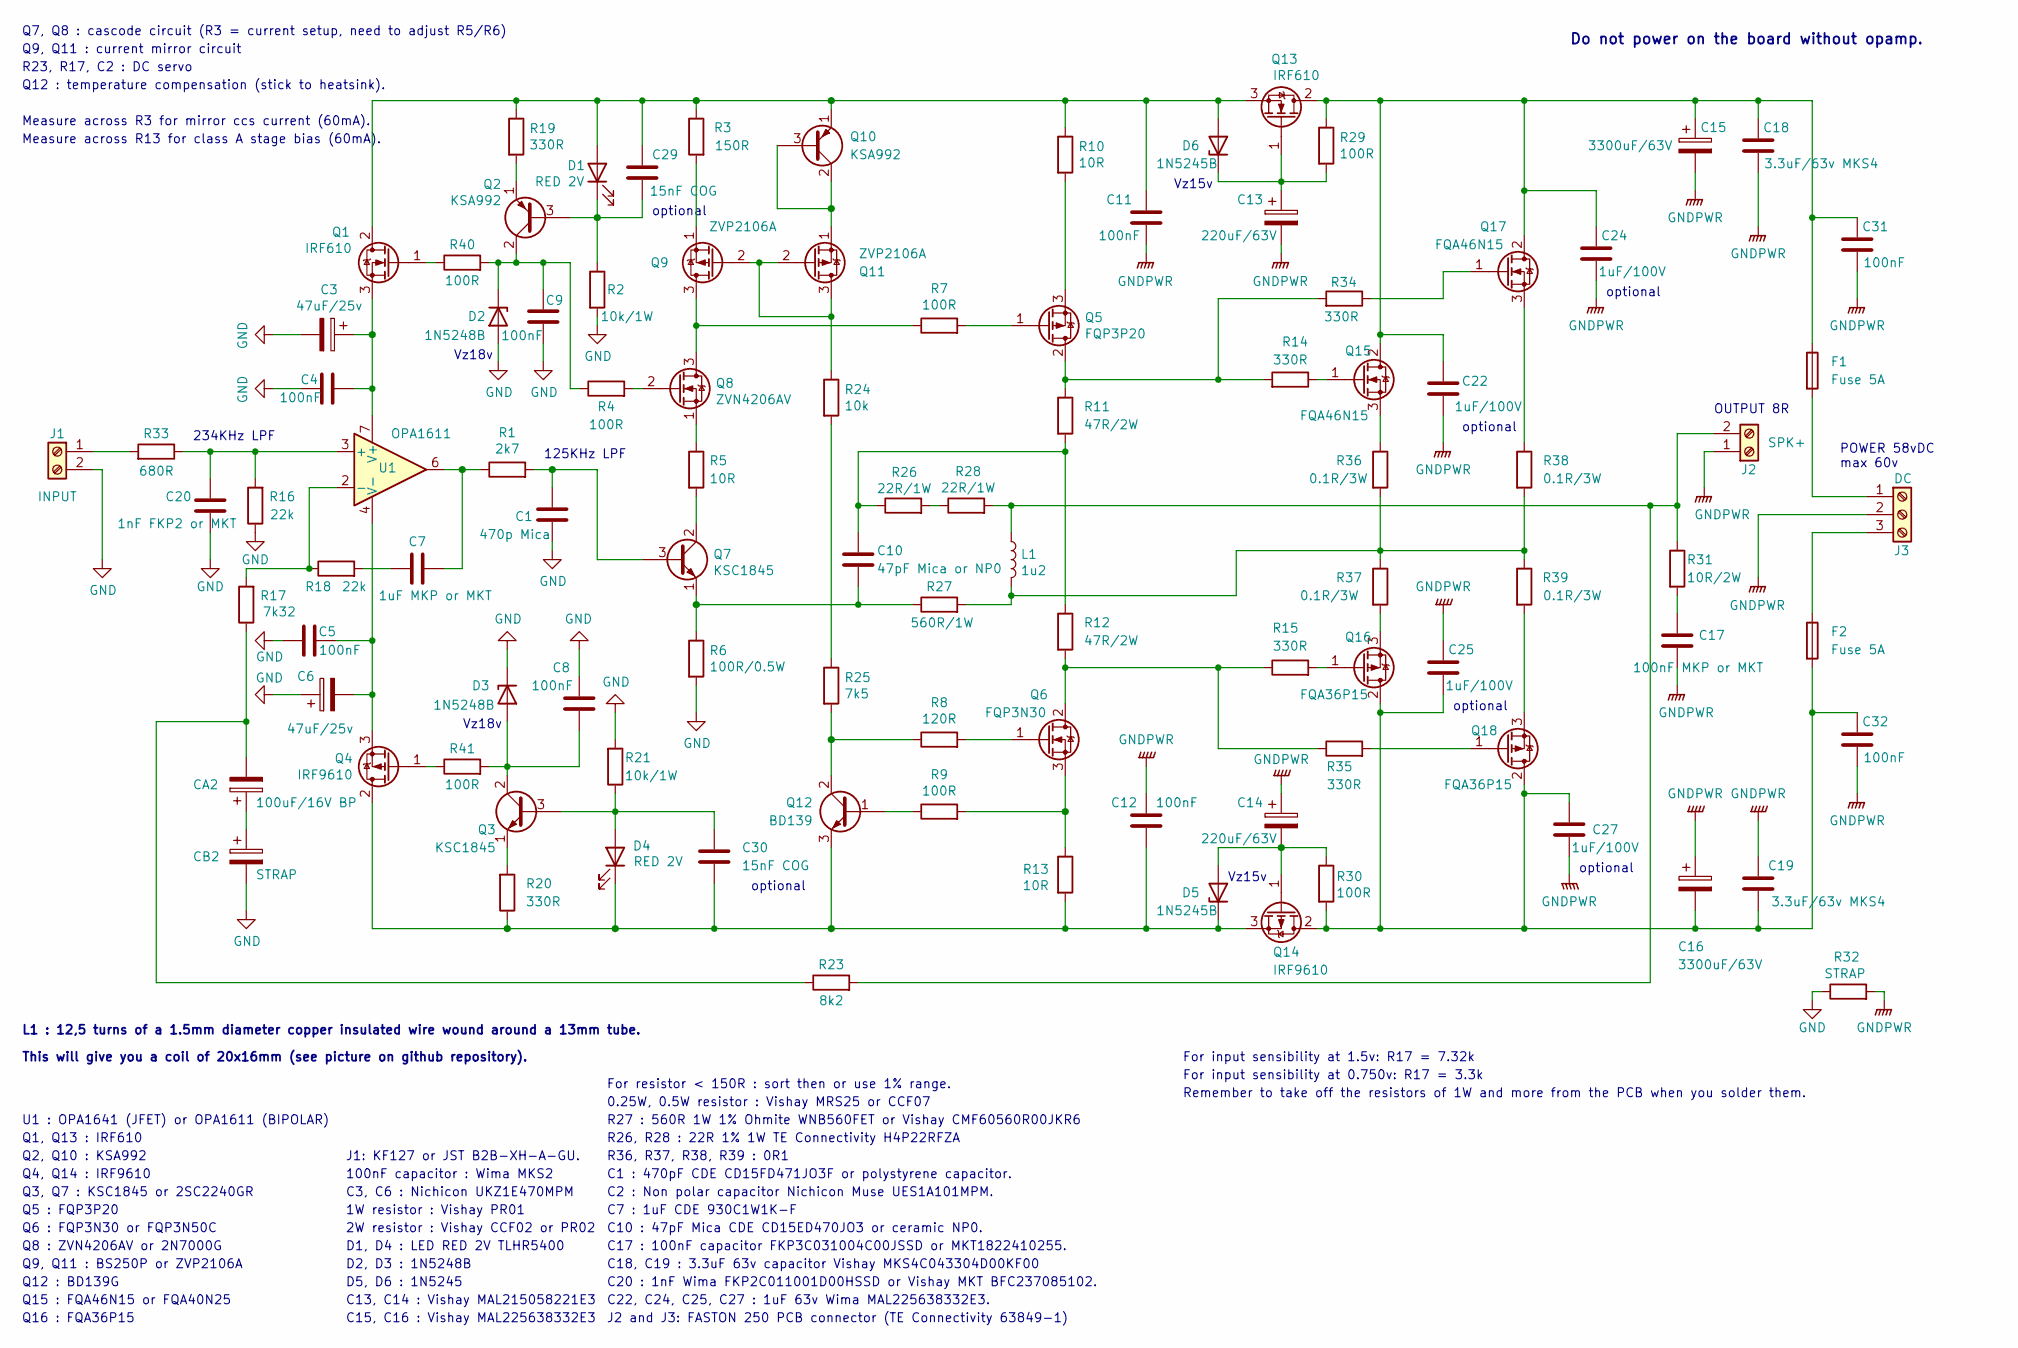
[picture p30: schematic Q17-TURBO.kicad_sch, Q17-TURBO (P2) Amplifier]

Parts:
C1: 470p Mica; C_Mica_v2_L11.4mm_W4.3mm_H9.1_P5.9mm_mix; Part# CD15FD471JO3F
C3, C6: 47uF/25v; CP_Radial_D10.0mm_P5.00mm; Part# Nichicon Muse UKZ1E470MPM
C4, C5, C8, C9, C11, C12, C31, C32: 100nF; C_Rect_L7.2mm_W2.5mm_P5.00mm_FKS2_FKP2_MKS2_MKP2; Part# MKS2D031001A00KSSD
C7: 1uF MKP or MKT; C_Rect_C7_Q17_Mini_L26.50_H11.00_P20.50_2; Part# CDE 930C1W1K-F
C10: 47pF Mica or NP0; C_Mica_v2_L11.4mm_W4.3mm_H9.1_P5.9mm_mix; Part# CD15ED470JO3
C13, C14: 220uF/63V; CP_Radial_D12.5mm_P5.00mm; Part# MAL215058221E3
C15, C16: 3300uF/63V; CP_Radial_D25.0mm_P10.00mm_SnapIn; Part# MAL225638332E3
C17: 100nF MKP or MKT; C_Rect_L18.0mm_W7.0mm_P15.00mm_C17; Part# FKP3D031004D00JF00
C18, C19: 3.3uF/63v MKS4; C_Rect_L18.0mm_W6.0mm_P15.00mm_FKS3_FKP3; Part# MKS4C043304D00KF00
C20: 1nF FKP2 or MKT; C_Mica_v2_L11.4mm_W4.3mm_H9.1_P5.9mm_mix; Part# FKP2D011001D00JSSD
C22, C24, C25, C27: 1uF/100V; C_Rect_L7.2mm_W7.2mm_P5.00mm_FKS2_FKP2_MKS2_MKP2; Part# MKS2D041001K00JSSD
C29, C30: 15nF COG; C_1206_3216Metric; Part# C3216NP01H153J060AA
CA2: 100uF/16V BP; CP_Radial_D10.0mm_P5.00mm; Part# UES1A101MPM
CB2: STRAP; CP_Radial_D10.0mm_P5.00mm; Part# STRAP
D1, D4: RED 2V; LED_D5.0mm; Part# TLHR5400
D2, D3: 1N5248B; D_DO-35_SOD27_P7.62mm_Horizontal; Part# 1N5248B
D5, D6: 1N5245B; D_DO-35_SOD27_P7.62mm_Horizontal; Part# 1N5245BTR
F1, F2: Fuse 5A; fuse_holder_CQ-2; Part# PCB fuse socket
J1: INPUT; Input_connector_mix_regular; Part# Terminal Block KF127 5mm 2P
J2: SPK+; AMASS_XT30U-F_1x02_P5.0mm_Vertical; Part# XT30 Male & Female Bullet Connector
J3: DC; TerminalBlock_Phoenix_PT-1,5-3-5.0-H_1x03_P5.00mm_Horizontal; Part# Terminal Block KF128 5mm 3P
L1: 1u2; L_Radial_D13mm_Q17_P2; Part# L1 : 12,5 turns of a 1.5mm diameter cop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
Q1, Q13: IRF610; TO-220-3_Vertical; Part# IRF610PBF
Q2, Q10: KSA992; TO-92_Inline_Wide; Part# KSA992FBTA
Q3, Q7: KSC1845; TO-92_Inline_Wide; Part# KSC1845FTA
Q4, Q14: IRF9610; TO-220-3_Vertical; Part# IRF9610PBF
Q5: FQP3P20; TO-220-3_Horizontal_TabDown_6mmHole; Part# FQP3P20
Q6: FQP3N30; TO-220-3_Horizontal_TabDown_6mmHole; Part# FQP3N30
Q8: ZVN4206AV; TO-92S_Wide; Part# ZVN4206AV
Q9, Q11: ZVP2106A; TO-92S_Wide; Part# ZVP2106A
Q12: BD139; BD139_Horizontal_TabDown; Part# BD139G
Q15, Q17: FQA46N15; TO-3PB-3_Horizontal_TabDown_6mmHole; Part# FQA46N15
Q16, Q18: FQA36P15; TO-3PB-3_Horizontal_TabDown_6mmHole; Part# FQA36P15
R1: 2k7; R_Axial_DIN0207_L6.3mm_D2.5mm_P10.16mm_Horizontal; Part# MRS25000C2701FCT00
R2, R21: 10k/1W; R_Axial_DIN0207_L6.3mm_D2.5mm_P10.16mm_Horizontal; Part# PR01000101002JR500
R3: 150R; R_Axial_DIN0207_L6.3mm_D2.5mm_P10.16mm_Horizontal; Part# MRS25000C1500FCT00
R4, R7, R9, R29, R30, R40, R41: 100R; R_Axial_DIN0207_L6.3mm_D2.5mm_P10.16mm_Horizontal; Part# MRS25000C1000FC100
R5, R10, R13: 10R; R_Axial_DIN0207_L6.3mm_D2.5mm_P10.16mm_Horizontal; Part# MRS25000C1009FCT00
R6: 100R/0.5W; R_Axial_DIN0207_L6.3mm_D2.5mm_P10.16mm_Horizontal; Part# MRS25000C1000FC100
R8: 120R; R_Axial_DIN0207_L6.3mm_D2.5mm_P10.16mm_Horizontal; Part# MRS25000C1200FCT
R11, R12: 47R/2W; R_Axial_DIN0411_L9.9mm_D3.6mm_P12.70mm_Horizontal; Part# CCF0247R0JKE36
R14, R15, R19, R20, R34, R35: 330R; R_Axial_DIN0207_L6.3mm_D2.5mm_P10.16mm_Horizontal; Part# MRS25000C3300FC1
R16, R18: 22k; R_Axial_DIN0207_L6.3mm_D2.5mm_P10.16mm_Horizontal; Part# MRS25000C2202FCT00
R17: 7k32; R_Axial_DIN0207_L6.3mm_D2.5mm_P10.16mm_Horizontal; Part# MF1/4CCT52R7321F
R23: 8k2; R_Axial_DIN0207_L6.3mm_D2.5mm_P10.16mm_Horizontal; Part# MRS25000C8201FCT
R24: 10k; R_Axial_DIN0207_L6.3mm_D2.5mm_P10.16mm_Horizontal; Part# MRS25000C1009FCT00
R25: 7k5; R_Axial_DIN0207_L6.3mm_D2.5mm_P10.16mm_Horizontal; Part# MRS25000C7501FCT00
R26, R28: 22R/1W; R_Axial_DIN0411_L9.9mm_D3.6mm_P12.70mm_Horizontal; Part# H4P22RFZA
R27: 560R/1W; R_Axial_DIN0411_L9.9mm_D3.6mm_P12.70mm_Horizontal; Part# WNB560FET
R31: 10R/2W; R_Axial_L12.0mm_D5.0mm_P15.24mm_Horizontal_Dale_1W; Part# PR02000201009JR500
R32: STRAP; R_Axial_DIN0207_L6.3mm_D2.5mm_P10.16mm_Horizontal; Part# STRAP
R33: 680R; R_Axial_DIN0207_L6.3mm_D2.5mm_P10.16mm_Horizontal; Part# MRS25000C6800FCT00
R36, R37: 0.1R/3W; R_Axial_DIN0614_L14.3mm_D5.7mm_P7.62mm_Vertical; Part# KOA MOSX3CT631RR10J
R38, R39: 0.1R/3W; R_Axial_DIN0614_L14.3mm_D5.7mm_P20.32mm_Horizontal; Part# KOA MOSX3CT631RR10J
U1: OPA1611; SOIC-8_3.9x4.9mm_P1.27mm; Part# OPA1611AID

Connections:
GND: C1.2, C3.2, C4.1, C5.1, C6.1, C8.1, C9.1, C20.1, CB2.2, D2.2 (A), D3.1 (K), J1.2, R2.2, R6.2, R16.1, R21.2, R32.1; also elsewhere on the board
GNDPWR: C11.1, C12.1, C13.2, C14.1, C15.2, C16.1, C17.2, C18.1, C19.2, C22.1, C24.1, C25.1, C27.1, C31.1, C32.1, J2.1, J3.2, R32.2
unnamed: C1.1, Q7.3 (B), R1.2
unnamed 3: C3.1, C4.2, Q1.3 (S), U1.7 (V+); also elsewhere on the board
unnamed 4: C5.2, C6.2, Q4.3 (S), U1.4 (V-); also elsewhere on the board
unnamed: C7.1, R18.2
unnamed 6: C7.2, R1.1, U1.6; also elsewhere on the board
unnamed: C8.2, D3.2 (A), Q3.2 (C), R41.2
unnamed: C9.2, D2.1 (K), Q2.2 (C), R4.1, R40.2
unnamed: C10.1, R11.2, R12.1, R26.1
unnamed: C10.2, Q7.1 (E), R6.1, R27.1
unnamed: C11.2, C29.1, D1.2 (A), D6.2 (A), Q1.2 (D), Q10.1 (E), Q13.3 (S), R3.1, R10.1, R19.1
unnamed: C12.2, C30.2, D4.1 (K), D5.1 (K), Q4.2 (D), Q12.3 (E), Q14.3 (S), R13.2, R20.1
unnamed: C13.1, D6.1 (K), Q13.1 (G), R29.2
unnamed: C14.2, D5.2 (A), Q14.1 (G), R30.1
unnamed: C15.1, C18.2, C22.2, C24.2, C31.2, F1.1, Q13.2 (D), Q15.2 (D), Q17.2 (D), R29.1
unnamed: C16.2, C19.1, C25.2, C27.2, C32.2, F2.2, Q14.2 (D), Q16.2 (D), Q18.2 (D), R30.2
unnamed: C17.1, R31.2
unnamed 18: C20.2, R16.2, R33.1, U1.3 (+); also elsewhere on the board
unnamed: C29.2, D1.1 (K), Q2.3 (B), R2.1
unnamed: C30.1, D4.2 (A), Q3.3 (B), R21.1
unnamed: CA2.1, CB2.1
unnamed: CA2.2, R17.1, R23.1
unnamed: F1.2, J3.1
unnamed: F2.1, J3.3
unnamed: J1.1, R33.2
unnamed: J2.2, L1.1, R23.2, R28.2, R31.1
unnamed: L1.2, R27.2, R36.2, R37.1, R38.2, R39.1
unnamed: Q1.1 (G), R40.1
unnamed: Q2.1 (E), R19.2
unnamed: Q3.1 (E), R20.2
unnamed: Q4.1 (G), R41.1
unnamed: Q5.1 (G), R7.2
unnamed: Q5.2 (D), R11.1, R14.2, R34.2
unnamed: Q5.3 (S), R10.2
unnamed: Q6.1 (G), R8.2
unnamed: Q6.2 (D), R12.2, R15.1, R35.1
unnamed: Q6.3 (S), R9.2, R13.1
unnamed: Q7.2 (C), R5.2
unnamed: Q8.1 (S), R5.1
unnamed: Q8.2 (G), R4.2
unnamed: Q8.3 (D), Q9.3 (D), R7.1
unnamed: Q9.1 (S), R3.2
unnamed: Q10.2 (C), Q10.3 (B), Q11.1 (S)
unnamed: Q9.2 (G), Q11.2 (G), Q11.3 (D), R24.1
unnamed: Q12.1 (B), R9.1
unnamed: Q12.2 (C), R8.1, R25.2
unnamed: Q15.1 (G), R14.1
unnamed: Q15.3 (S), R36.1
unnamed: Q16.1 (G), R15.2
unnamed: Q16.3 (S), R37.2
unnamed: Q17.1 (G), R34.1
unnamed: Q17.3 (S), R38.1
unnamed: Q18.1 (G), R35.2
unnamed: Q18.3 (S), R39.2
unnamed 55: R17.2, R18.1, U1.2 (-); also elsewhere on the board
unnamed: R24.2, R25.1
unnamed: R26.2, R28.1

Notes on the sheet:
D1, D4 : LED RED 2V TLHR5400
Do not power on the board without opamp.
C10 : 47pF Mica CDE CD15ED470JO3 or ceramic NP0.
C15, C16 : Vishay MAL225638332E3
Vz15v
R27 : 560R 1W 1% Ohmite WNB560FET or Vishay CMF60560R00JKR6
Q12 : BD139G
Q4, Q14 : IRF9610
C20 : 1nF Wima FKP2C011001D00HSSD or Vishay MKT BFC237085102.
D5, D6 : 1N5245
U1 : OPA1641 (JFET) or OPA1611 (BIPOLAR)
This will give you a coil of 20x16mm (see picture on github repository).
Q12 : temperature compensation (stick to heatsink).
Vz18v
C13, C14 : Vishay MAL215058221E3
C18, C19 : 3.3uF 63v capacitor Vishay MKS4C043304D00KF00
Q9, Q11 : BS250P or ZVP2106A
C1 : 470pF CDE CD15FD471JO3F or polystyrene capacitor.
J2 and J3: FASTON 250 PCB connector (TE Connectivity 63849-1)
optional
Q15 : FQA46N15 or FQA40N25
C17 : 100nF capacitor FKP3C031004C00JSSD or MKT1822410255.
R23, R17, C2 : DC servo
234KHz LPF
Q9, Q11 : current mirror circuit
Q1, Q13 : IRF610
OUTPUT 8R
Q3, Q7 : KSC1845 or 2SC2240GR
Q5 : FQP3P20
L1 : 12,5 turns of a 1.5mm diameter copper insulated wire wound around a 13mm tube.
C22, C24, C25, C27 : 1uF 63v Wima MAL225638332E3.
Q7, Q8 : cascode circuit (R3 = current setup, need to adjust R5/R6)
For input sensibility at 0.750v: R17 = 3.3k
C3, C6 : Nichicon UKZ1E470MPM
1W resistor : Vishay PR01
C7 : 1uF CDE 930C1W1K-F
D2, D3 : 1N5248B
Q6 : FQP3N30 or FQP3N50C
For input sensibility at 1.5v: R17 = 7.32k
J1: KF127 or JST B2B-XH-A-GU.

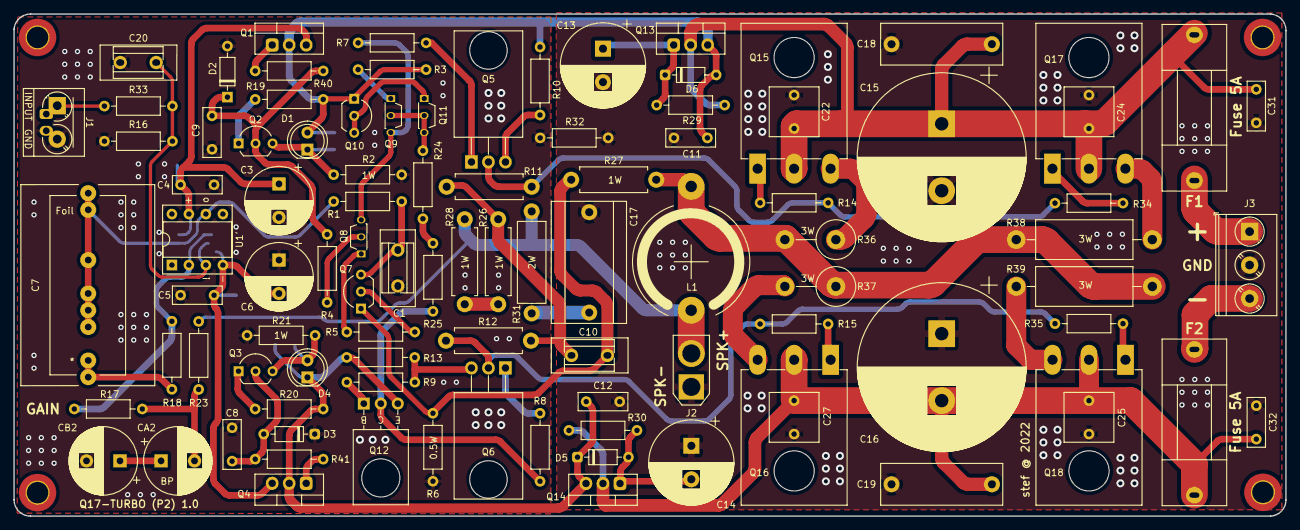
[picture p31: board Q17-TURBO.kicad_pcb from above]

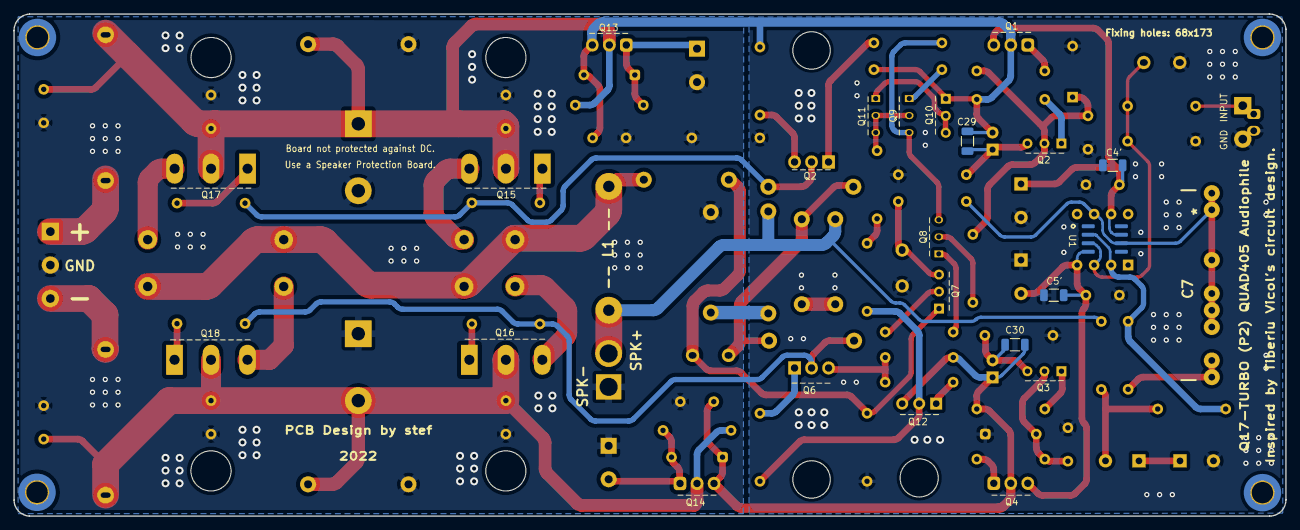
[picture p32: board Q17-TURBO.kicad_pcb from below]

Board: 2 copper layers, 190.0 x 75.0 mm, 107 parts (5 on the bottom side), 58 nets.

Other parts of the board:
C4': 100nF; C_1206_3216Metric
C5': 15nF COG; C_1206_3216Metric
H1, H1#2, H1#3, H1#4: MountingHole; MountingHole_3.2mm_M3_DIN965_Pad_TopBottom
U1': OPA1641; DIP-8_W7.62mm_Socket

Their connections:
GND: C4'.1, C5'.1; also elsewhere on the board
unnamed 3: C4'.2, U1'.7 (V+); also elsewhere on the board
unnamed 4: C5'.2, U1'.4 (V-); also elsewhere on the board
unnamed 6: U1'.6; also elsewhere on the board
unnamed 18: U1'.3 (+); also elsewhere on the board
unnamed 55: U1'.2 (-); also elsewhere on the board

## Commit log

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2021-11-12 BS250 footprint changed for Diodes
    There are at least two footprints for BS250 that may be confusing.
    Changes also include:
    Smooth traces.
    Reposition of few parts.
    Some traces have been enlarged.
    Coil was adjusted to take account for other traces with parasitic inductances.
    [Q17.kicad_pcb, Q17.kicad_sch]
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2021-11-13 PCB version 10b11
    - Precision timing of the fixing holes compared to the original PCB.
    - Displacement of R11 and R12.
    - Fixed various overlaps.
    [Q17-95x75.kicad_pcb]
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2021-11-14 Update PCB to 10b12
    - Changed footprint for KSC1845 (Q2, Q7 and Q12).
    - Updated transistors references on diagram and PCB.
    [Q17-95x75.kicad_pcb, Q17-95x75.kicad_sch]
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2021-11-15 Update PCB to 1.0b15
    - Change Q12 footprint to TO-126.
    - More cleanup of tracks.
    [Q17-95x75.kicad_pcb]
2021-11-15 PCB and diagram v1.0.b16
    - Replaced Q12 by BD139 and TO-126 footprint.
    - Optimisation of ground plane.
    - Add of missing R2 (yes after 16 beta!!).
    - Changed footprint of C7.
    - Add some 3D pictures.
    [Q17-95x75.kicad_pcb, Q17-95x75.kicad_sch]
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2021-11-16 PCB v1.0b18
    - C8 moved to a better place.
    - Faston connectors for SPK+, SPK- and GND moved to a better place.
    - New ground plane.
    - Change of 3D parts for capacitor.
    [Q17-95x75.kicad_pcb, Q17-Mini.kicad_pcb, Q17-Mini.kicad_sch]
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2021-11-17 PCB 1.0b20
    - New Faston PAD footprint + 3D view.
    - Removed old GND track.
    - More track optimisation.
    [Q17-Mini.kicad_pcb, Q17-Mini.kicad_sch]
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2021-11-17 PCB v1.0b21
    - New footprint for final 1.2uH air inductor.
    - Silver Mica capacitors with right footprint and 3D size.
    [Q17-Mini.kicad_pcb]
2021-11-17 Version 1.0
    - Version 1.0 of Q17-Mini PCB.
    - New footprint for C7 compatible with lead space of 15mm and 22.5mm.
    - L1 adjusted to the correct inductance length of 22x10mm for 1.2uF (Wire: 1mm, Tube: 8mm interior, 22 turns).
    - Gerber files for Q7-Mini 1.0.
    [Q17-Mini.kicad_pcb]
2021-11-18 Version 1.0.1
    - Wrong hole size for C7.
    [Q17-Mini.kicad_pcb]
2021-11-18 Update of Gerber files (wrong directory name). Same files.
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2021-11-19 PCB version 1.0.2
    - New footprint for C17 with lead space of 10mm.
    - Moved some track.
    [Q17-Mini.kicad_pcb]
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2021-11-20 Lot of DRC errors have been cleared
    There are few DRC errors left due castellated holes and inductor.
    [Q17.kicad_pcb, Q17.kicad_sch]
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2021-11-21 New update
    - corrected wrong path for 3D files
    - new 3D pictures
    [Q17-Mini.kicad_pcb]
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2021-11-22 PCB 1.0.5
    - new PCB and Gerber files.
    - new footprints for 1W and 2W resistors.
    - resistor power wrote on the PCB.
    - mods on schematic.
    - new 3D files.
    [Q17-Mini.kicad_pcb, Q17-Mini.kicad_sch]
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2021-11-23 PCB 1.0.6
    - Moved R21 and R13. R21 was too far from D4.
    - Moved some tracks.
    - Schematic 1.0.7.
    [Q17-Mini.kicad_pcb, Q17-Mini.kicad_sch]
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2021-11-24 Version 1.0.7
    - Mods on tracks.
    - Mods on ground plane.
    - Mods on C7 footprint.
    - New 3D picture.
    - Mods on schematic.
    [Q17-Mini.kicad_pcb]
2021-11-26 PCB v1.0.8
    - New track for SPK+ more direct and thick.
    - Some change on silkscreen layer.
    [Q17-Mini.kicad_pcb, Q17-Mini.kicad_sch]
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2021-11-26 PCB 1.0.8
    - New track for V+
    - Removed one VIA
    - Interchange R29 and R30
    - Moved track to R27
    [Q17-Mini.kicad_pcb]
2021-11-26 PCB 1.0.8
    - Moved R27
    - Moved C10
    - New footprint for R27
    [Q17-Mini.kicad_pcb]
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2021-11-27 PCB v1.0.8
    - New 3D model for L1
    - Some tracks mods
    - Some silkscreen mods.
    - Removed tracks inside PAD.
    [Q17-Mini.kicad_pcb]
2021-11-27 pcB v1.0.8
    - Move some tracks around Q15 and Q16.
    - Move Faston connectors for more space.
    [Q17-Mini.kicad_pcb]
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2021-11-30 Schematic 1.0.9
    Update C7 footprint (Pin 1 and 2 inverted).
    [Q17-Mini.kicad_sch]
2021-11-30 Schematic v1.1.0 and PCB v1.0.9
    - Corrected error for C2/C6. C2 is the BP capacitor not C6.
    - Changed silkscreen for C2/C6 on PCB.
    - New Q17-Mini-BOM and 3D pictures.
    - Inverted C1 to have the GND at the right place on the PCB.
    [Q17-Mini.kicad_pcb, Q17-Mini.kicad_sch]
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2021-11-30 PCB v1.0.9
    - Moved D5 which was not well aligned.
    - Changed pinout numbering of Faston connector, C7 and C17.
    [Q17-Mini.kicad_pcb]
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2021-11-30 PCB v1.0.9
    Moved Q15 and Q16 inward a bit to change the border track to 3mm.
    [Q17-Mini.kicad_pcb, Q17-Mini.kicad_sch]
2021-11-30 PCB v1.0.9
    Pushed wrong files.
    [Q17-Mini.kicad_pcb]
2021-11-30 Update Gerber-Q17-Mini 1.0.9.zip
    Pushed wrong file.
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2021-12-02 PCB v1.0.9
    - Moved and changed footprint for R26, R27 and R28. Will fit Dale 1W now.
    - Moved C10.
    - Align Watt text inside footprints.
    [Q17-Mini.kicad_pcb]
2021-12-02 PCB V1.0.9
    - Added 5mm spacing PAD for C7.
    - Changed footprint for R1.
    - Moved C10 and R31.
    - Optimized some tracks.
    [Q17-Mini.kicad_pcb]
2021-12-02 PCB V1.0.9
    - Add mark on C7 and C17 silkscreen.
    - Cleanup around GND border.
    [Q17-Mini.kicad_pcb]
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2021-12-04 PCB V1.0.9
    - Add warning about DC on back PCB.
    - Align ground plane.
    - More reference components in schematic.
    [Q17-Mini.kicad_pcb, Q17-Mini.kicad_sch]
2021-12-05 PCB v1.0.9
    - Add a warning about DC on back of PCB.
    - Some tracks optimisation.
    [Q17-Mini.kicad_pcb, Q17-Mini.kicad_sch]
2021-12-06 PCB V1.0.9
    - New footprint for CA1 (DC version).
    - Enlarge tracks.
    [Q17-Mini.kicad_pcb, Q17-Mini.kicad_sch]
2021-12-06 PCB v1.0.9
    New footprint for C7.
    Now support 5, 7.5, 10, 15 et 22.5 mm pitch.
    [Q17-Mini.kicad_pcb]
2021-12-07 PCB V1.0.9
    - New footprint for Q8, Q9 and Q11.
    - Enlarge PCB holes for Faston connector.
    [Q17-Mini.kicad_pcb]
2021-12-08 PCB v1.0.9
    - Moved Q8 and deleted a track on back PCB.
    - Some comments added on schematic.
    [Q17-Mini.kicad_pcb, Q17-Mini.kicad_sch]
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2021-12-09 PCB v1.1.0 PRODUCTION
    Second upload. Forgot to remove "PROTOTYPE EDITION" on back of PCB.
    [Q17-Mini.kicad_pcb]
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2021-12-10 PCB V1.1.1 PRODUCTION
    Corrected wrong pinout footprint of Q12 (BD139).
    [Q17-Mini.kicad_pcb, Q17-Mini.kicad_sch]
2021-12-11 Update Q17-Mini.kicad_sch
    Add values for Exicon devices.
    Add ref for 2W resistors.
    [Q17-Mini.kicad_sch]
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2021-12-12 Update Q17-Mini schematic 1.1.4 - IMPORTANT
    ERROR on R29 and R30: right value is 10K not 10R.
    [Q17-Mini.kicad_sch]
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2022-01-04 Q17-Mini-1.1.2 release
    - New vertical footprint for coil
    - New SMD footprints on back PCB
    - Update C7/R18 circuit position
    - Some tracks optimisation
    - New 3D and PCB pictures
    - Archived version 1.1.1
    [Q17-Mini.kicad_pcb, Q17-Mini.kicad_sch, Q17.kicad_pcb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]
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2022-01-08 Q17-P2 v1.0.2
    Corrected small errors on silkscreen.
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2022-01-13 Update Q17-Mini v1.1.4
    - Add C29 and C30.
    - Add R42 and R43.
    [Q17-Mini.kicad_pcb, Q17-Mini.kicad_sch, Q17.kicad_pcb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]
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2022-08-22 Various updates
    - more stable simulation.
    - passed C2A and C2B at 63v (they flash red now).
    - replaced model for C1, C10 and C20 (initial condition set to 0).
    - replaced C3 and C6 by 47uF.
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2023-07-31 Removed Q17-Turbo 1.2 files
    Temporary deletion of Q17-Turbo 1.2 files due to a problem with the files. Sorry.
    [Q17-TURBO.kicad_pcb, Q17-TURBO.kicad_sch]
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2024-04-15 Update Gerber files (missing drill)
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2024-09-27 Fixing Plate-Q17-Turbo-216x80-1.0
    [Fixing Plate-Q17-Turbo-216x80-1.0.dxf]
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
